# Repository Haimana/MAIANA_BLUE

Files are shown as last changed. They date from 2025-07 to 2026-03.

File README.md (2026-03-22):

# MAIANA BLUE

Firmware and hardware materials for the MAIANA-class AIS transponder ecosystem. The design builds on the open [MAIANA project](https://github.com/peterantypas/maiana) (GPL v3, Peter Antypas).

## In this repository

- **Firmware/** — AIS firmware (STM32CubeIDE tree and a **VS Code / PlatformIO** sibling), plus the N2K variant. Start with [Firmware/README.md](Firmware/README.md) for layout and build pointers.
- **CAD/** — STEP models (enclosures, antennas).
- **Manuals/** — Assembly and related documentation.
- **Schematics/** — Hardware reference drawings.

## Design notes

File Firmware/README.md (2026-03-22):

# Firmware layout

- **`Maiana_Blue_AIS_Firmware`** — Original AIS transponder tree (STM32CubeIDE / Eclipse-style project: `.ioc`, OpenOCD scripts). Kept for reference and existing workflows.

- **`Maiana_Blue_AIS_Firmware_VSCode_PlatformIO`** — Same application line built with **VS Code + PlatformIO** (`platformio.ini`). Use this tree for `pio run` / multi-environment builds. Build artifacts (`.pio/`) are ignored by git.

- **`Maiana_Blue_N2K_Firmware`** — N2K variant (unchanged).

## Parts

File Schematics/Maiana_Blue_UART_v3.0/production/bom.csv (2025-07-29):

Designator | Footprint | Quantity | Value | LCSC Part #
C1, C2 | 0603 | 2 | 1uF
C4, C5 | 0603 | 2 | 0.1uF
D1 | SMB-BIDIR | 1 | SMBJ14CA
D2 | SOD123 | 1 | WSB5508L-2/TR
D3 | SOD-323 | 1 | 3V
F1 | R1206 | 1 | BSMD1206-050-16V
J3 | USB_Micro-B_Amphenol_10118194-0001LF_Horizontal | 1 | 10118194-0001LF
R8 | 0603 | 1 | 75R
U$1 | SOIC-8 | 1 | CH340N
U1 | SOT23 | 1 | SE8533X2-HF

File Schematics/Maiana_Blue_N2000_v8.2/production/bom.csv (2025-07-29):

Designator | Footprint | Quantity | Value | LCSC Part #
C1, C11, C12, C13, C2, C3 | 0603 | 6 | 0.1uF
C10, C6, C7, C8, C9 | 0603 | 5 | 1uF
C4, C5 | 0603 | 2 | 20pF
D5 | SOT323 | 1 | PESD1CAN-U
D6 | DIOM4336X265N | 1 | SMBJ16CA
D8 | D_SOD-123 | 1 | D_Schottky
GPS1, PWR1, RX1, TX1 | 0805 | 4 | KT-0805G
J3 | USB_Micro-B_Amphenol_10118194_Horizontal | 1 | USB_B_Micro
Q1, Q3 | SOT-23 | 2 | BSS138
Q2 | SOT-23 | 1 | AO3401A
R1, R2, R3, R4 | 0603 | 4 | 2k2
R10, R5, R6, R7, R8, R9 | 0603 | 6 | 10k
R11, R12 | 0603 | 2 | 0R
S1, S2 | MS12D17G2 | 2 | MS-12D17-G2
S3 | SKSCLDE010 | 1 | SKSCLDE010
TH1 | 1206 | 1 | BSMD1206-050-16V
U1 | QFN-32-1EP_5x5mm_P0.5mm_EP3.45x3.45mm | 1 | STM32L432KBUx
U2 | TSSOP-20_4.4x6.5mm_P0.65mm | 1 | MCP2515-xST
U3 | SOIC-8_3.9x4.9mm_P1.27mm | 1 | MCP2551-I-SN
U4 | SOT-23-6 | 1 | SRV05-4
U5 | SO-8_3.9x4.9mm_P1.27mm | 1 | CH340N
U6 | SOIC-8_3.9x4.9mm_P1.27mm | 1 | ISO7721FDR
U7 | SOT-23-5 | 1 | TJ5205SF5-5.0
U8 | SOT-23 | 1 | SE8533X2-HF
Y1 | Crystal_SMD_3225-4Pin_3.2x2.5mm | 1 | X322516MOB4SI

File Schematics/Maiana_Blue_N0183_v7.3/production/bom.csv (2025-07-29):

Designator | Footprint | Quantity | Value | LCSC Part #
C1, C10, C11, C2, C3, C9 | 0603 | 6 | 0.1uF
C4, C5, C6, C7, C8 | 0603 | 5 | 1uF
D1 | D_SOD-123 | 1 | WSB5508L-2/TR
D2 | D_SMB | 1 | SMBJ16CA
GPS1, PWR1, RX1, TX1 | 0805 | 4 | KT-0805G
J1 | 1727036 | 1 | 1727036
J3 | USB_Micro-B_Amphenol_10118194_Horizontal | 1 | USB_B_Micro
J5 | RJ45_Amphenol_54602-x08_Horizontal | 1 | 54602-908LF
Q1 | SOT-23 | 1 | BSS138
Q2 | SOT-23 | 1 | AO3401A
R1, R2 | 0603 | 2 | 10k
R10, R11, R12, R9 | 0603 | 4 | 2k2
S3, S4 | MS12D17G2 | 2 | MS-12D17-G2
TH1 | 1206 | 1 | Thermistor_PTC
U1 | SOT-23-6 | 1 | SRV05-4
U2 | SO-8_3.9x4.9mm_P1.27mm | 1 | CH340N
U3 | SOIC-8_3.9x4.9mm_P1.27mm | 1 | ADuM121N
U4 | SOT-23-5 | 1 | TJ5205SF5-5.0
U5 | SOT-23 | 1 | SE8533X2-HF
U6 | SOIC-8_3.9x4.9mm_P1.27mm | 1 | DS8921M

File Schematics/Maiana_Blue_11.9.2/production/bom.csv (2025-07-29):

Designator | Footprint | Quantity | Value | LCSC Part #
AE1 | ANT_1575AT_JOT | 1 | 1575AT43A0040E
C1, C2, C8, C9 | 0603 | 4 | 0.1uf
C12, C16, C17, C21, C29, C5 | 0603 | 6 | 22nF
C13, C14, C15, C4, C7 | 0603 | 5 | 2.2uF
C18, C19, C24 | 0603 | 3 | 91pF
C20, C22, C30, C35 | 0603 | 4 | 2.2nF
C23, C25 | 0603 | 2 | 3.3pF
C26 | 0603 | 1 | 20pF
C27, C32 | 0603 | 2 | 470pF
C28 | 0603 | 1 | 16pF
C3 | 0805 | 1 | 10uF
C31, C33 | 0603 | 2 | 110pF
C34 | 0603 | 1 | 36pF
C6 | 0805 | 1 | 22uF
CR1 | U-DFN3810-9TYPE_B_DIO | 1 | D3V3X8U9LP3810-7
D1, D2, D3 | D_SOD-323 | 3 | BAT54WS
IC1 | SON65P200X200X100-7N-D | 1 | LDFPVR
J1 | RJ45_Amphenol_54602-x08_Horizontal | 1 | RJ45
J3 | RFSOLUTIONS_CON-SMA-EDGE-S | 1 | CON-SMA-EDGE-S
L1, L2 | 0805 | 2 | 4.7uH
L10 | 0603 | 1 | 20nH
L11, L7 | 0603 | 2 | 470nH
L12 | 0805 | 1 | 2.2uH
L13 | 0603 | 1 | 13nH
L14 | 0603 | 1 | 39nH
L3 | 0603 | 1 | 5.6nH
L4, L6 | 0603 | 2 | 270nH
L5 | 0603 | 1 | 10nH
L8 | 0603 | 1 | 47nH
L9 | 0603 | 1 | 68nH
Q1 | SOT-23 | 1 | AO3409
Q2 | SOT-23 | 1 | AO3401A
Q3 | SOT-89-3 | 1 | AFT05MS004NT1
R1, R2, R3 | 0603 | 3 | 100R
R10 | 0603 | 1 | 47k
R11, R12, R13, R18, R4 | 0603 | 5 | 10k
R14 | 0603 | 1 | 0
R15 | 0603 | 1 | 220R
R16 | 0603 | 1 | 22R
R17 | 0603 | 1 | 3k3
R5, R6, R7 | 0603 | 3 | 1k
R8 | 0603 | 1 | 51k
R9 | 0603 | 1 | 16k
TP1, TP10, TP11, TP12, TP14, TP15, TP16, TP17, TP18, TP19, TP2, TP3, TP4, TP5, TP6, TP7, TP8, TP9 | TP_1.2MM | 18 | ~
TP13 | TP_1.0MM | 1 | ~
U1, U2 | SOT-363_SC-70-6 | 2 | SI1926DL-T1-E3
U10 | QFN50P200X200X65-13N | 1 | SKY13330-397LF
U3 | SOT-23-6 | 1 | AP3211K
U4 | SOT-23-5 | 1 | 24LC01BT/OT
U5 | QFN-32-1EP_5x5mm_P0.5mm_EP3.45x3.45mm | 1 | STM32L432KBUx
U6 | XCVR_L76L-M33 | 1 | L76L-M33
U7, U8 | QFN-20-1EP_4x4mm_P0.5mm_EP2.6x2.6mm_ThermalVias | 2 | Si4460
U9 | SOT-363_SC-70-6 | 1 | BGA2800,115
Y1, Y2 | Crystal_SMD_3225-4Pin_3.2x2.5mm | 2 | ECS-300-10-33B-CKM-TR

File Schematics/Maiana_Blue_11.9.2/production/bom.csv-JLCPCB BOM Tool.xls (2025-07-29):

JLCPCB BOM Tool - BOM Matching
BOM name：bom_base_11.9.2-JLCPCB Assembly Order.xlsx |  |  |  | Download Time：2025-05-29 18:24:59 |  |  |  | * Our matching results are updated in real-time, but stock and prices may change. If it's been over 24 hours, please re-match before placing your order.
PCB Assembled Qty：25 |  |  |  | Est. Total Price：731.6358 (Pre-order parts require a quotation for final pricing.)
Your BOM |  |  |  | Matched Parts |  |  |  |  |  |  | Order Information
Designator | Comment | Footprint | JLCPCB Part # | Matches | Part # | Manufacturer | Footprint | Description | Category | Warning | JLCPCB Part # | Product link | Source | Lib Type | MOQ | Availability | My Parts(JLCPCB Parts) | My Parts(Global sourcing & consigned parts) | Rec. Order Qty | Unit Price ($) | Total Price ($)
C26 | 20pF | 0603 |  | Unconfirmed | CL10C200JB8NNNC | Samsung Electro-Mechanics | 0603 | 50V 20pF C0G ±5% 0603 Multilayer Ceramic Capacitors MLCC - SMD/SMT ROHS | Multilayer Ceramic Capacitors MLCC - SMD/SMT | 1.The comment (CL10C200JB8NNNC) of this part does not match the one (20pF) provided in your BOM. Please confirm; | C1648 | https://jlcpcb.com/partdetail/2000-CL10C200JB8NNNC/C1648 | In-stock | Basic | 1 | 781306 | 0 | 0 | 35 | 0.0054 | 0.189
R16 | 22R | 0603 |  | Unconfirmed | 0603WAF220JT5E | UNI-ROYAL(Uniroyal Elec) | 0603 | 100mW Thick Film Resistors 75V ±100ppm/℃ ±1% 22Ω 0603 Chip Resistor - Surface Mount ROHS | Chip Resistor - Surface Mount | 1.The comment (0603WAF220JT5E) of this part does not match the one (22R) provided in your BOM. Please confirm; | C23345 | https://jlcpcb.com/partdetail/24078-0603WAF220JT5E/C23345 | In-stock | Basic | 1 | 2988484 | 0 | 0 | 35 | 0.0009 | 0.0315
C3 | 10uF | 0805 |  | Unconfirmed | CL21A106KAYNNNE | Samsung Electro-Mechanics | 0805 | 25V 10uF X5R ±10% 0805 Multilayer Ceramic Capacitors MLCC - SMD/SMT ROHS | Multilayer Ceramic Capacitors MLCC - SMD/SMT | 1.The comment (CL21A106KAYNNNE) of this part does not match the one (10uF) provided in your BOM. Please confirm; | C15850 | https://jlcpcb.com/partdetail/16532-CL21A106KAYNNNE/C15850 | In-stock | Basic | 1 | 7327774 | 0 | 0 | 35 | 0.0106 | 0.371
U4 | 24LC01BT/OT | SOT-23-5 |  | Unconfirmed | 24LC01BT-I/OT | Microchip Tech | SOT-23-5 | 1Kbit I2C SOT-23-5 EEPROM ROHS | EEPROM | 1.The comment (24LC01BT-I/OT) of this part does not match the one (24LC01BT/OT) provided in your BOM. Please confirm; | C511269 | https://jlcpcb.com/partdetail/MicrochipTech-24LC01BT_IOT/C511269 | In-stock | Extended | 1 | 3500 | 0 | 0 | 25 | 0.3381 | 8.4525
U3 | AP3211K | SOT-23-6 |  | Unconfirmed | AP3211KTR-G1 | Diodes Incorporated | SOT-23-6 | Step-down type Adjustable 810mV~15V 1.5A 4.5V~18V SOT-23-6 DC-DC Converters ROHS | DC-DC Converters | 1.The comment (AP3211KTR-G1) of this part does not match the one (AP3211K) provided in your BOM. Please confirm; | C154863 | https://jlcpcb.com/partdetail/DiodesIncorporated-AP3211KTRG1/C154863 | In-stock | Extended | 1 | 3015 | 0 | 0 | 25 | 0.17 | 4.25
C23,C25 | 3.3pF | 0603 |  | Unconfirmed | 0603CG3R3C500NT | FH (Guangdong Fenghua Advanced Tech) | 0603 | 50V 3.3pF C0G 0603 Multilayer Ceramic Capacitors MLCC - SMD/SMT ROHS | Multilayer Ceramic Capacitors MLCC - SMD/SMT | 1.The comment (0603CG3R3C500NT) of this part does not match the one (3.3pF) provided in your BOM. Please confirm; | C1660 | https://jlcpcb.com/partdetail/2012-0603CG3R3C500NT/C1660 | In-stock | Extended | 1 | 95763 | 0 | 0 | 60 | 0.0028 | 0.168
L4,L6 | 270nH | 0603 |  | Select by Customer | LQW18ANR27G00D | Murata Electronics | 0603 | 110mA 270nH ±2% 0603 Power Inductors ROHS | Power Inductors | 1.The comment (LQW18ANR27G00D) of this part does not match the one (270nH) provided in your BOM. Please confirm; | C98092 | https://jlcpcb.com/partdetail/MurataElectronics-LQW18ANR27G00D/C98092 | In-stock | Extended | 1 | 2820 | 0 | 0 | 54 | 0.0356 | 1.9224
L12 | 2.2uH | 0805 |  | Unconfirmed | LQM21PN2R2NGCD | Murata Electronics | 0805 | 800mA 2.2uH ±30% 288mΩ 0805 Inductors (SMD) ROHS | Inductors (SMD) | 1.The comment (LQM21PN2R2NGCD) of this part does not match the one (2.2uH) provided in your BOM. Please confirm; | C86089 | https://jlcpcb.com/partdetail/MurataElectronics-LQM21PN2R2NGCD/C86089 | In-stock | Extended | 1 | 2622 | 0 | 0 | 29 | 0.0593 | 1.7197
L1,L2 | 4.7uH | 0805 |  | Unconfirmed | LQM21PN4R7MGRD | Murata Electronics | 0805 | 800mA 4.7uH ±20% 288mΩ 0805 Inductors (SMD) ROHS | Inductors (SMD) | 1.The comment (LQM21PN4R7MGRD) of this part does not match the one (4.7uH) provided in your BOM. Please confirm; | C86090 | https://jlcpcb.com/partdetail/MurataElectronics-LQM21PN4R7MGRD/C86090 | In-stock | Extended | 1 | 13173 | 0 | 0 | 54 | 0.0687 | 3.7098
C18,C19,C24 | 91pF | 0603 |  | Unconfirmed | 0603CG910J500NT | FH (Guangdong Fenghua Advanced Tech) | 0603 | 50V 91pF C0G ±5% 0603 Multilayer Ceramic Capacitors MLCC - SMD/SMT ROHS | Multilayer Ceramic Capacitors MLCC - SMD/SMT | 1.The comment (0603CG910J500NT) of this part does not match the one (91pF) provided in your BOM. Please confirm; | C1686 | https://jlcpcb.com/partdetail/2038-0603CG910J500NT/C1686 | In-stock | Extended | 1 | 3912 | 0 | 0 | 85 | 0.0033 | 0.2805
U1,U2 | SI1926DL-T1-E3 | SOT-363_SC-70-6 |  | Select by System | SI1926DL-T1-E3 | Vishay Intertech | SOT-363_SC-70-6 | 60V 370mA 1.4Ω@340mA,10V 510mW 2.5V@250uA 2 N-Channel SOT-363-6 MOSFETs ROHS | MOSFETs |  | C727310 | https://jlcpcb.com/partdetail/VishayIntertech-SI1926DL_T1E3/C727310 | In-stock | Extended | 1 | 198 | 0 | 0 | 50 | 0.2211 | 11.055
R5,R6,R7 | 1k | 0603 |  | Unconfirmed | 0603WAF1001T5E | UNI-ROYAL(Uniroyal Elec) | 0603 | 100mW Thick Film Resistors 75V ±100ppm/℃ ±1% 1kΩ 0603 Chip Resistor - Surface Mount ROHS | Chip Resistor - Surface Mount | 1.The comment (0603WAF1001T5E) of this part does not match the one (1k) provided in your BOM. Please confirm; | C21190 | https://jlcpcb.com/partdetail/21904-0603WAF1001T5E/C21190 | In-stock | Basic | 1 | 20095357 | 0 | 0 | 85 | 0.001 | 0.085
C20,C22,C30,C35 | 2.2nF | 0603 |  | Unconfirmed | 0603B222K500NT | FH (Guangdong Fenghua Advanced Tech) | 0603 | 50V 2.2nF X7R ±10% 0603 Multilayer Ceramic Capacitors MLCC - SMD/SMT ROHS | Multilayer Ceramic Capacitors MLCC - SMD/SMT | 1.The comment (0603B222K500NT) of this part does not match the one (2.2nF) provided in your BOM. Please confirm; | C1604 | https://jlcpcb.com/partdetail/1956-0603B222K500NT/C1604 | In-stock | Basic | 1 | 957178 | 0 | 0 | 110 | 0.0026 | 0.286
C6 | 22uF | 0805 |  | Unconfirmed | CL21A226MAQNNNE | Samsung Electro-Mechanics | 0805 | 25V 22uF X5R ±20% 0805 Multilayer Ceramic Capacitors MLCC - SMD/SMT ROHS | Multilayer Ceramic Capacitors MLCC - SMD/SMT | 1.The comment (CL21A226MAQNNNE) of this part does not match the one (22uF) provided in your BOM. Please confirm; | C45783 | https://jlcpcb.com/partdetail/46786-CL21A226MAQNNNE/C45783 | In-stock | Basic | 1 | 1402442 | 0 | 0 | 33 | 0.027 | 0.891
R8 | 51k | 0603 |  | Unconfirmed | 0603WAF5102T5E | UNI-ROYAL(Uniroyal Elec) | 0603 | 100mW Thick Film Resistors 75V ±100ppm/℃ ±1% 51kΩ 0603 Chip Resistor - Surface Mount ROHS | Chip Resistor - Surface Mount | 1.The comment (0603WAF5102T5E) of this part does not match the one (51k) provided in your BOM. Please confirm; | C23196 | https://jlcpcb.com/partdetail/23923-0603WAF5102T5E/C23196 | In-stock | Basic | 1 | 3648305 | 0 | 0 | 35 | 0.001 | 0.035
L8 | 47nH | 0603 |  | Unconfirmed | LQW18AN47NG00D | Murata Electronics | 0603 | 380mA 47nH ±2% 0603 Power Inductors ROHS | Power Inductors | 1.The comment (LQW18AN47NG00D) of this part does not match the one (47nH) provided in your BOM. Please confirm; | C98076 | https://jlcpcb.com/partdetail/MurataElectronics-LQW18AN47NG00D/C98076 | In-stock | Extended | 1 | 19109 | 0 | 0 | 29 | 0.0399 | 1.1571
R14 | 0 | 0603 |  | Unconfirmed | 0603WAF0000T5E | UNI-ROYAL(Uniroyal Elec) | 0603 | 100mW Thick Film Resistors 75V ±1% 0Ω 0603 Chip Resistor - Surface Mount ROHS | Chip Resistor - Surface Mount | 1.The comment (0603WAF0000T5E) of this part does not match the one (0) provided in your BOM. Please confirm; | C21189 | https://jlcpcb.com/partdetail/21903-0603WAF0000T5E/C21189 | In-stock | Basic | 1 | 15465613 | 0 | 0 | 35 | 0.001 | 0.035
L13 | 13nH | 0603 |  | Unconfirmed | LQW18AN13NG00D | Murata Electronics | 0603 | 600mA 13nH ±2% 0603 Power Inductors ROHS | Power Inductors | 1.The comment (LQW18AN13NG00D) of this part does not match the one (13nH) provided in your BOM. Please confirm; | C701184 | https://jlcpcb.com/partdetail/MurataElectronics-LQW18AN13NG00D/C701184 | In-stock | Extended | 1 | 2781 | 0 | 0 | 29 | 0.036 | 1.044
L5 | 10nH | 0603 |  | Unconfirmed | LQW18AN10NG00D | Murata Electronics | 0603 | 650mA 10nH ±2% 0603 Power Inductors ROHS | Power Inductors | 1.The comment (LQW18AN10NG00D) of this part does not match the one (10nH) provided in your BOM. Please confirm; | C86131 | https://jlcpcb.com/partdetail/MurataElectronics-LQW18AN10NG00D/C86131 | In-stock | Extended | 1 | 95789 | 0 | 0 | 29 | 0.0359 | 1.0411
R15 | 220R | 0603 |  | Unconfirmed | 0603WAF2200T5E | UNI-ROYAL(Uniroyal Elec) | 0603 | 100mW Thick Film Resistors 75V ±100ppm/℃ ±1% 220Ω 0603 Chip Resistor - Surface Mount ROHS | Chip Resistor - Surface Mount | 1.The comment (0603WAF2200T5E) of this part does not match the one (220R) provided in your BOM. Please confirm; | C22962 | https://jlcpcb.com/partdetail/23689-0603WAF2200T5E/C22962 | In-stock | Basic | 1 | 1267513 | 0 | 0 | 35 | 0.0011 | 0.0385
Q1 | AO3409 | SOT-23 |  | Select by System | AO3409 | Alpha & Omega Semicon | SOT-23 | 30V 2.6A 130mΩ@10V,2.6A 1.4W 3V@250uA 1 Piece P-Channel SOT-23 MOSFETs ROHS | MOSFETs |  | C88052 | https://jlcpcb.com/partdetail/Alpha_OmegaSemicon-AO3409/C88052 | In-stock | Extended | 1 | 905 | 0 | 0 | 27 | 0.0761 | 2.0547
C28 | 16pF | 0603 |  | Unconfirmed | CC0603JRNPO9BN160 | YAGEO | 0603 | 50V 16pF NP0 ±5% 0603 Multilayer Ceramic Capacitors MLCC - SMD/SMT ROHS | Multilayer Ceramic Capacitors MLCC - SMD/SMT | 1.The comment (CC0603JRNPO9BN160) of this part does not match the one (16pF) provided in your BOM. Please confirm; | C327125 | https://jlcpcb.com/partdetail/YAGEO-CC0603JRNPO9BN160/C327125 | In-stock | Extended | 1 | 120909 | 0 | 0 | 35 | 0.0029 | 0.1015
C27,C32 | 470pF | 0603 |  | Unconfirmed | 0603B471K500NT | FH (Guangdong Fenghua Advanced Tech) | 0603 | 50V 470pF X7R ±10% 0603 Multilayer Ceramic Capacitors MLCC - SMD/SMT ROHS | Multilayer Ceramic Capacitors MLCC - SMD/SMT | 1.The comment (0603B471K500NT) of this part does not match the one (470pF) provided in your BOM. Please confirm; | C1620 | https://jlcpcb.com/partdetail/1972-0603B471K500NT/C1620 | In-stock | Basic | 1 | 533202 | 0 | 0 | 60 | 0.0027 | 0.162
U5 | STM32L432KBUx | QFN-32-1EP_5x5mm_P0.5mm_EP3.45x3.45mm |  | Select by System | STM32L432KBU6 | STMicroelectronics | QFN-32-1EP_5x5mm_P0.5mm_EP3.45x3.45mm | 128KB 1.71V~3.6V ARM-M4 64KB 80MHz FLASH 26 UFQFPN-32(5x5) Microcontrollers (MCU/MPU/SOC) ROHS | Microcontrollers (MCU/MPU/SOC) |  | C94784 | https://jlcpcb.com/partdetail/STMicroelectronics-STM32L432KBU6/C94784 | In-stock | Extended | 1 | 5178 | 0 | 0 | 25 | 2.4135 | 60.3375
L11,L7 | 470nH | 0603 |  | Unconfirmed | LQW18ANR47G00D | Murata Electronics | 0603 | 75mA 470nH ±2% 0603 Power Inductors ROHS | Power Inductors | 1.The comment (LQW18ANR47G00D) of this part does not match the one (470nH) provided in your BOM. Please confirm; | C113132 | https://jlcpcb.com/partdetail/MurataElectronics-LQW18ANR47G00D/C113132 | In-stock | Extended | 1 | 1604 | 0 | 0 | 54 | 0.0413 | 2.2302
C31,C33 | 110pF | 0603 |  | Unconfirmed | CC0603GRNPO9BN111 | YAGEO | 0603 | 50V 110pF NP0 ±2% 0603 Multilayer Ceramic Capacitors MLCC - SMD/SMT ROHS | Multilayer Ceramic Capacitors MLCC - SMD/SMT | 1.The comment (CC0603GRNPO9BN111) of this part does not match the one (110pF) provided in your BOM. Please confirm; | C519475 | https://jlcpcb.com/partdetail/YAGEO-CC0603GRNPO9BN111/C519475 | In-stock | Extended | 1 | 3700 | 0 | 0 | 60 | 0.0084 | 0.504
R10 | 47k | 0603 |  | Unconfirmed | 0603WAF4702T5E | UNI-ROYAL(Uniroyal Elec) | 0603 | 100mW Thick Film Resistors 75V ±100ppm/℃ ±1% 47kΩ 0603 Chip Resistor - Surface Mount ROHS | Chip Resistor - Surface Mount | 1.The comment (0603WAF4702T5E) of this part does not match the one (47k) provided in your BOM. Please confirm; | C25819 | https://jlcpcb.com/partdetail/26562-0603WAF4702T5E/C25819 | In-stock | Basic | 1 | 2708507 | 0 | 0 | 35 | 0.001 | 0.035
C1,C2,C8,C9 | 0.1uf | 0603 |  | Unconfirmed | CC0603KRX7R9BB104 | YAGEO | 0603 | 50V 100nF X7R ±10% 0603 Multilayer Ceramic Capacitors MLCC - SMD/SMT ROHS | Multilayer Ceramic Capacitors MLCC - SMD/SMT | 1.The comment (CC0603KRX7R9BB104) of this part does not match the one (0.1uf) provided in your BOM. Please confirm; | C14663 | https://jlcpcb.com/partdetail/YAGEO-CC0603KRX7R9BB104/C14663 | In-stock | Basic | 1 | 60066178 | 0 | 0 | 110 | 0.0024 | 0.264
CR1 | D3V3X8U9LP3810-7 | U-DFN3810-9TYPE_B_DIO |  | Select by System | D3V3X8U9LP3810-7 | Diodes Incorporated | U-DFN3810-9TYPE_B_DIO | 3A@(8/20us) 20W 7V 5.5V 3.3V UDFN3810-9 ESD and Surge Protection (TVS/ESD) ROHS | ESD and Surge Protection (TVS/ESD) |  | C1973794 | https://jlcpcb.com/partdetail/DiodesIncorporated-D3V3X8U9LP38107/C1973794 | In-stock | Extended | 1 | 1709 | 0 | 0 | 25 | 0.1646 | 4.115
Q3 | AFT05MS004NT1 | SOT-89-3 |  | Select by System | AFT05MS004NT1 | NXP Semicon | SOT-89-3 | 4.9W SOT-89-3 MOSFETs ROHS | MOSFETs |  | C713822 | https://jlcpcb.com/partdetail/NXPSemicon-AFT05MS004NT1/C713822 | In-stock | Extended | 1 | 993 | 0 | 0 | 37 | 1.941 | 71.817
C12,C16,C17,C21,C29,C5 | 22nF | 0603 |  | Unconfirmed | CL10B223KB8NNNC | Samsung Electro-Mechanics | 0603 | 50V 22nF X7R ±10% 0603 Multilayer Ceramic Capacitors MLCC - SMD/SMT ROHS | Multilayer Ceramic Capacitors MLCC - SMD/SMT | 1.The comment (CL10B223KB8NNNC) of this part does not match the one (22nF) provided in your BOM. Please confirm; | C21122 | https://jlcpcb.com/partdetail/21834-CL10B223KB8NNNC/C21122 | In-stock | Basic | 1 | 1155481 | 0 | 0 | 160 | 0.0038 | 0.608
C13,C14,C15,C4,C7 | 2.2uF | 0603 |  | Unconfirmed | CL10A225KO8NNNC | Samsung Electro-Mechanics | 0603 | 16V 2.2uF X5R ±10% 0603 Multilayer Ceramic Capacitors MLCC - SMD/SMT ROHS | Multilayer Ceramic Capacitors MLCC - SMD/SMT | 1.The comment (CL10A225KO8NNNC) of this part does not match the one (2.2uF) provided in your BOM. Please confirm; | C23630 | https://jlcpcb.com/partdetail/24366-CL10A225KO8NNNC/C23630 | In-stock | Basic | 1 | 1418192 | 0 | 0 | 135 | 0.0062 | 0.837
Q2 | AO3401A | SOT-23 |  | Select by System | AO3401A | Alpha & Omega Semicon | SOT-23 | 30V 4A 44mΩ@10V,4.3A 1.4W 1.3V@250uA 1 Piece P-Channel SOT-23 MOSFETs ROHS | MOSFETs |  | C15127 | https://jlcpcb.com/partdetail/Alpha_OmegaSemicon-AO3401A/C15127 | In-stock | Basic | 1 | 1366207 | 0 | 0 | 29 | 0.0531 | 1.5399
L9 | 68nH | 0603 |  | Unconfirmed | LQW18AN68NG00D | Murata Electronics | 0603 | 340mA 68nH ±2% 0603 Power Inductors ROHS | Power Inductors | 1.The comment (LQW18AN68NG00D) of this part does not match the one (68nH) provided in your BOM. Please confirm; | C86135 | https://jlcpcb.com/partdetail/MurataElectronics-LQW18AN68NG00D/C86135 | In-stock | Extended | 1 | 22434 | 0 | 0 | 29 | 0.0371 | 1.0759
R17 | 3k3 | 0603 |  | Unconfirmed | 0603WAF3301T5E | UNI-ROYAL(Uniroyal Elec) | 0603 | 100mW Thick Film Resistors 75V ±100ppm/℃ ±1% 3.3kΩ 0603 Chip Resistor - Surface Mount ROHS | Chip Resistor - Surface Mount | 1.The comment (0603WAF3301T5E) of this part does not match the one (3k3) provided in your BOM. Please confirm; | C22978 | https://jlcpcb.com/partdetail/23705-0603WAF3301T5E/C22978 | In-stock | Basic | 1 | 4564908 | 0 | 0 | 35 | 0.0009 | 0.0315
R9 | 16k | 0603 |  | Unconfirmed | 0603WAF1602T5E | UNI-ROYAL(Uniroyal Elec) | 0603 | 100mW Thick Film Resistors 75V ±100ppm/℃ ±1% 16kΩ 0603 Chip Resistor - Surface Mount ROHS | Chip Resistor - Surface Mount | 1.The comment (0603WAF1602T5E) of this part does not match the one (16k) provided in your BOM. Please confirm; | C4210 | https://jlcpcb.com/partdetail/4617-0603WAF1602T5E/C4210 | In-stock | Extended | 1 | 320545 | 0 | 0 | 35 | 0.001 | 0.035
R11,R12,R13,R18,R4 | 10k | 0603 |  | Unconfirmed | 0603WAF1002T5E | UNI-ROYAL(Uniroyal Elec) | 0603 | 100mW Thick Film Resistors 75V ±100ppm/℃ ±1% 10kΩ 0603 Chip Resistor - Surface Mount ROHS | Chip Resistor - Surface Mount | 1.The comment (0603WAF1002T5E) of this part does not match the one (10k) provided in your BOM. Please confirm; | C25804 | https://jlcpcb.com/partdetail/26547-0603WAF1002T5E/C25804 | In-stock | Basic | 1 | 23031840 | 0 | 0 | 135 | 0.0009 | 0.1215
Y1,Y2 | ECS-300-10-33B-CKM-TR | Crystal_SMD_3225-4Pin_3.2x2.5mm |  | Unconfirmed | TXM30M0004322DBCDO00T | Yajingxin | Crystal_SMD_3225-4Pin_3.2x2.5mm | 30MHz SMD crystal oscillator 10pF ±10ppm ±20ppm SMD3225-4P Crystals ROHS | Crystals | 1.The comment (TXM30M0004322DBCDO00T) of this part does not match the one (ECS-300-10-33B-CKM-TR) provided in your BOM. Please confirm; | C362347 | https://jlcpcb.com/partdetail/Yajingxin-TXM30M0004322DBCDO00T/C362347 | In-stock | Extended | 1 | 1238 | 0 | 0 | 54 | 0.0614 | 3.3156
L3 | 5.6nH | 0603 |  | Unconfirmed | LQW18AN5N6C00D | Murata Electronics | 0603 | 750mA 5.6nH 0603 Power Inductors ROHS | Power Inductors | 1.The comment (LQW18AN5N6C00D) of this part does not match the one (5.6nH) provided in your BOM. Please confirm; | C98081 | https://jlcpcb.com/partdetail/MurataElectronics-LQW18AN5N6C00D/C98081 | In-stock | Extended | 1 | 3707 | 0 | 0 | 29 | 0.0356 | 1.0324
D1,D2,D3 | BAT54WS | D_SOD-323 |  | Select by System | BAT54WS | hongjiacheng | D_SOD-323 | 30V Independent Type 200mA 1V@100mA SOD-323 Schottky Diodes ROHS | Schottky Diodes |  | C7502694 | https://jlcpcb.com/partdetail/hongjiacheng-BAT54WS/C7502694 | In-stock | Extended | 1 | 93618 | 0 | 0 | 81 | 0.0109 | 0.8829
R1,R2,R3 | 100R | 0603 |  | Unconfirmed | 0603WAF1000T5E | UNI-ROYAL(Uniroyal Elec) | 0603 | 100mW Thick Film Resistors 75V ±1% ±200ppm/℃ 100Ω 0603 Chip Resistor - Surface Mount ROHS | Chip Resistor - Surface Mount | 1.The comment (0603WAF1000T5E) of this part does not match the one (100R) provided in your BOM. Please confirm; | C22775 | https://jlcpcb.com/partdetail/23502-0603WAF1000T5E/C22775 | In-stock | Basic | 1 | 8579877 | 0 | 0 | 85 | 0.001 | 0.085
L14 | 39nH | 0603 |  | Unconfirmed | LQW18AN39NJ00D | Murata Electronics | 0603 | 400mA 39nH ±5% 0603 Power Inductors ROHS | Power Inductors | 1.The comment (LQW18AN39NJ00D) of this part does not match the one (39nH) provided in your BOM. Please confirm; | C98075 | https://jlcpcb.com/partdetail/MurataElectronics-LQW18AN39NJ00D/C98075 | In-stock | Extended | 1 | 3661 | 0 | 0 | 29 | 0.0383 | 1.1107
U7,U8 | Si4460 | QFN-20-1EP_4x4mm_P0.5mm_EP2.6x2.6mm_ThermalVias |  | Unconfirmed | SI4460-C2A-GMR | SKYWORKS/SILICON LABS | QFN-20-1EP_4x4mm_P0.5mm_EP2.6x2.6mm_ThermalVias | 1Mbps General-purposeISM<1GHz SPI QFN-20-EP(4x4) RF Transceiver ICs ROHS | RF Transceiver ICs | 1.The comment (SI4460-C2A-GMR) of this part does not match the one (Si4460) provided in your BOM. Please confirm; | C2151590 | https://jlcpcb.com/partdetail/SKYWORKS_SILICONLABS-SI4460_C2AGMR/C2151590 | In-stock | Extended | 1 | 1676 | 0 | 0 | 50 | 1.7625 | 88.125
L10 | 20nH | 0603 |  | Unconfirmed | LQW18AN20NG00D | Murata Electronics | 0603 | 550mA 20nH ±2% 0603 Power Inductors ROHS | Power Inductors | 1.The comment (LQW18AN20NG00D) of this part does not match the one (20nH) provided in your BOM. Please confirm; | C77124 | https://jlcpcb.com/partdetail/MurataElectronics-LQW18AN20NG00D/C77124 | In-stock | Extended | 1 | 4057 | 0 | 0 | 29 | 0.0401 | 1.1629
U6 | L76L-M33 | XCVR_L76L-M33 |  | Select by System | L76L-M33 | Quectel | XCVR_L76L-M33 | Navigation BeiDou, Galileo, GLONASS, GPS, GNSS Transceiver Module 1.561GHz, 1.575GHz, 1.602GHz Antenna Not Included Surface Mount | GNSS Modules |  | C2916232 | https://jlcpcb.com/partdetail/Quectel-L76LM33/C2916232 | In-stock | Extended | 1 | 418 | 0 | 0 | 25 | 5.5905 | 139.7625
U10 | SKY13330-397LF | QFN50P200X200X65-13N |  | Select by System | SKY13330-397LF | Skyworks Solutions | QFN50P200X200X65-13N | QFN-12-EP(2x2) RF Switches ROHS | RF Switches |  | C2654715 | https://jlcpcb.com/partdetail/SkyworksSolutions-SKY13330397LF/C2654715 | In-stock | Extended | 1 | 2875 | 0 | 0 | 25 | 0.741 | 18.525
C34 | 36pF | 0603 |  | Unconfirmed | CC0603JRNPO9BN360 | YAGEO | 0603 | 50V 36pF NP0 ±5% 0603 Multilayer Ceramic Capacitors MLCC - SMD/SMT ROHS | Multilayer Ceramic Capacitors MLCC - SMD/SMT | 1.The comment (CC0603JRNPO9BN360) of this part does not match the one (36pF) provided in your BOM. Please confirm; | C134070 | https://jlcpcb.com/partdetail/YAGEO-CC0603JRNPO9BN360/C134070 | In-stock | Extended | 1 | 20283 | 0 | 0 | 35 | 0.003 | 0.105
IC1 | LDFPVR | SON65P200X200X100-7N-D |  | Select by System | LDFPVR | STMicroelectronics | SON65P200X200X100-7N-D | 1A Adjustable 800mV~12V Positive electrode 16V DFN-6(2x2) Voltage Regulators - Linear, Low Drop Out (LDO) Regulators ROHS | Voltage Regulators - Linear, Low Drop Out (LDO) Regulators |  | C2969978 | https://jlcpcb.com/partdetail/STMicroelectronics-LDFPVR/C2969978 | Pre-order | Extended | 87 | 0 | 0 | 0 | 87 | 0.864 | 75.168
U9 | BGA2800,115 | SOT-363_SC-70-6 |  | Select by System | BGA2800,115 | NXP Semicon | SOT-363_SC-70-6 | RF Amplifier IC General Purpose 0Hz ~ 2.2GHz 6-TSSOP | RF Amplifiers |  | C2654213 | https://jlcpcb.com/partdetail/NXPSemicon-BGA2800115/C2654213 | Pre-order | Extended | 142 | 0 | 0 | 0 | 142 | 0.462 | 65.604
AE1 | 1575AT43A0040E | ANT_1575AT_JOT |  | Select by System | 1575AT43A0040E | Johanson Dielectrics | ANT_1575AT_JOT | - Antennas | Antennas |  | C5872825 | https://jlcpcb.com/partdetail/JohansonDielectrics-1575AT43A0040E/C5872825 |  | Extended | 0 | 0 | 0 | 0 | 25 | 1.476 | 36.9
J1 | RJ45 | RJ45_Amphenol_54602-x08_Horizontal |  | Select by System | 54602-908LF | Amphenol ICC | RJ45_Amphenol_54602-x08_Horizontal | Unshielded 1 cat3 Gold Copper Alloy Without LED -40℃~+70℃ Plugin Ethernet Connectors / Modular Connectors (RJ45 RJ11) ROHS | Ethernet Connectors / Modular Connectors (RJ45 RJ11) |  | C2847314 | https://jlcpcb.com/partdetail/AmphenolICC-54602908LF/C2847314 |  | Extended | 0 | 2995 | 0 | 0 | 25 | 0.507 | 12.675
J3 | CON-SMA-EDGE-S | RFSOLUTIONS_CON-SMA-EDGE-S |  | Select by System | CON-SMA-EDGE-S | RF Solutions | RFSOLUTIONS_CON-SMA-EDGE-S | SMA FEMALE CONNECTOR, PCB EDGE MOUNT | Coaxial Connectors (RF) |  | C5356059 | https://jlcpcb.com/partdetail/RFSolutions-CON_SMA_EDGES/C5356059 |  | Extended | 0 | 0 | 0 | 0 | 25 | 4.182 | 104.55
TP13 | ~ | TP_1.0MM |  | No matches |  | No Part Selected
TP1,TP10,TP11,TP12,TP14,TP15,TP16,TP17,TP18,TP19,TP2,TP3,TP4,TP5,TP6,TP7,TP8,TP9 | ~ | TP_1.2MM |  | No matches |  | No Part Selected

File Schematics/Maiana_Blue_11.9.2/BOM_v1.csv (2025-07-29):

Id | Designator | Footprint | Quantity | Designation | Supplier and ref
1 | C35,C25,C34,C26 | C_0603_1608Metric | 4 | 0.1uf
2 | C6,C8,C12 | C_0603_1608Metric | 3 | 91pF
3 | TP18,TP6,TP15,TP5,TP2,TP7,TP12,TP9,TP11,TP19,TP8,TP10,TP16,TP17,TP4,TP13,TP14,TP3 | TP_1.2MM | 18 | ~
4 | U3 | SOT-363_SC-70-6 | 1 | BGA2800,115
5 | C15 | C_0603_1608Metric | 1 | 36pF
6 | IC1 | SON65P200X200X100-7N-D | 1 | LDFPVR
7 | C19,C27,C9,C3,C31,C11 | C_0603_1608Metric | 6 | 22nF
8 | C21 | C_0603_1608Metric | 1 | 20pF
9 | L13,L12 | R_0805_2012Metric | 2 | 4.7uH
10 | C16,C1,C18,C2 | C_0603_1608Metric | 4 | 2.2nF
11 | U8 | QFN50P200X200X65-13N | 1 | SKY13330-397LF
12 | C20,C13 | C_0603_1608Metric | 2 | 470pF
13 | L4 | L_0805_2012Metric | 1 | 2.2uH
14 | R5 | R_0603_1608Metric | 1 | 47k
15 | C23,C7,C30,C10,C24 | C_0603_1608Metric | 5 | 2.2uF
16 | TP1 | TP_1.0MM | 1 | ~
17 | C14,C17 | C_0603_1608Metric | 2 | 110pF
18 | R17,R12,R13 | R_0603_1608Metric | 3 | 1k1
19 | R7 | R_0603_1608Metric | 1 | 51k
20 | Y2,Y1 | Crystal_SMD_3225-4Pin_3.2x2.5mm | 2 | ECS-300-10-33B-CKM-TR
21 | U9,U10 | SOT-363_SC-70-6 | 2 | SI1926DL-T1-E3
22 | L9,L8 | L_0603_1608Metric | 2 | 470nH
23 | L11 | L_0603_1608Metric | 1 | 68nH
24 | Q7,Q2 | SOT-23 | 2 | AO3401A
25 | L7 | L_0603_1608Metric | 1 | 20nH
26 | D1,D4,D3 | D_SOD-323 | 3 | BAT54WS
27 | R2,R11,R6,R9,R10 | R_0603_1608Metric | 5 | 10k
28 | L1,L2 | L_0603_1608Metric | 2 | 270nH
29 | J2 | PinHeader_1x05_P2.54mm_Vertical | 1 | Conn_01x05
30 | R8 | R_0603_1608Metric | 1 | 16k
31 | U4 | XCVR_L76L-M33 | 1 | L76L-M33
32 | CR1 | U-DFN3810-9TYPE_B_DIO | 1 | D3V3X8U9LP3810-7
33 | J1 | RJ45_Amphenol_54602-x08_Horizontal | 1 | RJ45
34 | C5,C4 | C_0603_1608Metric | 2 | 3.3pF
35 | R1 | R_0603_1608Metric | 1 | 220R
36 | L3 | L_0603_1608Metric | 1 | 10nH
37 | U5 | QFN-32-1EP_5x5mm_P0.5mm_EP3.45x3.45mm | 1 | STM32L432KBUx
38 | C22 | C_0603_1608Metric | 1 | 16pF
39 | R14,R15,R16 | R_0603_1608Metric | 3 | 100R
40 | C32 | C_0603_1608Metric | 1 | 4pF
41 | C29 | C_0805_2012Metric | 1 | 10uF
42 | C28 | C_0805_2012Metric | 1 | 22uF
43 | L5 | L_0603_1608Metric | 1 | 13nH
44 | U1,U2 | QFN-20-1EP_4x4mm_P0.5mm_EP2.6x2.6mm_ThermalVias | 2 | Si4460
45 | L6 | L_0603_1608Metric | 1 | 39nH
46 | U6 | SOT-23-6 | 1 | AP3211K
47 | R3 | R_0603_1608Metric | 1 | 3k3
48 | AE1 | ANT_1575AT_JOT | 1 | 1575AT43A0040E
49 | J3 | RFSOLUTIONS_CON-SMA-EDGE-S | 1 | CON-SMA-EDGE-S
50 | U7 | SOT-23-5 | 1 | 24LC01BT/OT
51 | C33 | C_0603_1608Metric | 1 | 2.2pF
52 | L10 | L_0603_1608Metric | 1 | 47nH
53 | Q1 | SOT-89-3 | 1 | AFT05MS004NT1
54 | R4 | R_0603_1608Metric | 1 | 22R
55 | L14 | L_0603_1608Metric | 1 | 5.6nH

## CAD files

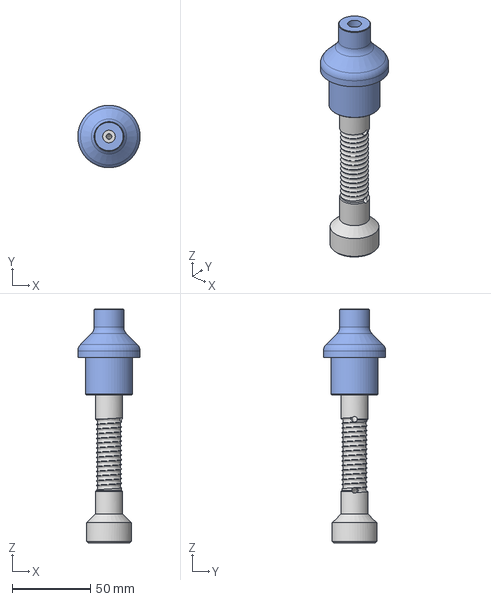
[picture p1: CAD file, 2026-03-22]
CAD/Antenna Parts v4.2.step
40.0 x 40.0 x 149.9 mm

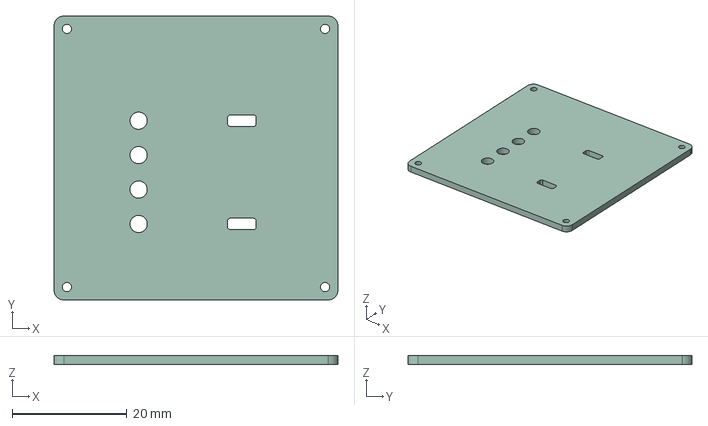
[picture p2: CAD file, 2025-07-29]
Schematics/Maiana_Blue_Frontpanel_v1.0/Maiana_Blue_Frontpanel_v1.0.step
49.5 x 49.5 x 1.60 mm

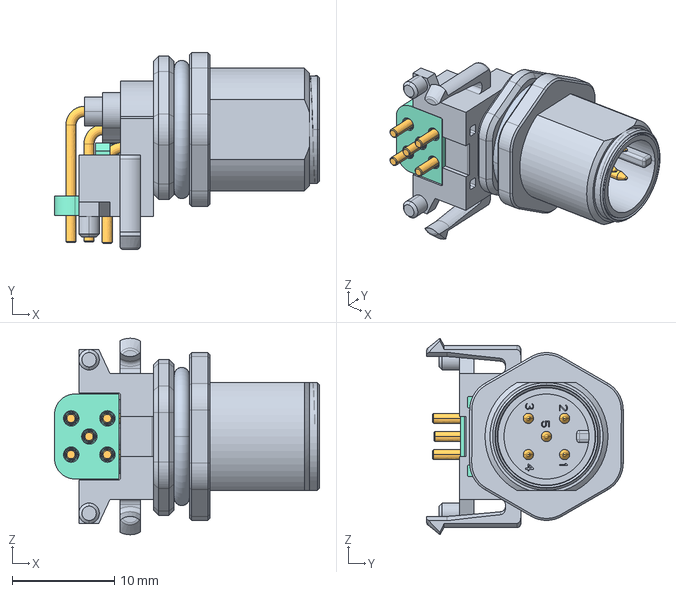
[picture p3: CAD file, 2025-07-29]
Schematics/Maiana_Blue_N2000_v8.2/M12A-05PMMR-SF7003-STP.stp
25.9 x 19.2 x 19.2 mm

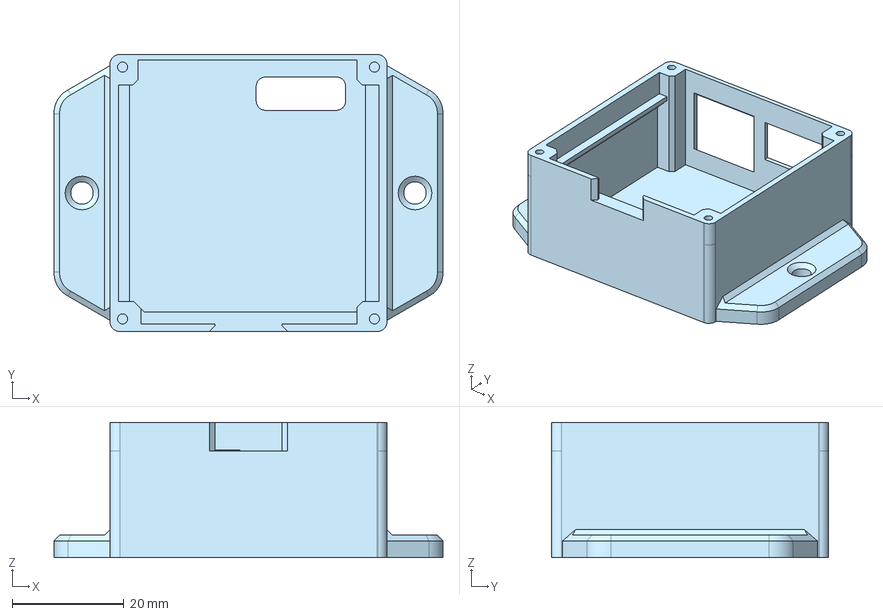
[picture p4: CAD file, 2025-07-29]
CAD/N0183_Case.step
69.5 x 49.5 x 24.1 mm

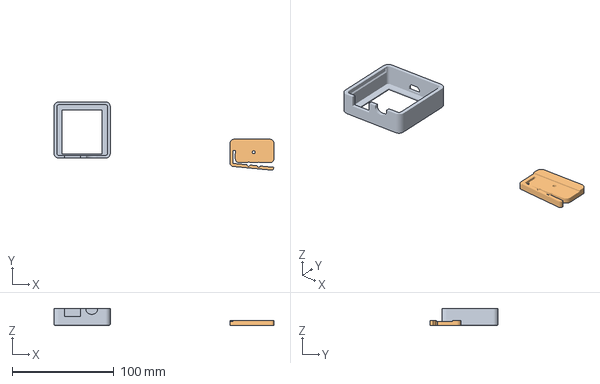
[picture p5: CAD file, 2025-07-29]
Schematics/Maiana_Blue_N2000_v8.2/case_front_v1.3mf
216.8 x 67.3 x 17.0 mm
case_front_v1.stl
wire_stripper.stl

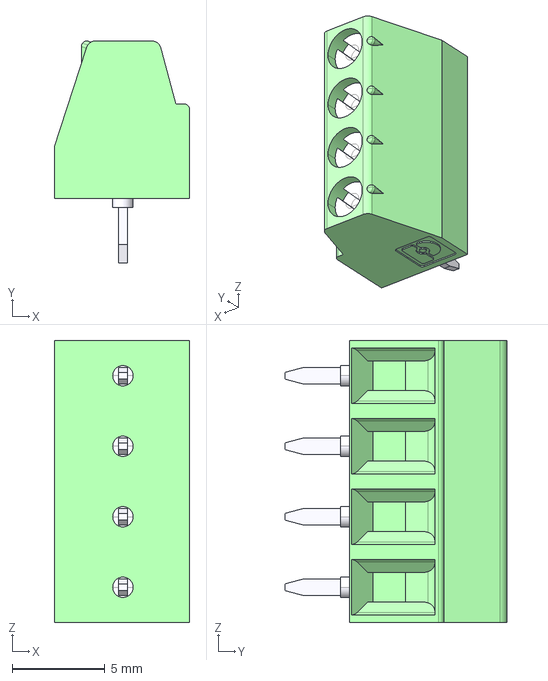
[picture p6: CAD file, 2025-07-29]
Schematics/Maiana_Blue_N0183_v7.3/LIB_1727036/1727036/3D/1727036.stp
7.30 x 12.0 x 15.2 mm

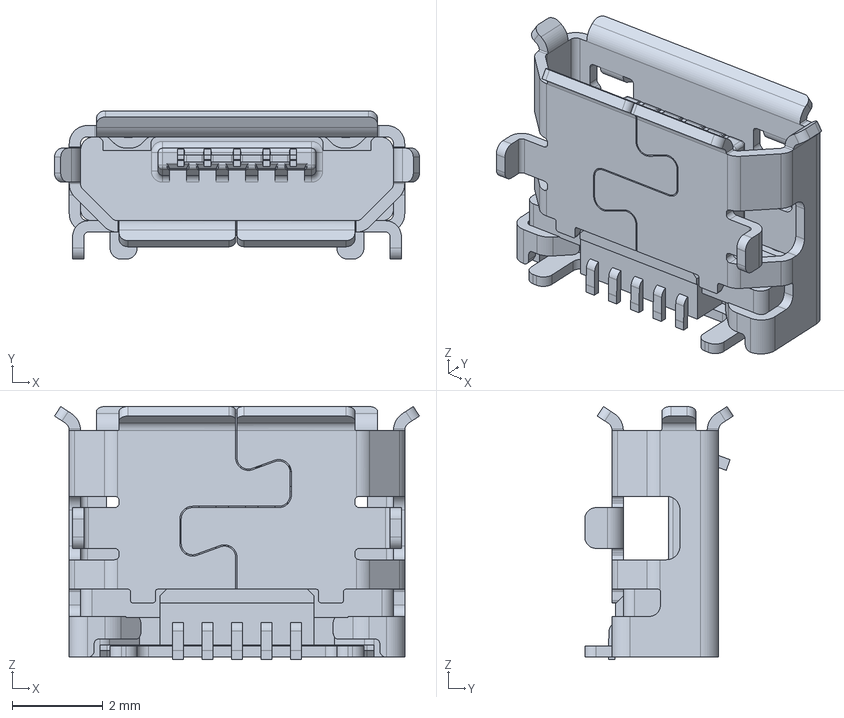
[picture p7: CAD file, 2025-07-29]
Schematics/Maiana_Blue_UART_v3.0/LIB_10118194-0001LF/10118194-0001LF/3D/10118194-0001LF.stp
8.05 x 3.27 x 5.58 mm

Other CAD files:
CAD/N2K_Case.step
Schematics/Maiana_Blue_N0183_v7.3/LIB_1727036/1727036/Allegro/1727036.psm
Schematics/Maiana_Blue_N0183_v7.3/LIB_1727036/1727036/DEHDL/1727036/chips/chips.prt
Schematics/Maiana_Blue_N2000_v8.2/case_front_v1.stl
Schematics/Maiana_Blue_UART_v3.0/LIB_10118194-0001LF/10118194-0001LF/Allegro/101181940001lf.psm
Schematics/Maiana_Blue_UART_v3.0/LIB_10118194-0001LF/10118194-0001LF/DEHDL/10118194_0001lf/chips/chips.prt

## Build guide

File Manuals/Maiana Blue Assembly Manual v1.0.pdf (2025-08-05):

# MAIANA BLUE Assembly Manual

Revision 1.0
July 2025

Based on original Peter’s MAIANA project and original assembly manual. (https://github.com/peterantypas/maiana/blob/master/latest/Manuals/MAIANA%E2%84%A2%20Assembly%20Manual%20(Rev%204).pdf)

# Kit Contents

The kit will arrive with all of these parts in a small box. These are:

1. The main PCB and basic UART/USB breakout in an ESD envelope
2. The antenna tube (two telescopic sections)
3. The 3D printed end cap for the antenna tube
4. The antenna core (coiled and stripped coax with SMA male on one end)
5. The main case (40mm outside diameter tube)
6. 40mm diameter heat shrink tubing, black

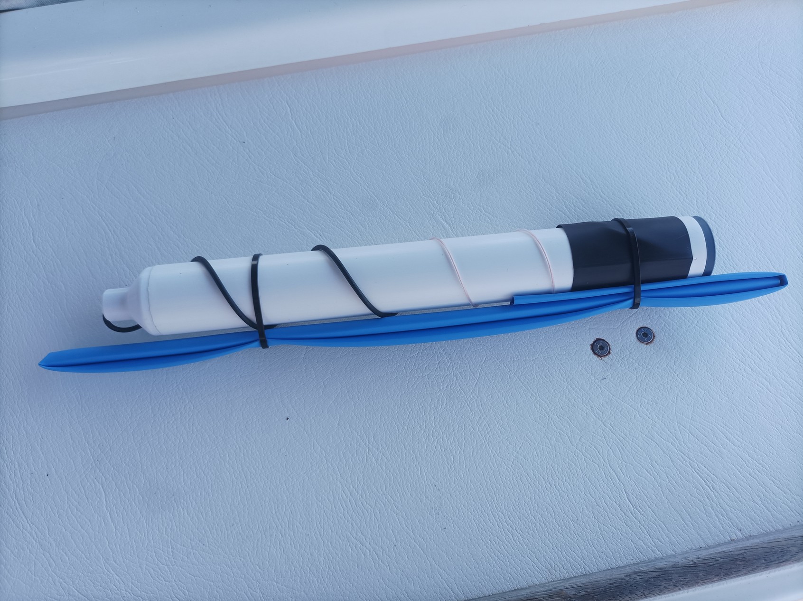
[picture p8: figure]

7. 25mm diameter heat shrink tube, black (enough for 2 builds)
8. 1m of 10mm diameter heat shrink tube, blue, folded
9. Threaded adapter for mounting on usual rail or deck GPS antenna mounts.

The main PCB, the UART/USB adapter, the antenna and the end cap are packed inside the main tube, for better protection during shipping.

# What you will need

To complete the installation you will need:

- A soldering iron for the RJ45 connector and “breakaway” pin headers of the UART adapter
- Some kind of instant glue to secure the end cap of the antenna tube
- A pair of strong scissors for cutting (thick) heat shrink tubing
- A heat gun for the heat shrink tubing. You will need this both on your workbench for the initial assembly, as well as on your boat for the final installation. If you don’t have a proper heat gun, see this article here for some alternate options. That said, beware of anything that projects a flame, as it can easily melt the PVC enclosure!
- A Cat5 cable for connecting the main unit to the breakout board in the cabin. This should be a regular “patch” cable and not a “crossover” cable. Pick one with appropriate length and flexibility to suit your installation. The exact configuration of the cable (568A or 568B) is not important.
Cat8 cable can be used also, for the more exposed sections outside the boat and Cat6 for the rest of sections inside the boat, all in the same line. Sections can be connected by this RJ45 Connector Outdoor Waterproof Female To Female: https://aliexpress.com/item/1005006199584847.html

ESD CAUTION: Many electronic components on the MAIANA BLUE boards are sensitive to electrostatic discharge. Although both the adapter and the main board feature strategically placed TVS diodes, these will not necessarily protect the circuit from a discharge at some random location due to touch. So make sure you follow these really basic rules:

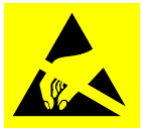
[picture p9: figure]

- Work on an ESD-safe surface, ideally an ESD mat. Metal and wooden surfaces are usually safe. Avoid plastic ones.
- When you arrive at your workstation, stop walking and ground your hands immediately before touching any electronics. Ideally, you should start by putting on a grounding strap.

This is by no means a comprehensive guide, but it covers the most common mistakes. For more information, read this. (https://www.minicircuits.com/app/AN40-005.pdf)

# Assemble the antenna

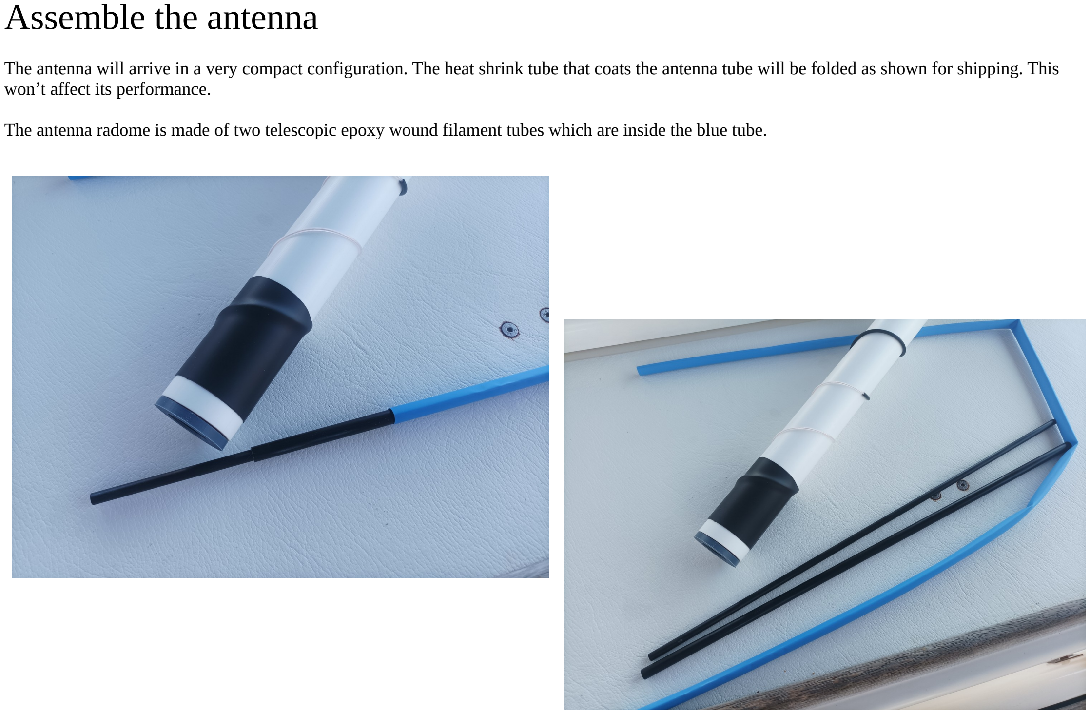
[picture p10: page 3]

The antenna will arrive in a very compact configuration. The heat shrink tube that coats the antenna tube will be folded as shown for shipping. This won’t affect its performance.

The antenna radome is made of two telescopic epoxy wound filament tubes which are inside the blue tube.

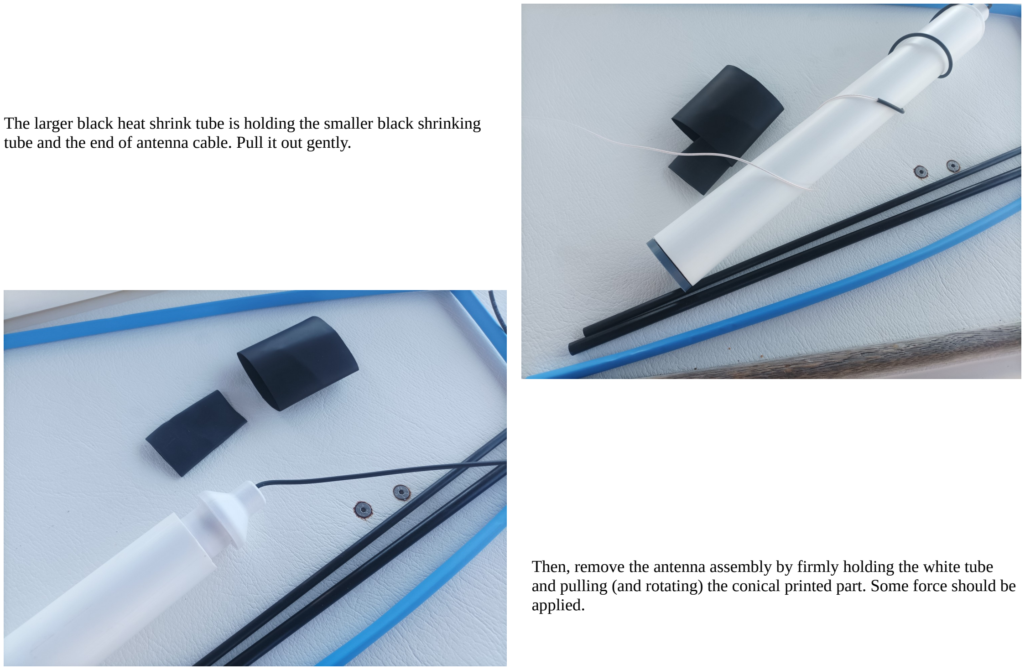
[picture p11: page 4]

The larger black heat shrink tube is holding the smaller black shrinking tube and the end of antenna cable. Pull it out gently.

Then, remove the antenna assembly by firmly holding the white tube and pulling (and rotating) the conical printed part. Some force should be applied.

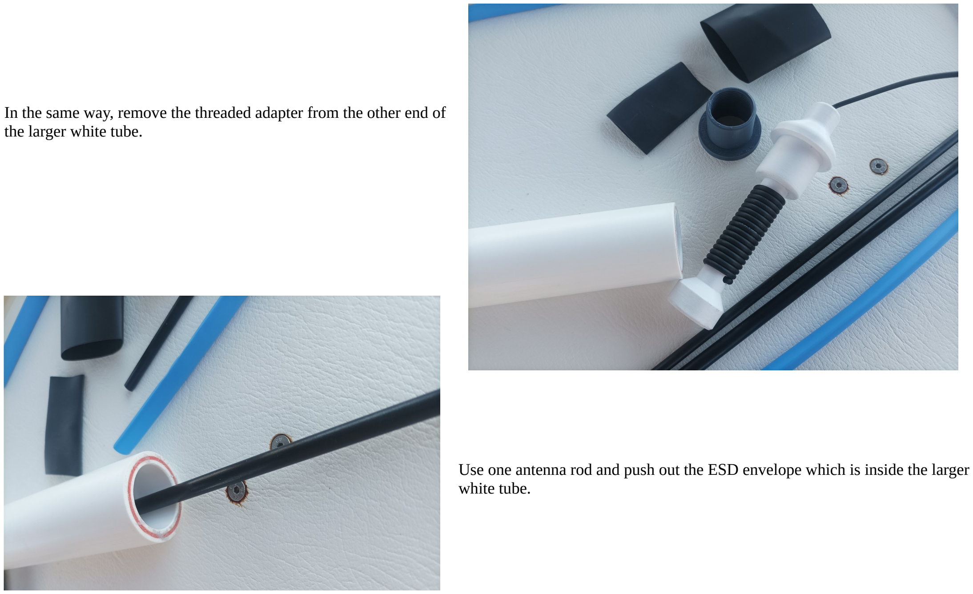
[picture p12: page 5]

In the same way, remove the threaded adapter from the other end of the larger white tube.

Use one antenna rod and push out the ESD envelope which is inside the larger white tube.

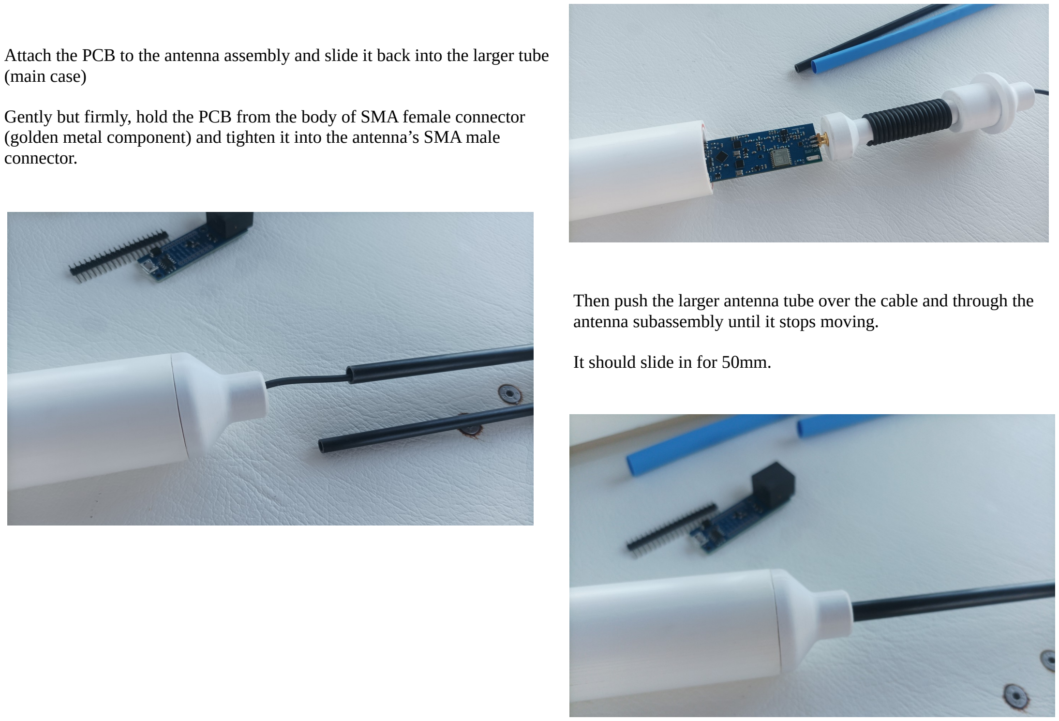
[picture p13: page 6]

Attach the PCB to the antenna assembly and slide it back into the larger tube (main case)

Gently but firmly, hold the PCB from the body of SMA female connector (golden metal component) and tighten it into the antenna’s SMA male connector.

Then push the larger antenna tube over the cable and through the antenna subassembly until it stops moving.

It should slide in for 50mm.

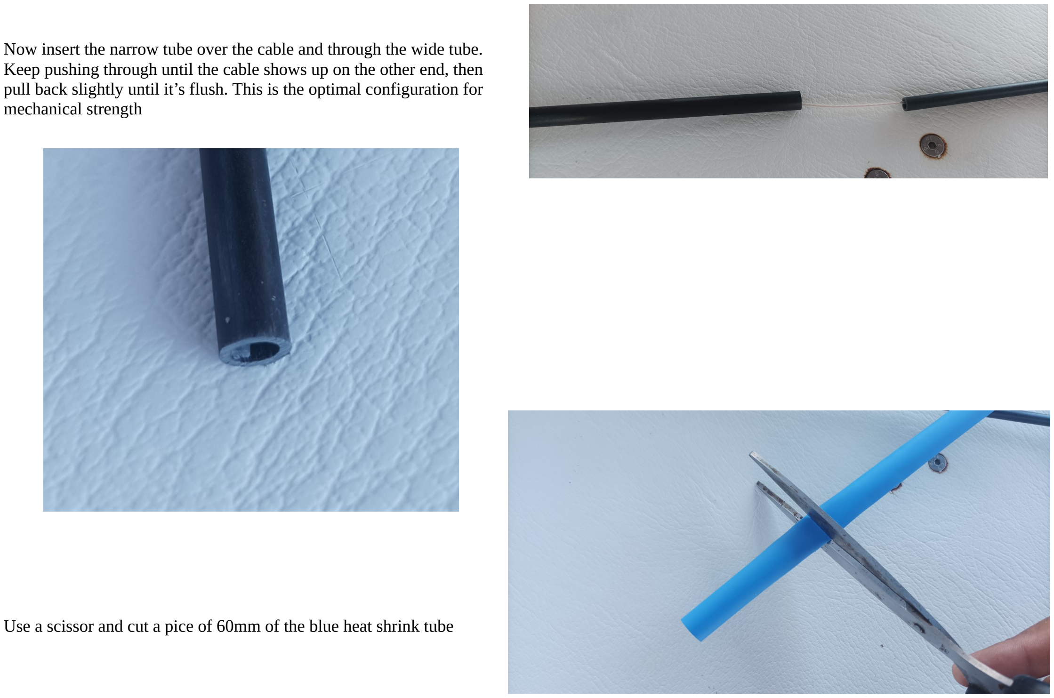
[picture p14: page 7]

Now insert the narrow tube over the cable and through the wide tube. Keep pushing through until the cable shows up on the other end, then pull back slightly until it’s flush. This is the optimal configuration for mechanical strength

Use a scissor and cut a pice of 60mm of the blue heat shrink tube

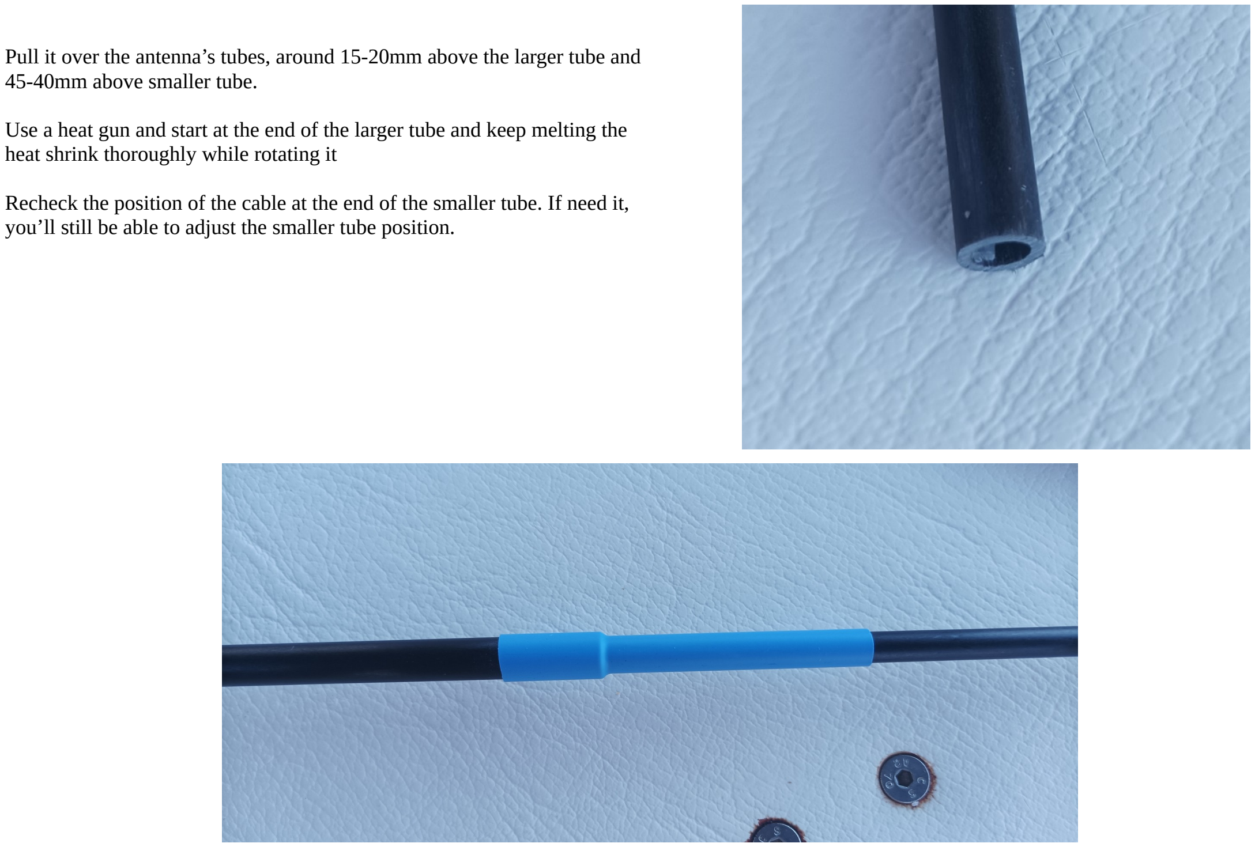
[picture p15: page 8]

Pull it over the antenna’s tubes, around 15-20mm above the larger tube and 45-40mm above smaller tube.

Use a heat gun and start at the end of the larger tube and keep melting the heat shrink thoroughly while rotating it

Recheck the position of the cable at the end of the smaller tube. If need it, you’ll still be able to adjust the smaller tube position.

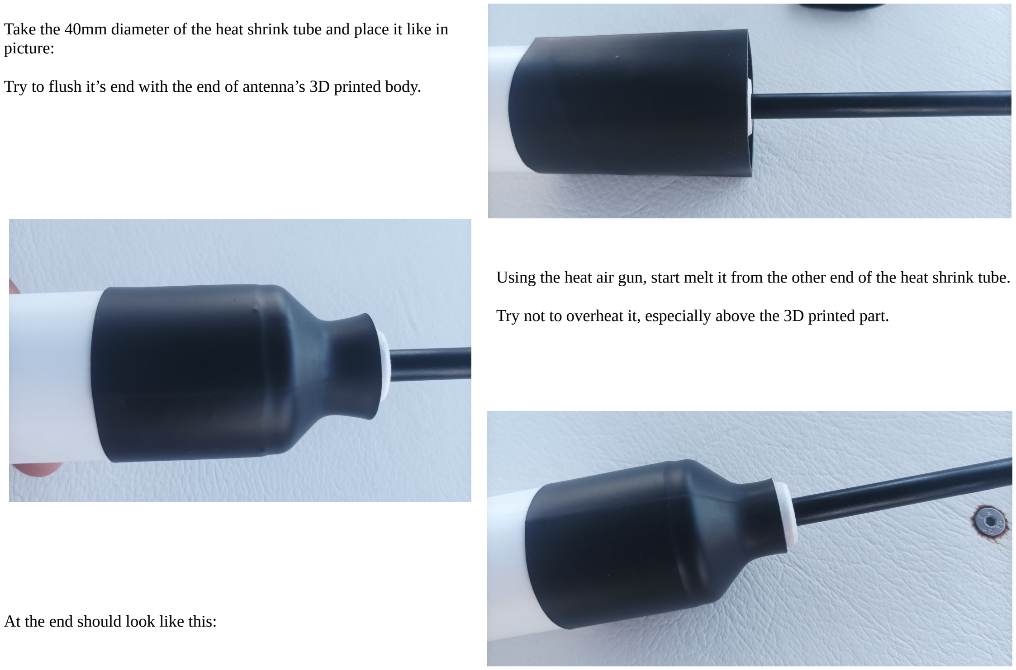
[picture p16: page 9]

Take the 40mm diameter of the heat shrink tube and place it like in picture:

Try to flush it’s end with the end of antenna’s 3D printed body.

Using the heat air gun, start melt it from the other end of the heat shrink tube.

Try not to overheat it, especially above the 3D printed part.

At the end should look like this:

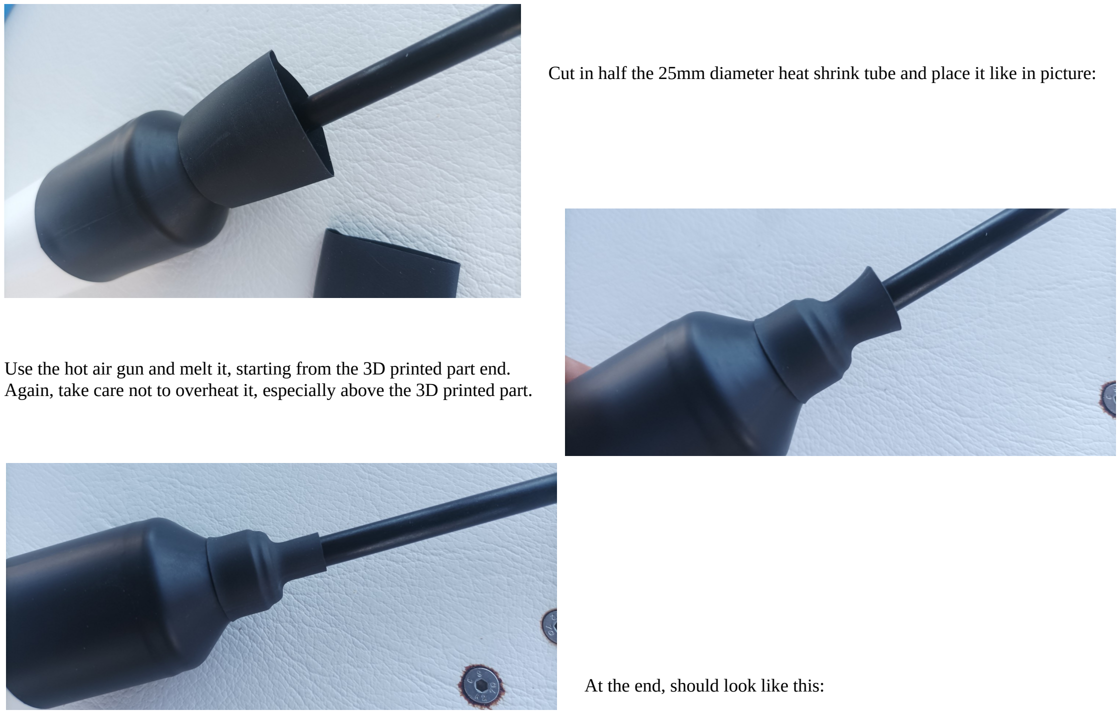
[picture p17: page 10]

Cut in half the 25mm diameter heat shrink tube and place it like in picture:

Use the hot air gun and melt it, starting from the 3D printed part end. Again, take care not to overheat it, especially above the 3D printed part.

At the end, should look like this:

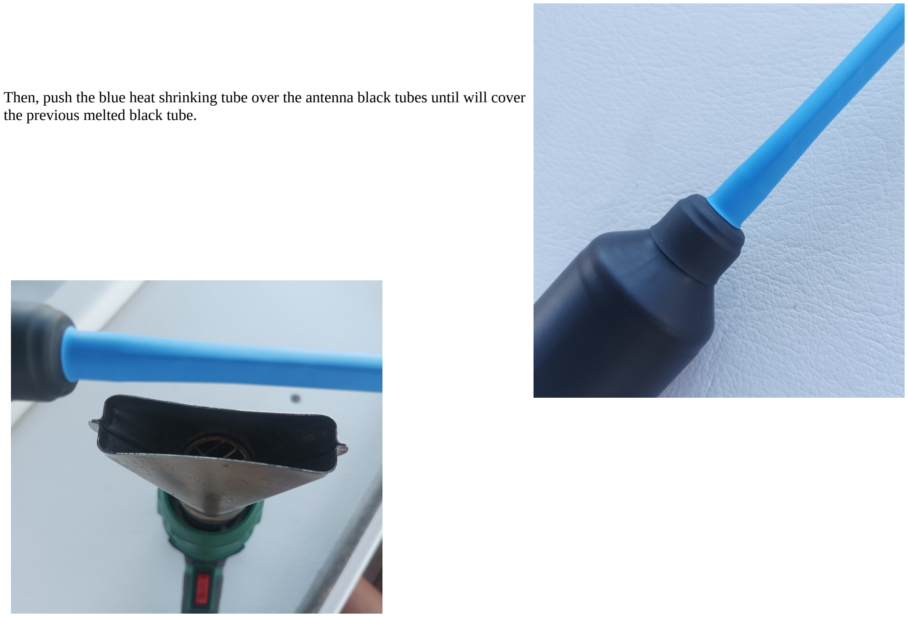
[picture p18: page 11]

Then, push the blue heat shrinking tube over the antenna black tubes until will cover the previous melted black tube.

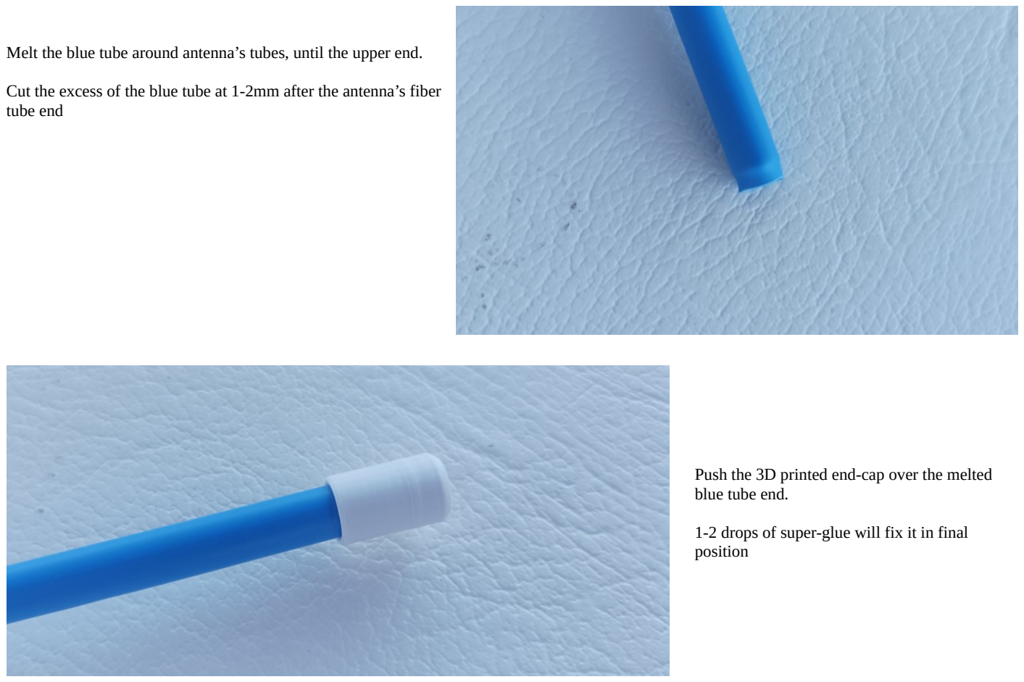
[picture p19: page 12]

Melt the blue tube around antenna’s tubes, until the upper end.

Cut the excess of the blue tube at 1-2mm after the antenna’s fiber tube end

Push the 3D printed end-cap over the melted blue tube end.

1-2 drops of super-glue will fix it in final position

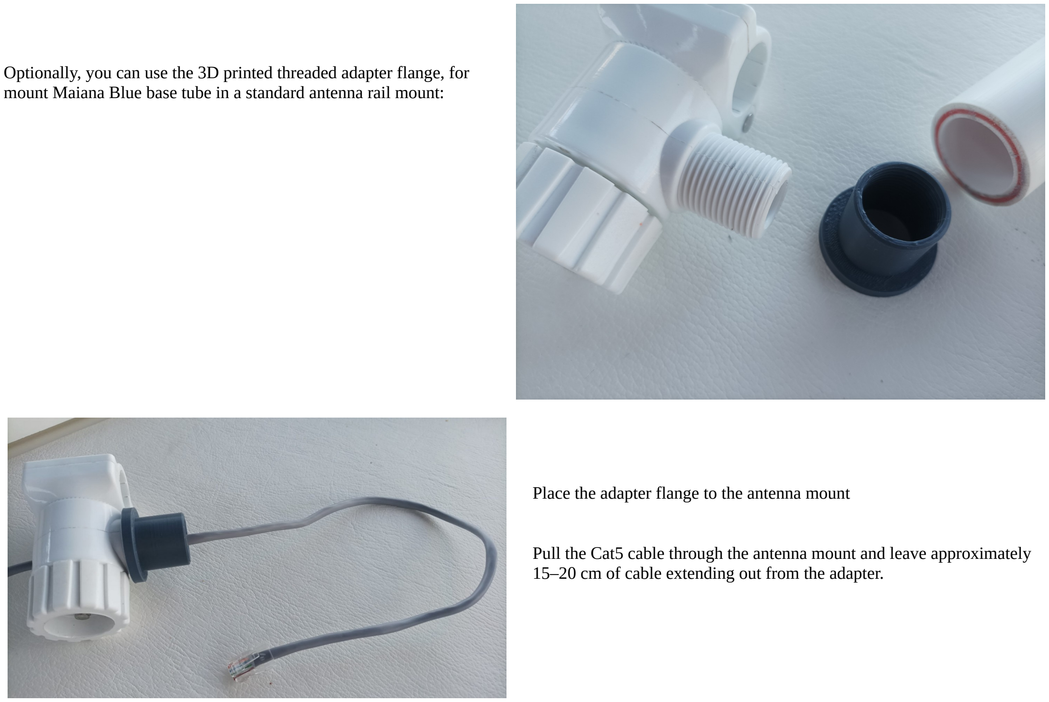
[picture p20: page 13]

Optionally, you can use the 3D printed threaded adapter flange, for mount Maiana Blue base tube in a standard antenna rail mount:

Place the adapter flange to the antenna mount

Pull the Cat5 cable through the antenna mount and leave approximately 15–20 cm of cable extending out from the adapter.

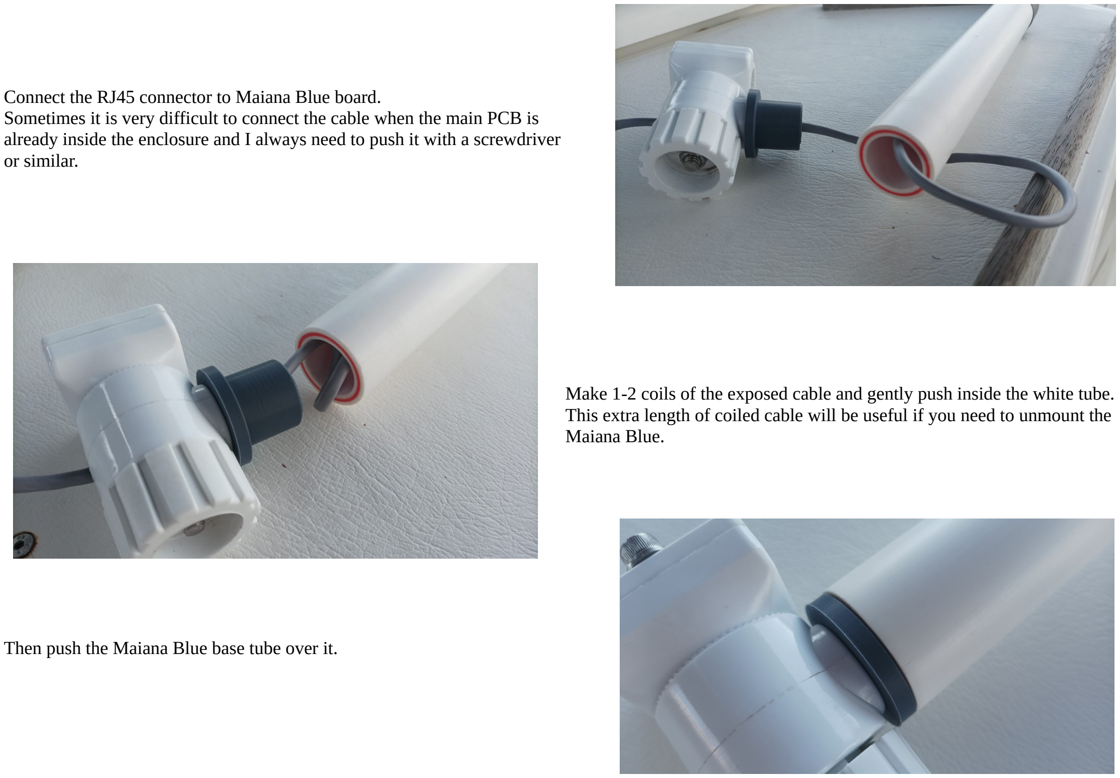
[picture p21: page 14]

Connect the RJ45 connector to Maiana Blue board.
Sometimes it is very difficult to connect the cable when the main PCB is already inside the enclosure and I always need to push it with a screwdriver or similar.

Make 1-2 coils of the exposed cable and gently push inside the white tube. This extra length of coiled cable will be useful if you need to unmount the Maiana Blue.

Then push the Maiana Blue base tube over it.

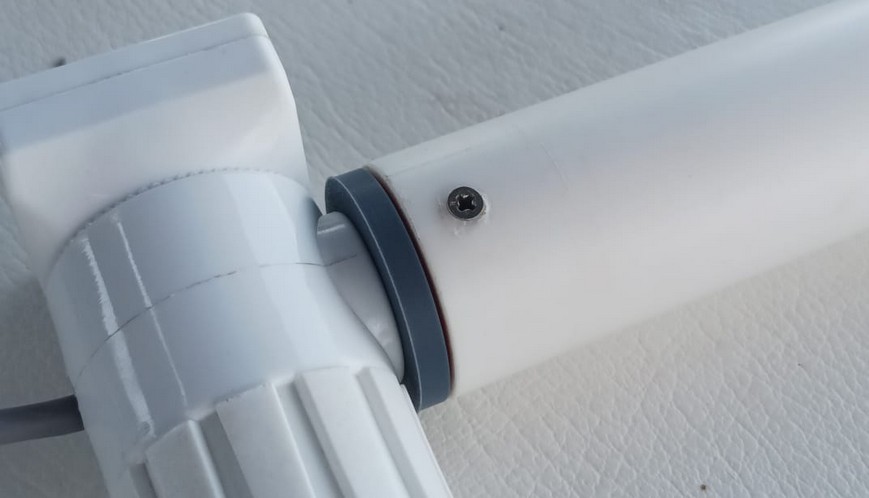
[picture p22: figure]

Optionally, you can secure the large tube to the 3D printed adapter by drilling a hole and using a small screw, or more.

You can do this operation before passing the cable through antenna mount, to avoid damaging the cable.

Pay attention not to use a longer screw, not to damage the cable.

# UART Adapter

This adapter is included in every kit. You will need to supply 12V from a battery or a power

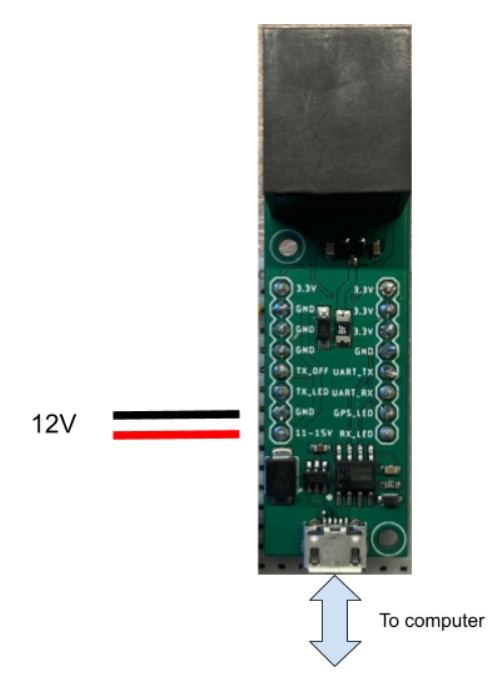
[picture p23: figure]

supply and connect the USB cable to the computer. Alternatively, you may choose to wire the UART RX and TX lines directly to an adapter or the Raspberry Pi pin headers.

The breakout board should be mounted below deck, somewhere where it’s going to be protected from the elements. How and where it is fitted is entirely your choice.

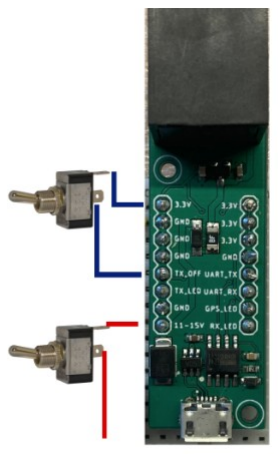
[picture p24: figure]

If you want a power and/or TX switch, you can use simple rocker switches as shown here.
A 1A-rated SPST can simply interrupt the main 12V supply.
If you want a hardware switch for “silent mode”, you need to remember that transmission is disabled if the TX_OFF signal is driven to a logic “high” (above 2V), so wire it as shown here.

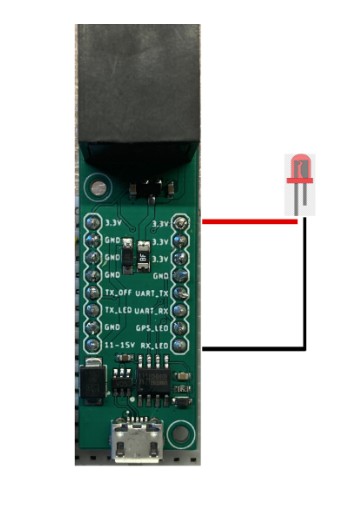
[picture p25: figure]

If you intend to wire LEDs, this is the correct way. The LED signals are open drain outputs. Rather than supplying a voltage, they pull the cathode of the LED to GND via a built-in 100 Ohm resistor.

The voltage you apply to the anode is flexible (up to 30V tolerated), but the breakout supplies 3.3V so take advantage!
That said, some LEDs may still draw too much current and will need an extra resistor added in series.

You can wire that on either the anode or the cathode side

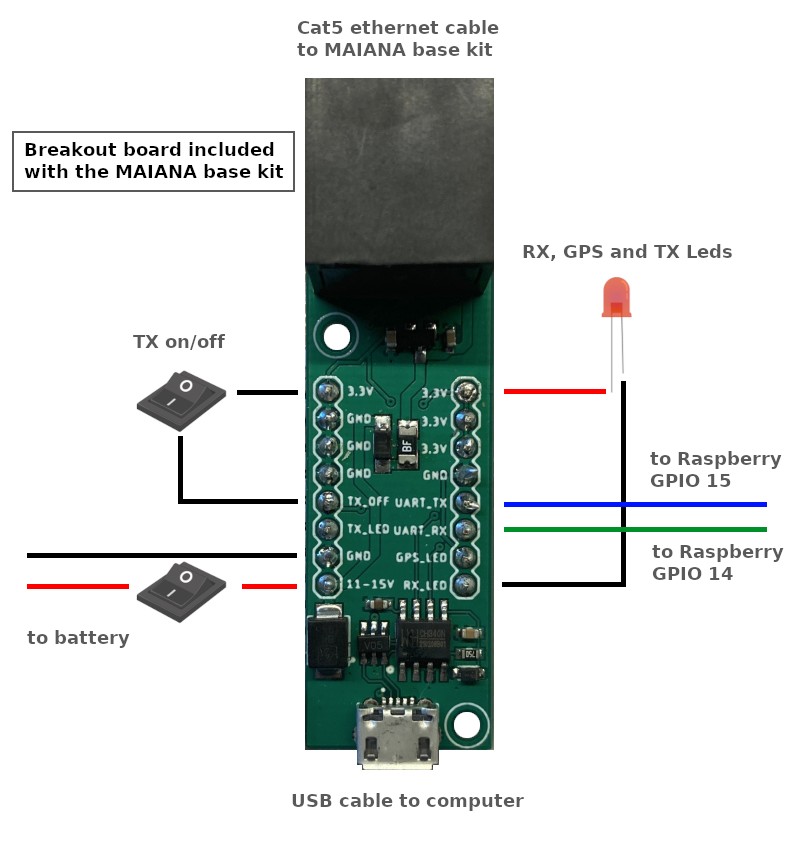
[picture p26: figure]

A compact wiring diagram can be seen here.
It include also the connection pins for Raspberry Pi.

# Provisioning

Configure the COM port for 38400 bps, 8 bit data, no parity, one stop bit. Attach the serial terminal to this port and power up the system. You should see a continuous feed of NMEA0183 sentences.

To interact with the unit using commands, configure your serial terminal application (like Termite for Windows or CuteCom for Linux) for line input with CRLF (‘\r\n’) termination. Then send the cli command (you may need to send it more than once). The unit should reboot and respond with this output:

CLI mode. Send the 'reboot' command or cycle power to exit.

With the terminal really quiet now, it’s a lot easier to send the station command for provisioning.
This command has eight comma-separated arguments with no quotes or spaces in between. It must be sent in one line like this:

station mmsi,name,callsign,type,len,beam,portoffset,bowoffset

The arguments are:
- MMSI (you should have one for your boat already)
- Boat name (up to 20 alphanumeric characters, no punctuation. Use all caps)
- Call sign (may be empty if you don’t have one)
- Type (this is the numeric type of the vessel, see below)
- Length in meters (integer only)
- Beam (width) in meters (integer only)
- Port offset (meters from the port side where the unit is located).
- Bow offset (meters from the bow where the unit is located).

For vessel type, here are some numeric values that apply to class B transponders:
- 30 - Fishing
- 34 - Diving
- 36 - Sailing
- 37 - Pleasure craft

Choose whichever you think is appropriate.

When you send the command, the unit will program the data into its EEPROM and respond with the $PAISTN proprietary sentence. Here is an (invalid vessel) command example:

station 987654321,NAUT,,37,0,0,0,0

response:$PAISTN,987654321,NAUT,,37,0,0,0,0*2A

If you made a mistake, you can always send the station command again. If this looks like it worked, issue the reboot command to restart the unit.

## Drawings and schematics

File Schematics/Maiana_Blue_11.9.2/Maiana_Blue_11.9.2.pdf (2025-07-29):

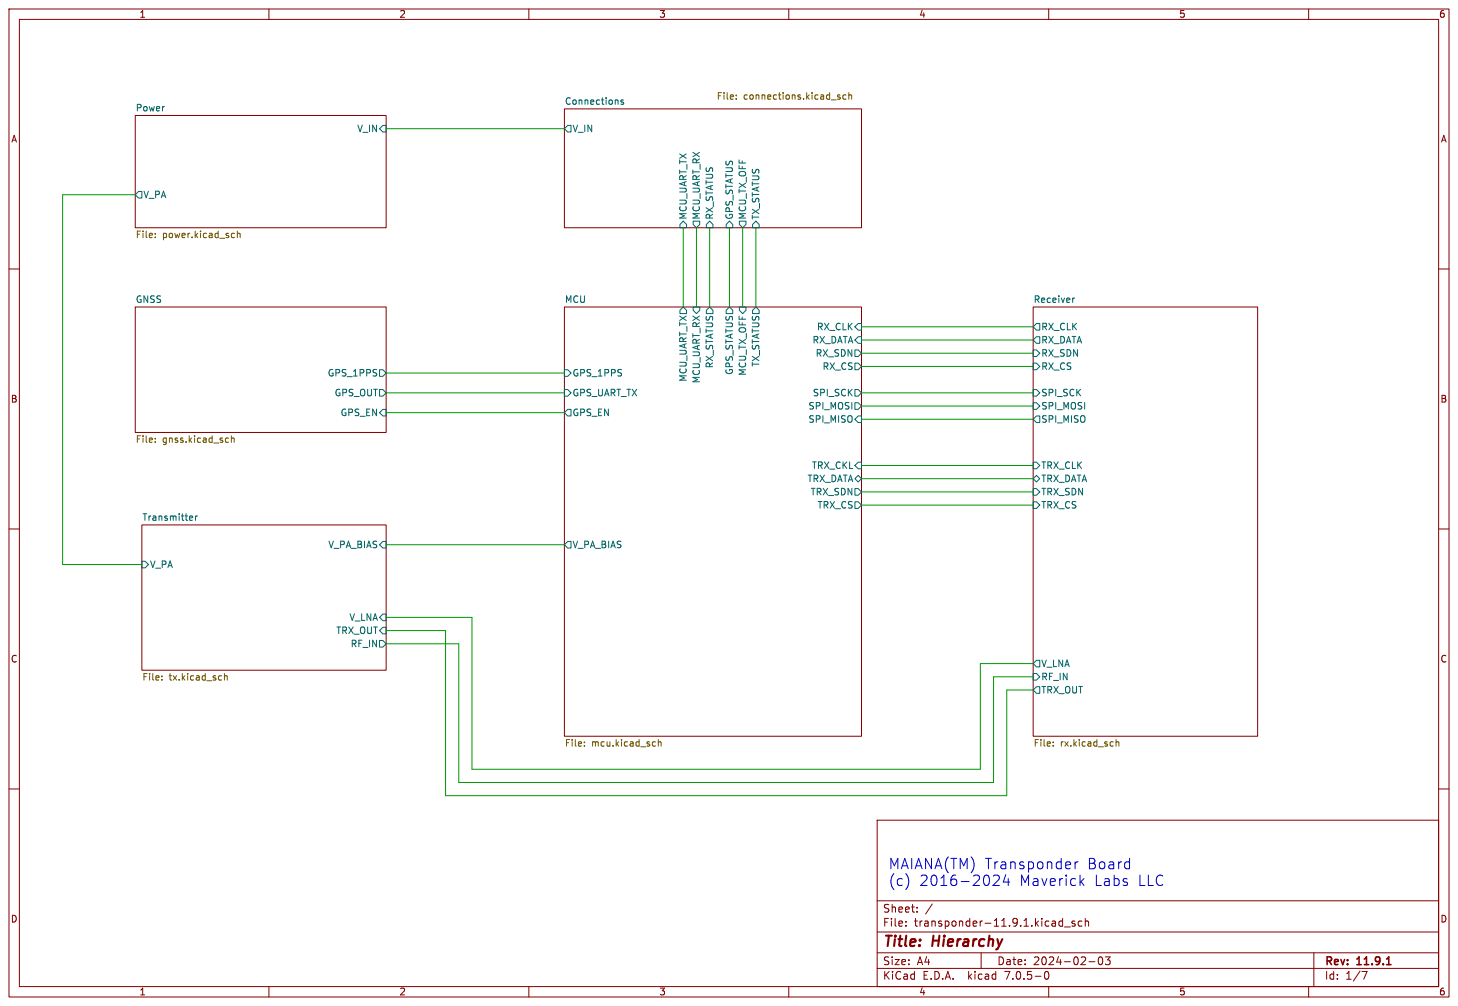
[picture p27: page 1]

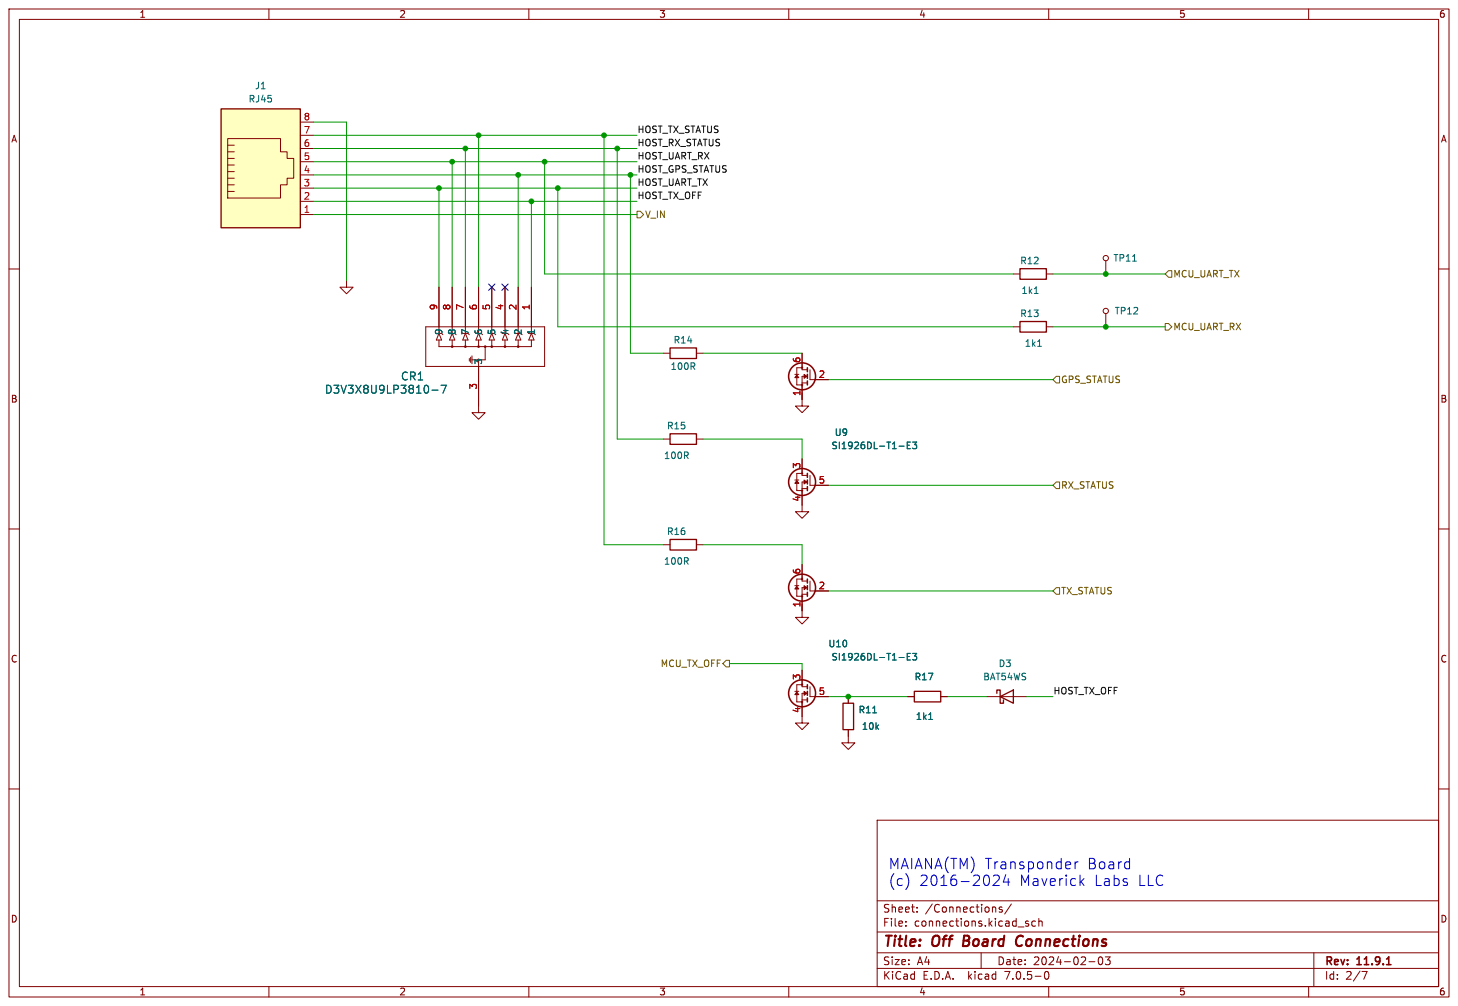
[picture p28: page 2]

File: connections.kicad_sch Sheet: /Connections/
Id: 2/7 Title: Off Board Connections

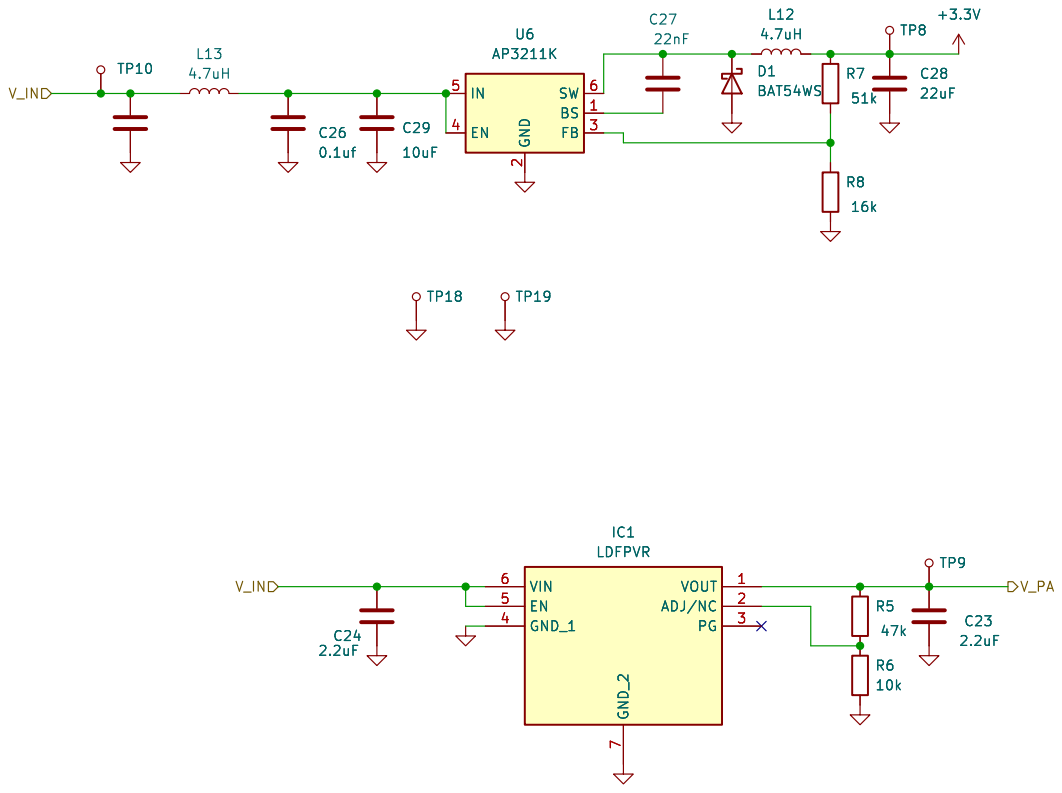
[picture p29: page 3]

File: power.kicad_sch Sheet: /Power/
Id: 3/7 Title: Power Supply

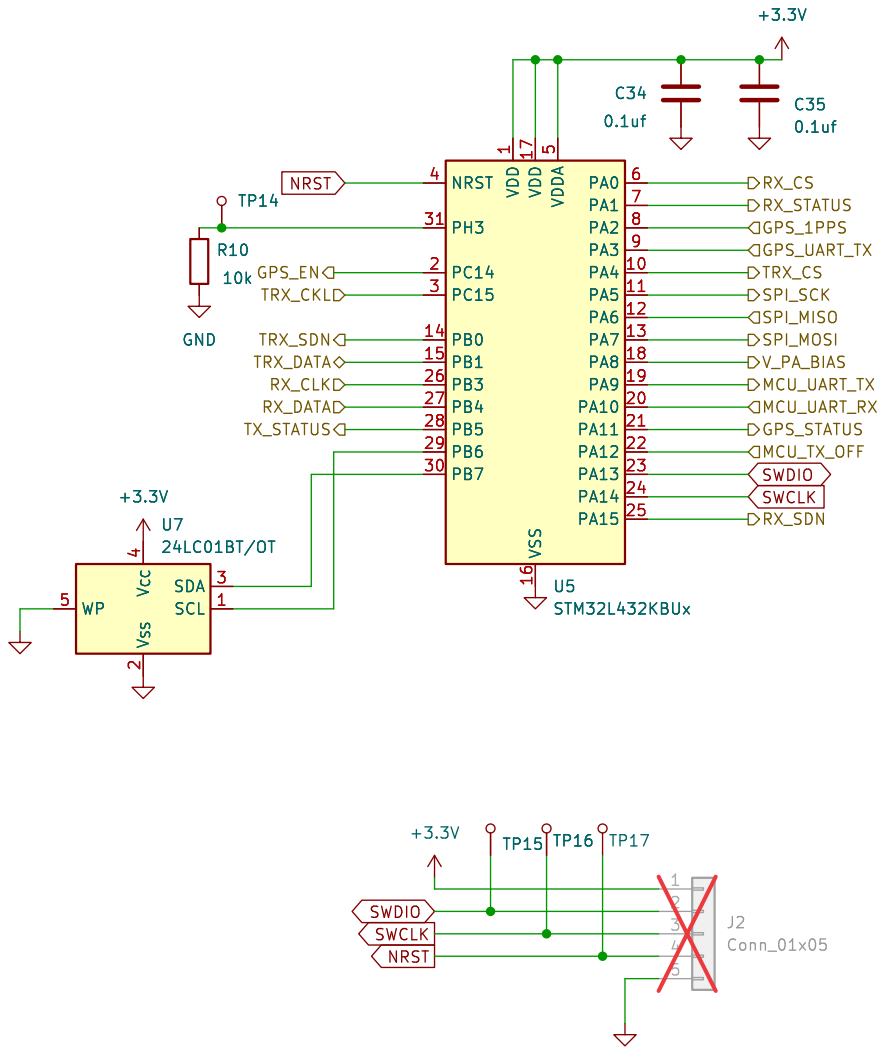
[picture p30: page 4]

1 PA4 10 PA5 11 PA6 12 PA7 13 PB0 14 PB1 15 VSS 16 VDD 17 PA8 18 PA9 19 PC14 2 PA10 20 PA11 21 PA12 22 PA13 23 PA14 24 PA15 25 PB3 26 PB4 27 PB5 28 PB6 29 PC15 3 PB7 30 PH3 31 NRST 4 VDDA

File: mcu.kicad_sch Sheet: /MCU/ TP16 +3.3V

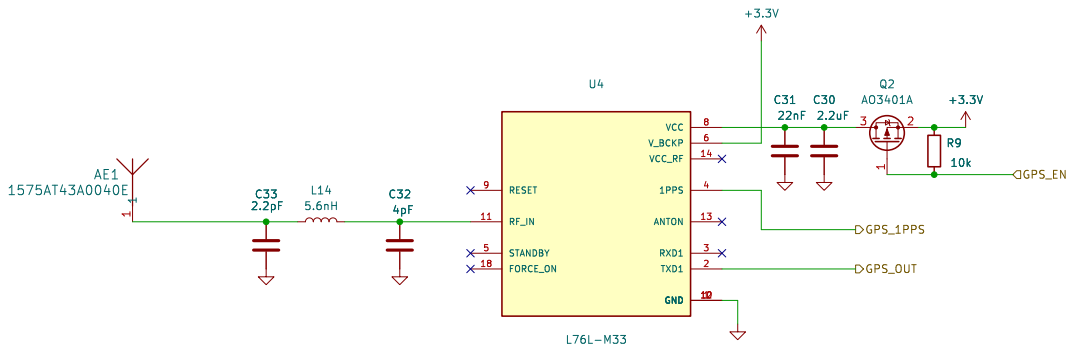
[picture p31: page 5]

File: gnss.kicad_sch Sheet: /GNSS/
Id: 5/7 Title: GNSS

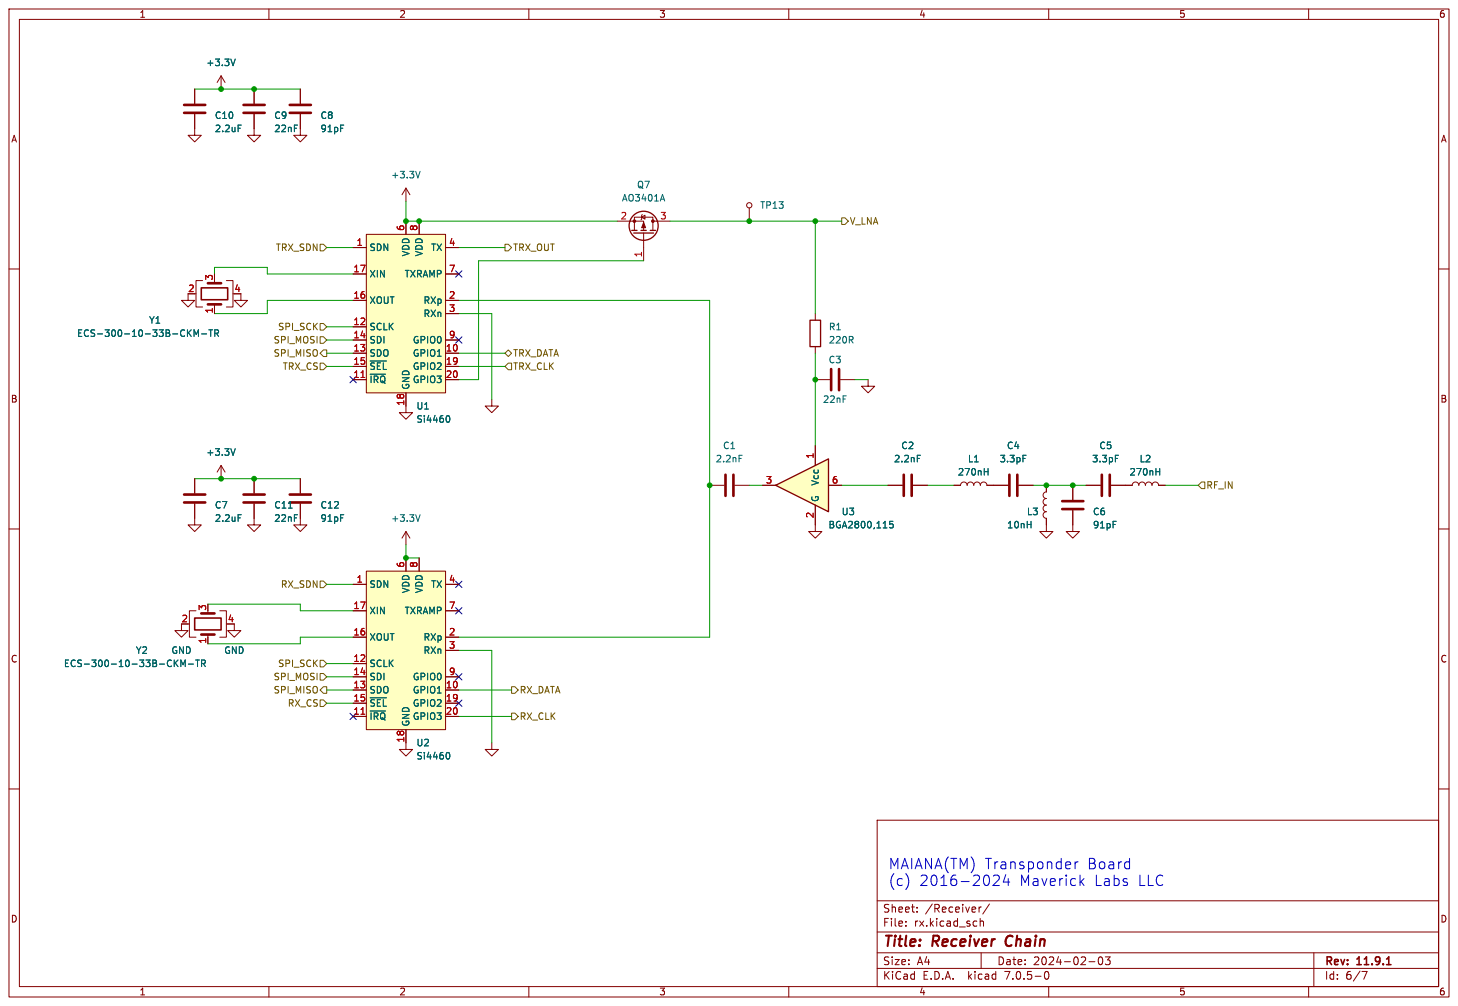
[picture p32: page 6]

8 GPIO0 9 U2Si4460 SDN 1 GPIO1 10 ~{IRQ} 11 SCLK 12 SDO 13 SDI 14 ~{SEL} 15 XOUT 16 XIN 17 GND 18 GPIO2 19 RXp 2 GPIO3 20 RXn 3 TX 4 VDD

File: rx.kicad_sch Sheet: /Receiver/
Id: 6/7 Title: Receiver Chain

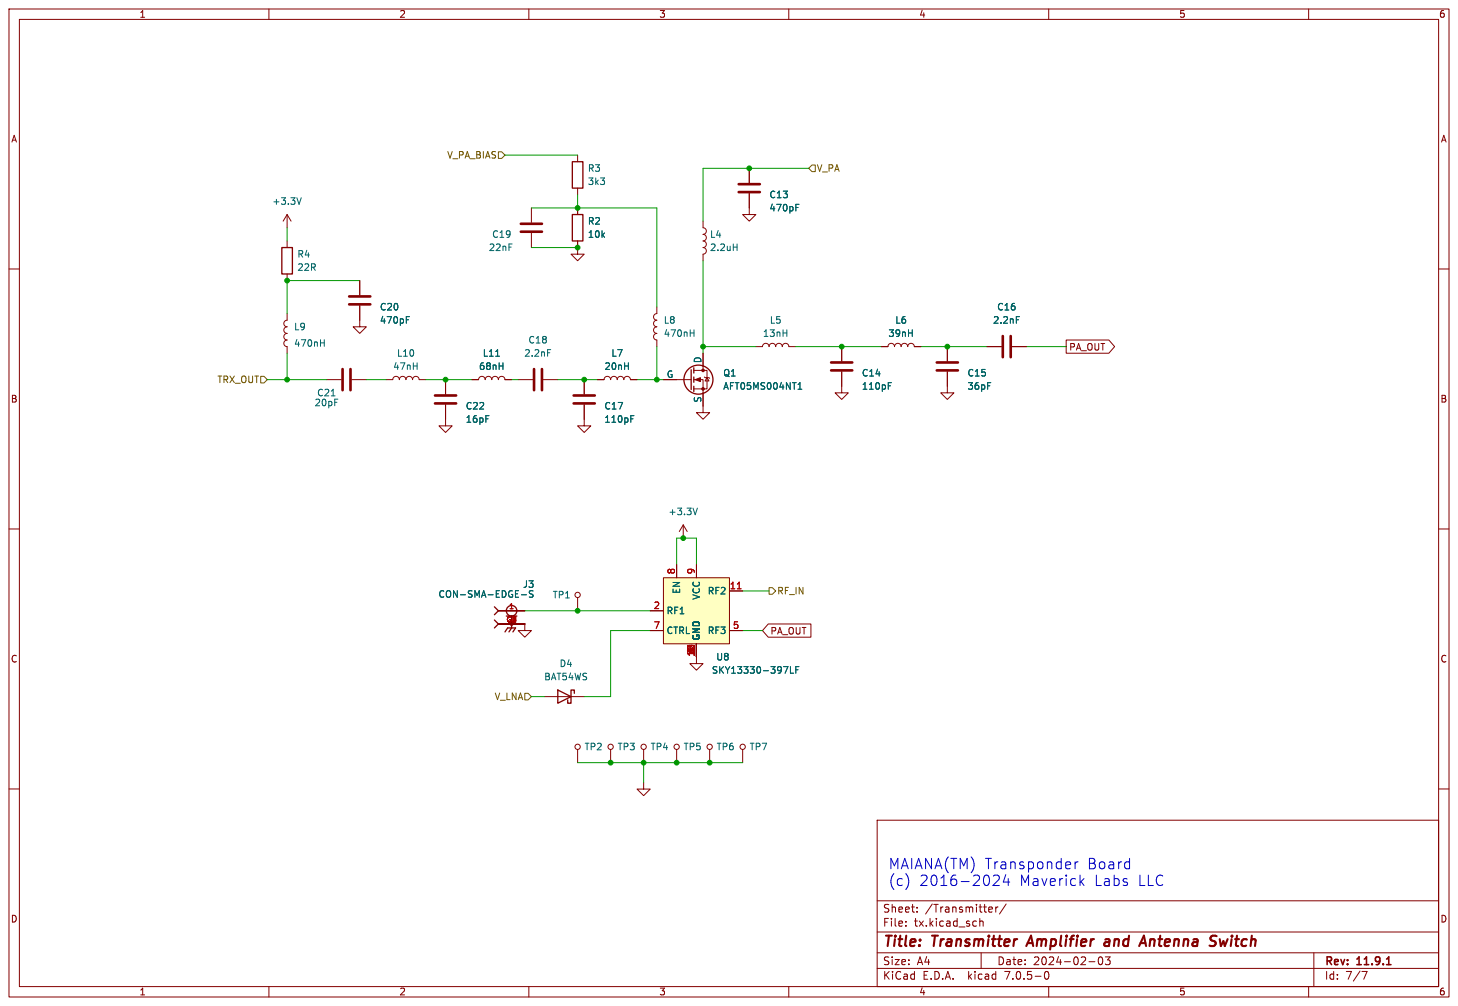
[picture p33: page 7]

File: tx.kicad_sch Sheet: /Transmitter/
Id: 7/7 Title: Transmitter Amplifier and Antenna Switch

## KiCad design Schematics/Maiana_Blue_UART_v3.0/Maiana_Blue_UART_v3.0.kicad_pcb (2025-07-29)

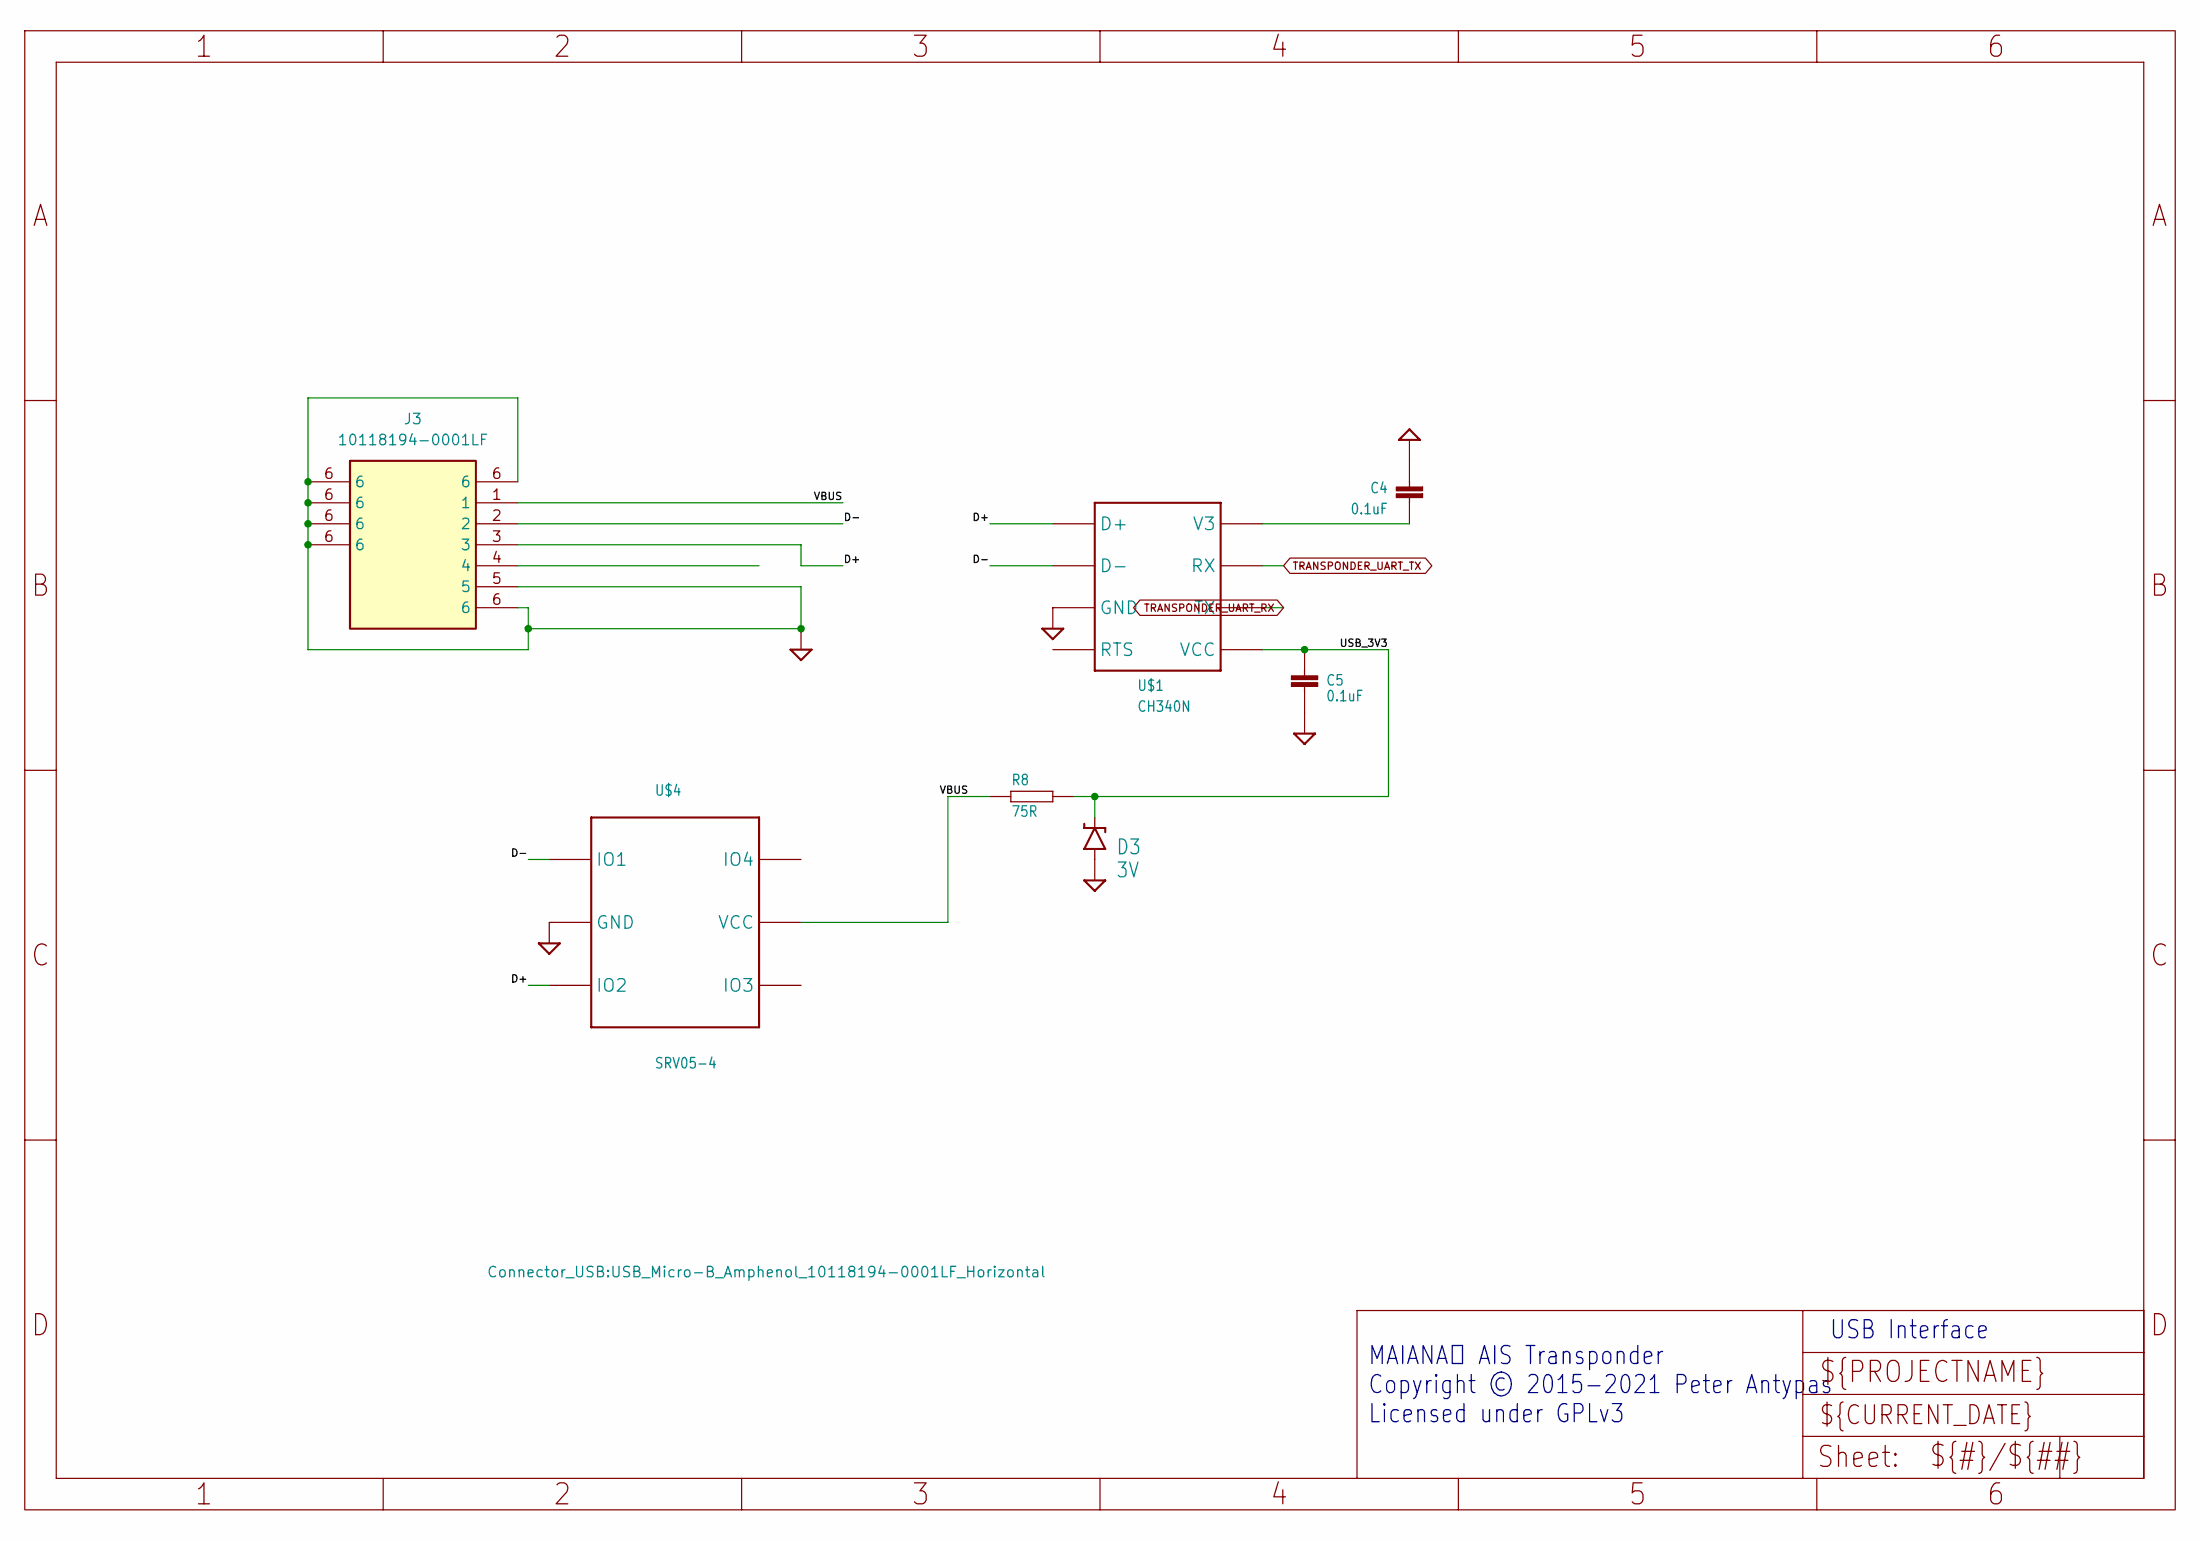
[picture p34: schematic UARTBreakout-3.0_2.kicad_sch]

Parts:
C4, C5: 0.1uF; 0603
D3: 3V; SOD-323
J3: 10118194-0001LF; USB_Micro-B_Amphenol_10118194-0001LF_Horizontal; Manufacturer_Part_Number 10118194-0001LF
R8: 75R; 0603
U$1: CH340N; SOIC-8; PARTNO CH340N
U$4: SRV05-4; SOT23-6

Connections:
/UARTBreakout-3.0_2/D+: J3.3, U$1.1 (D+), U$4.3 (IO2)
/UARTBreakout-3.0_2/D-: J3.2, U$1.2 (D-), U$4.1 (IO1)
/UARTBreakout-3.0_2/USB_3V3: C5.P$1 (1), D3.C, R8.P$2, U$1.5 (VCC)
/UARTBreakout-3.0_2/VBUS: J3.1, R8.P$1, U$4.5 (VCC)
GND: C4.P$2 (2), C5.P$2 (2), D3.A, J3.5, J3.6, U$1.3 (GND), U$4.2 (GND); also elsewhere on the board
unnamed: C4.P$1 (1), U$1.8 (V3)
TRANSPONDER_UART_RX: U$1.6 (TX); also elsewhere on the board
TRANSPONDER_UART_TX: U$1.7 (RX); also elsewhere on the board

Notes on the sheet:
USB Interface
MAIANA™ AIS Transponder Copyright © 2015-2021 Peter Antypas Licensed under GPLv3

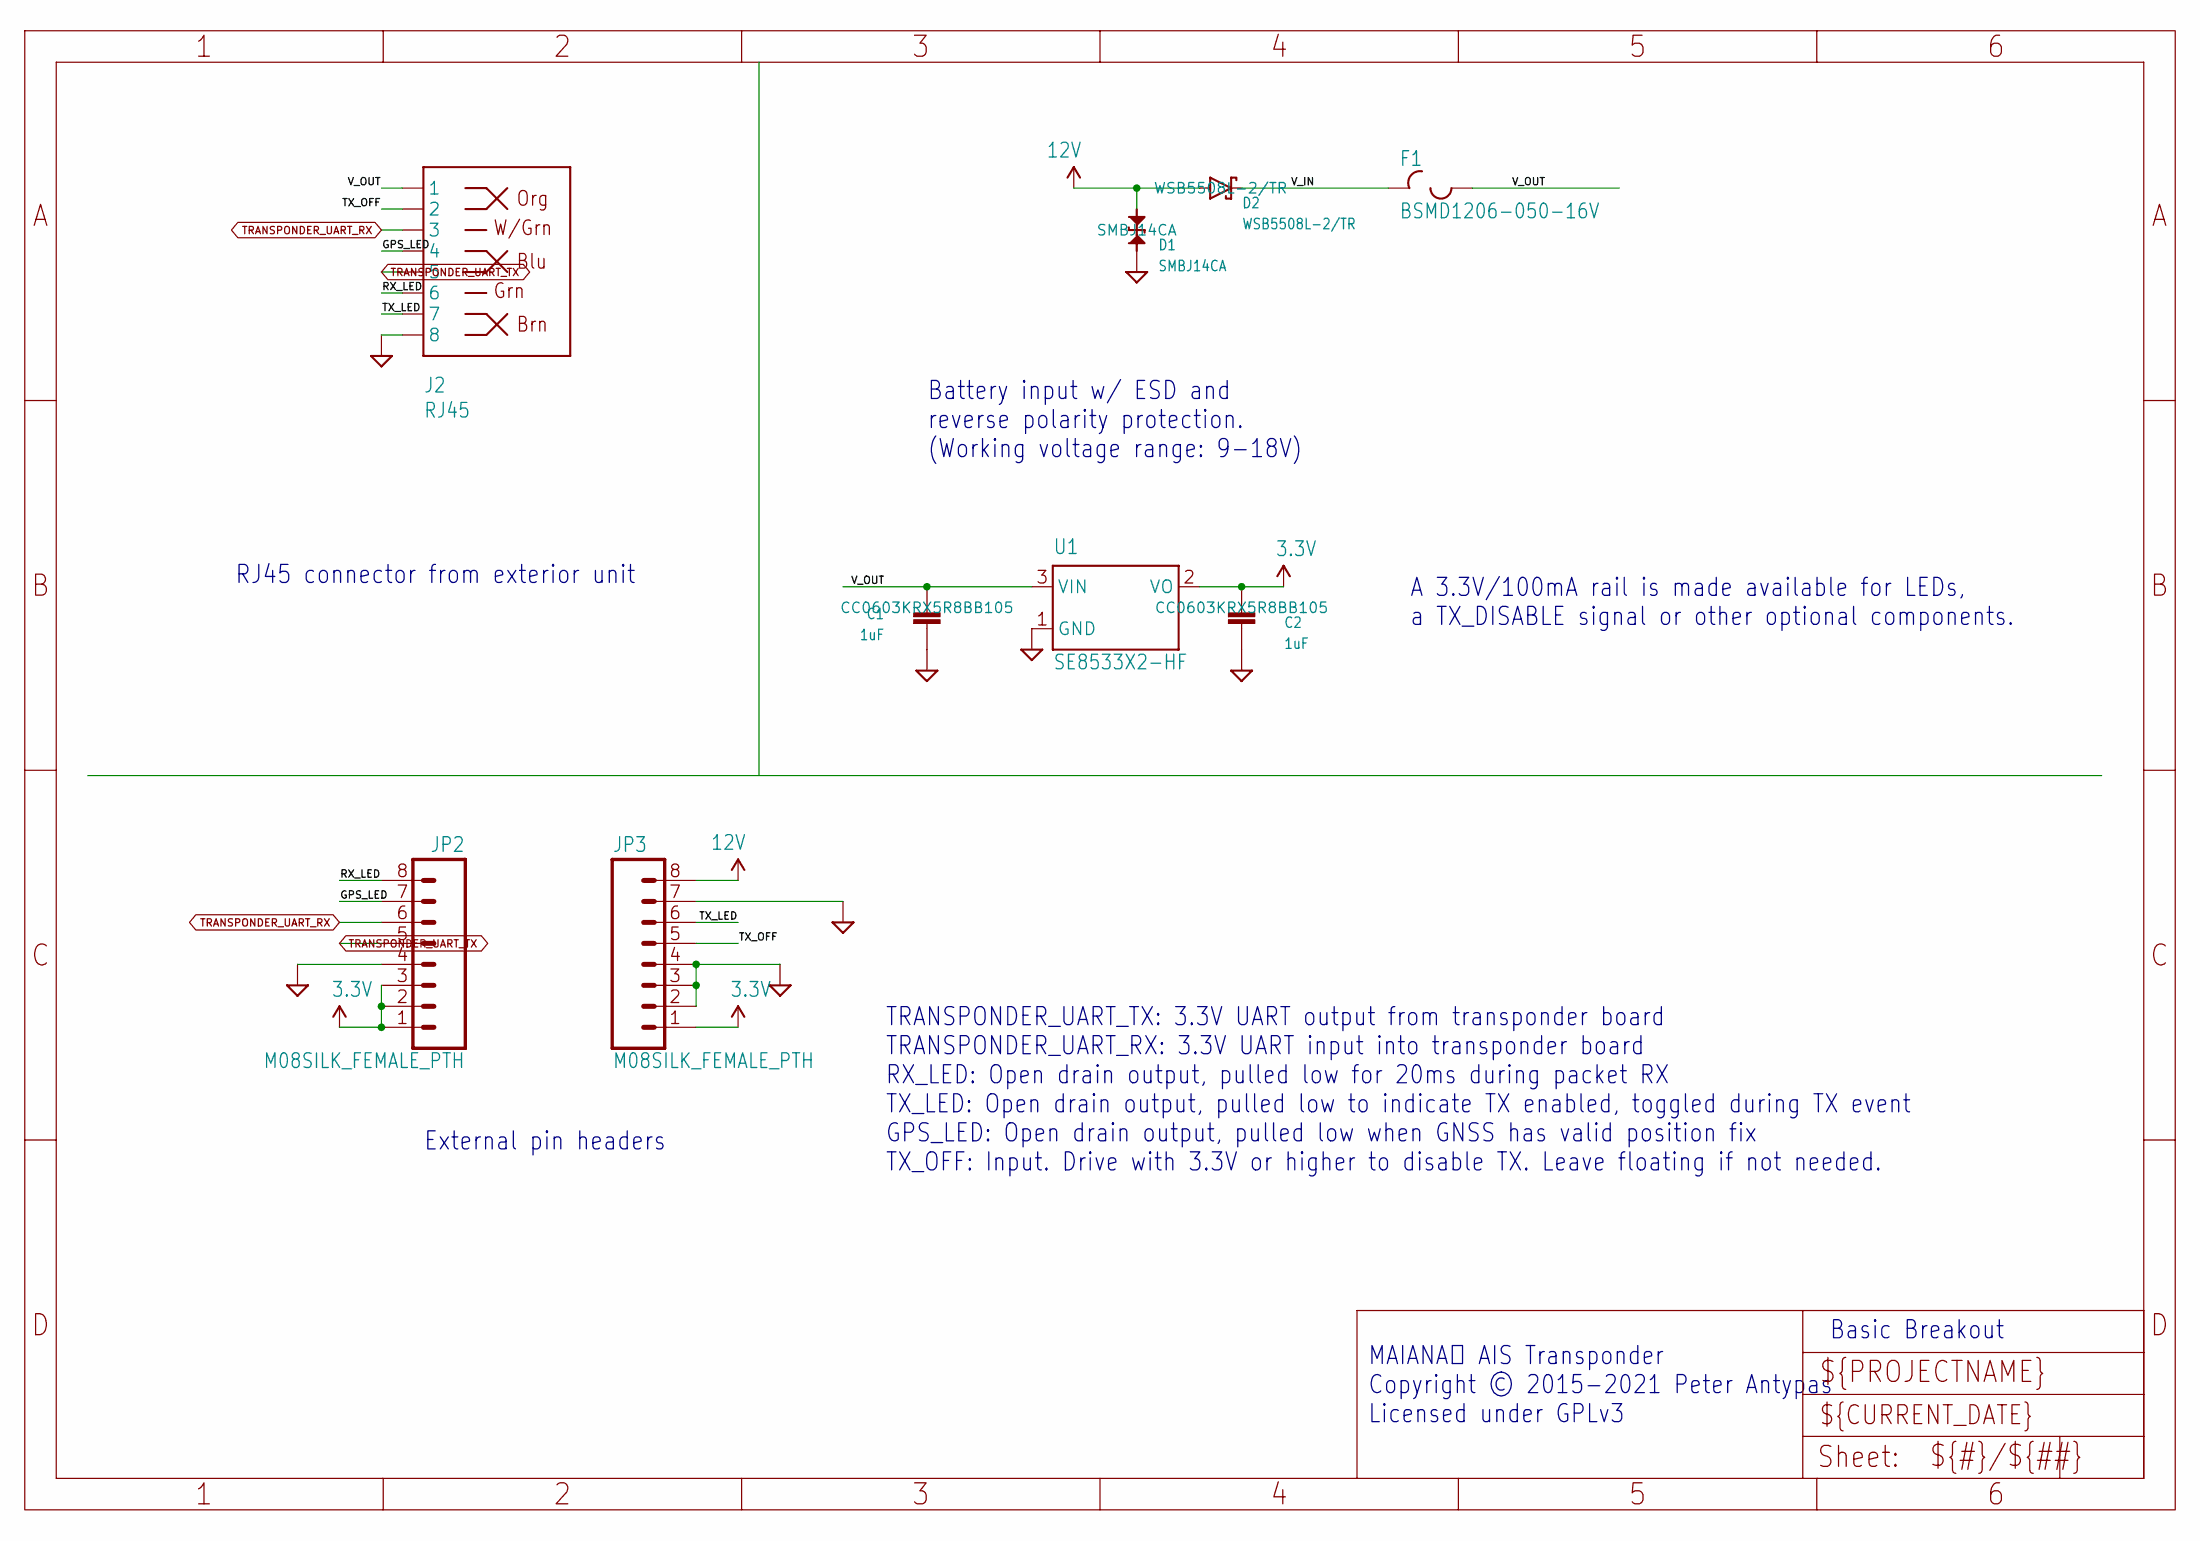
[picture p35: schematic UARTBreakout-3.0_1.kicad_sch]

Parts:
C1, C2: 1uF; 0603; PARTNO CC0603KRX5R8BB105
D1: SMBJ14CA; SMB-BIDIR; PARTNO SMBJ14CA
D2: WSB5508L-2/TR; SOD123; PARTNO WSB5508L-2/TR
F1: BSMD1206-050-16V; R1206; PARTNO BSMD1206-050-16V
J2: RJ45; RJ45-8; PARTNO 95501-2821
JP2, JP3: M08SILK_FEMALE_PTH; 1X08
U1: SE8533X2-HF; SOT23; PARTNO SE8533X2-HF

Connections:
3.3V: C2.P$1 (1), JP2.1, JP2.2, JP2.3, JP3.1, U1.2 (VO)
12V: D1.A, D2.A, JP3.8
/UARTBreakout-3.0_1/GPS_LED: J2.4, JP2.7
/UARTBreakout-3.0_1/RX_LED: J2.6, JP2.8
/UARTBreakout-3.0_1/TX_LED: J2.7, JP3.6
/UARTBreakout-3.0_1/TX_OFF: J2.2, JP3.5
/UARTBreakout-3.0_1/V_IN: D2.C, F1.1
/UARTBreakout-3.0_1/V_OUT: C1.P$1 (1), F1.2, J2.1, U1.3 (VIN)
GND: C1.P$2 (2), C2.P$2 (2), D1.C, J2.8, JP2.4, JP3.2, JP3.3, JP3.4, JP3.7, U1.1 (GND); also elsewhere on the board
TRANSPONDER_UART_RX: J2.3, JP2.6; also elsewhere on the board
TRANSPONDER_UART_TX: J2.5, JP2.5; also elsewhere on the board

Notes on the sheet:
TRANSPONDER_UART_TX: 3.3V UART output from transponder board TRANSPONDER_UART_RX: 3.3V UART input into transponder board RX_LED: Open drain output, pulled low for 20ms during packet RX TX_LED: Open drain output, pulled low to indicate TX enabled, toggled during TX event GPS_LED: Open drain output, 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
RJ45 connector from exterior unit
Basic Breakout
Battery input w/ ESD and reverse polarity protection. (Working voltage range: 9-18V)
A 3.3V/100mA rail is made available for LEDs, a TX_DISABLE signal or other optional components.
External pin headers
MAIANA™ AIS Transponder Copyright © 2015-2021 Peter Antypas Licensed under GPLv3

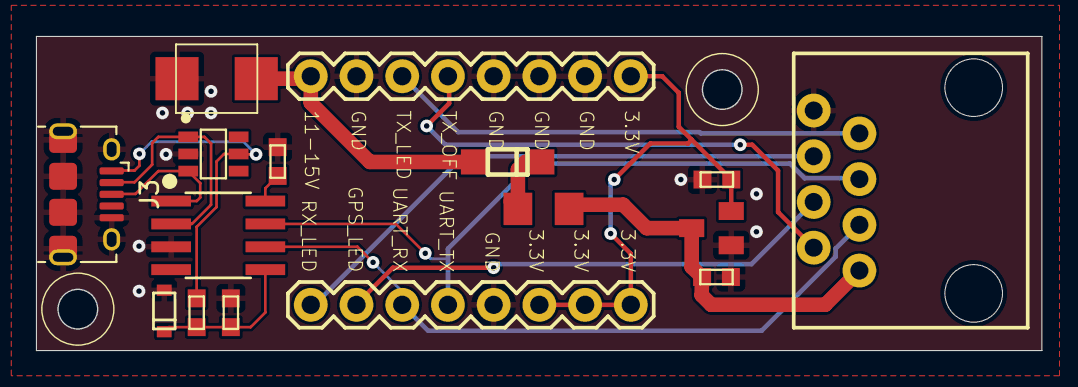
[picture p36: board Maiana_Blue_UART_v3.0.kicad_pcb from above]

Board: 2 copper layers, 55.9 x 17.5 mm, 16 parts (0 on the bottom side), 16 nets.

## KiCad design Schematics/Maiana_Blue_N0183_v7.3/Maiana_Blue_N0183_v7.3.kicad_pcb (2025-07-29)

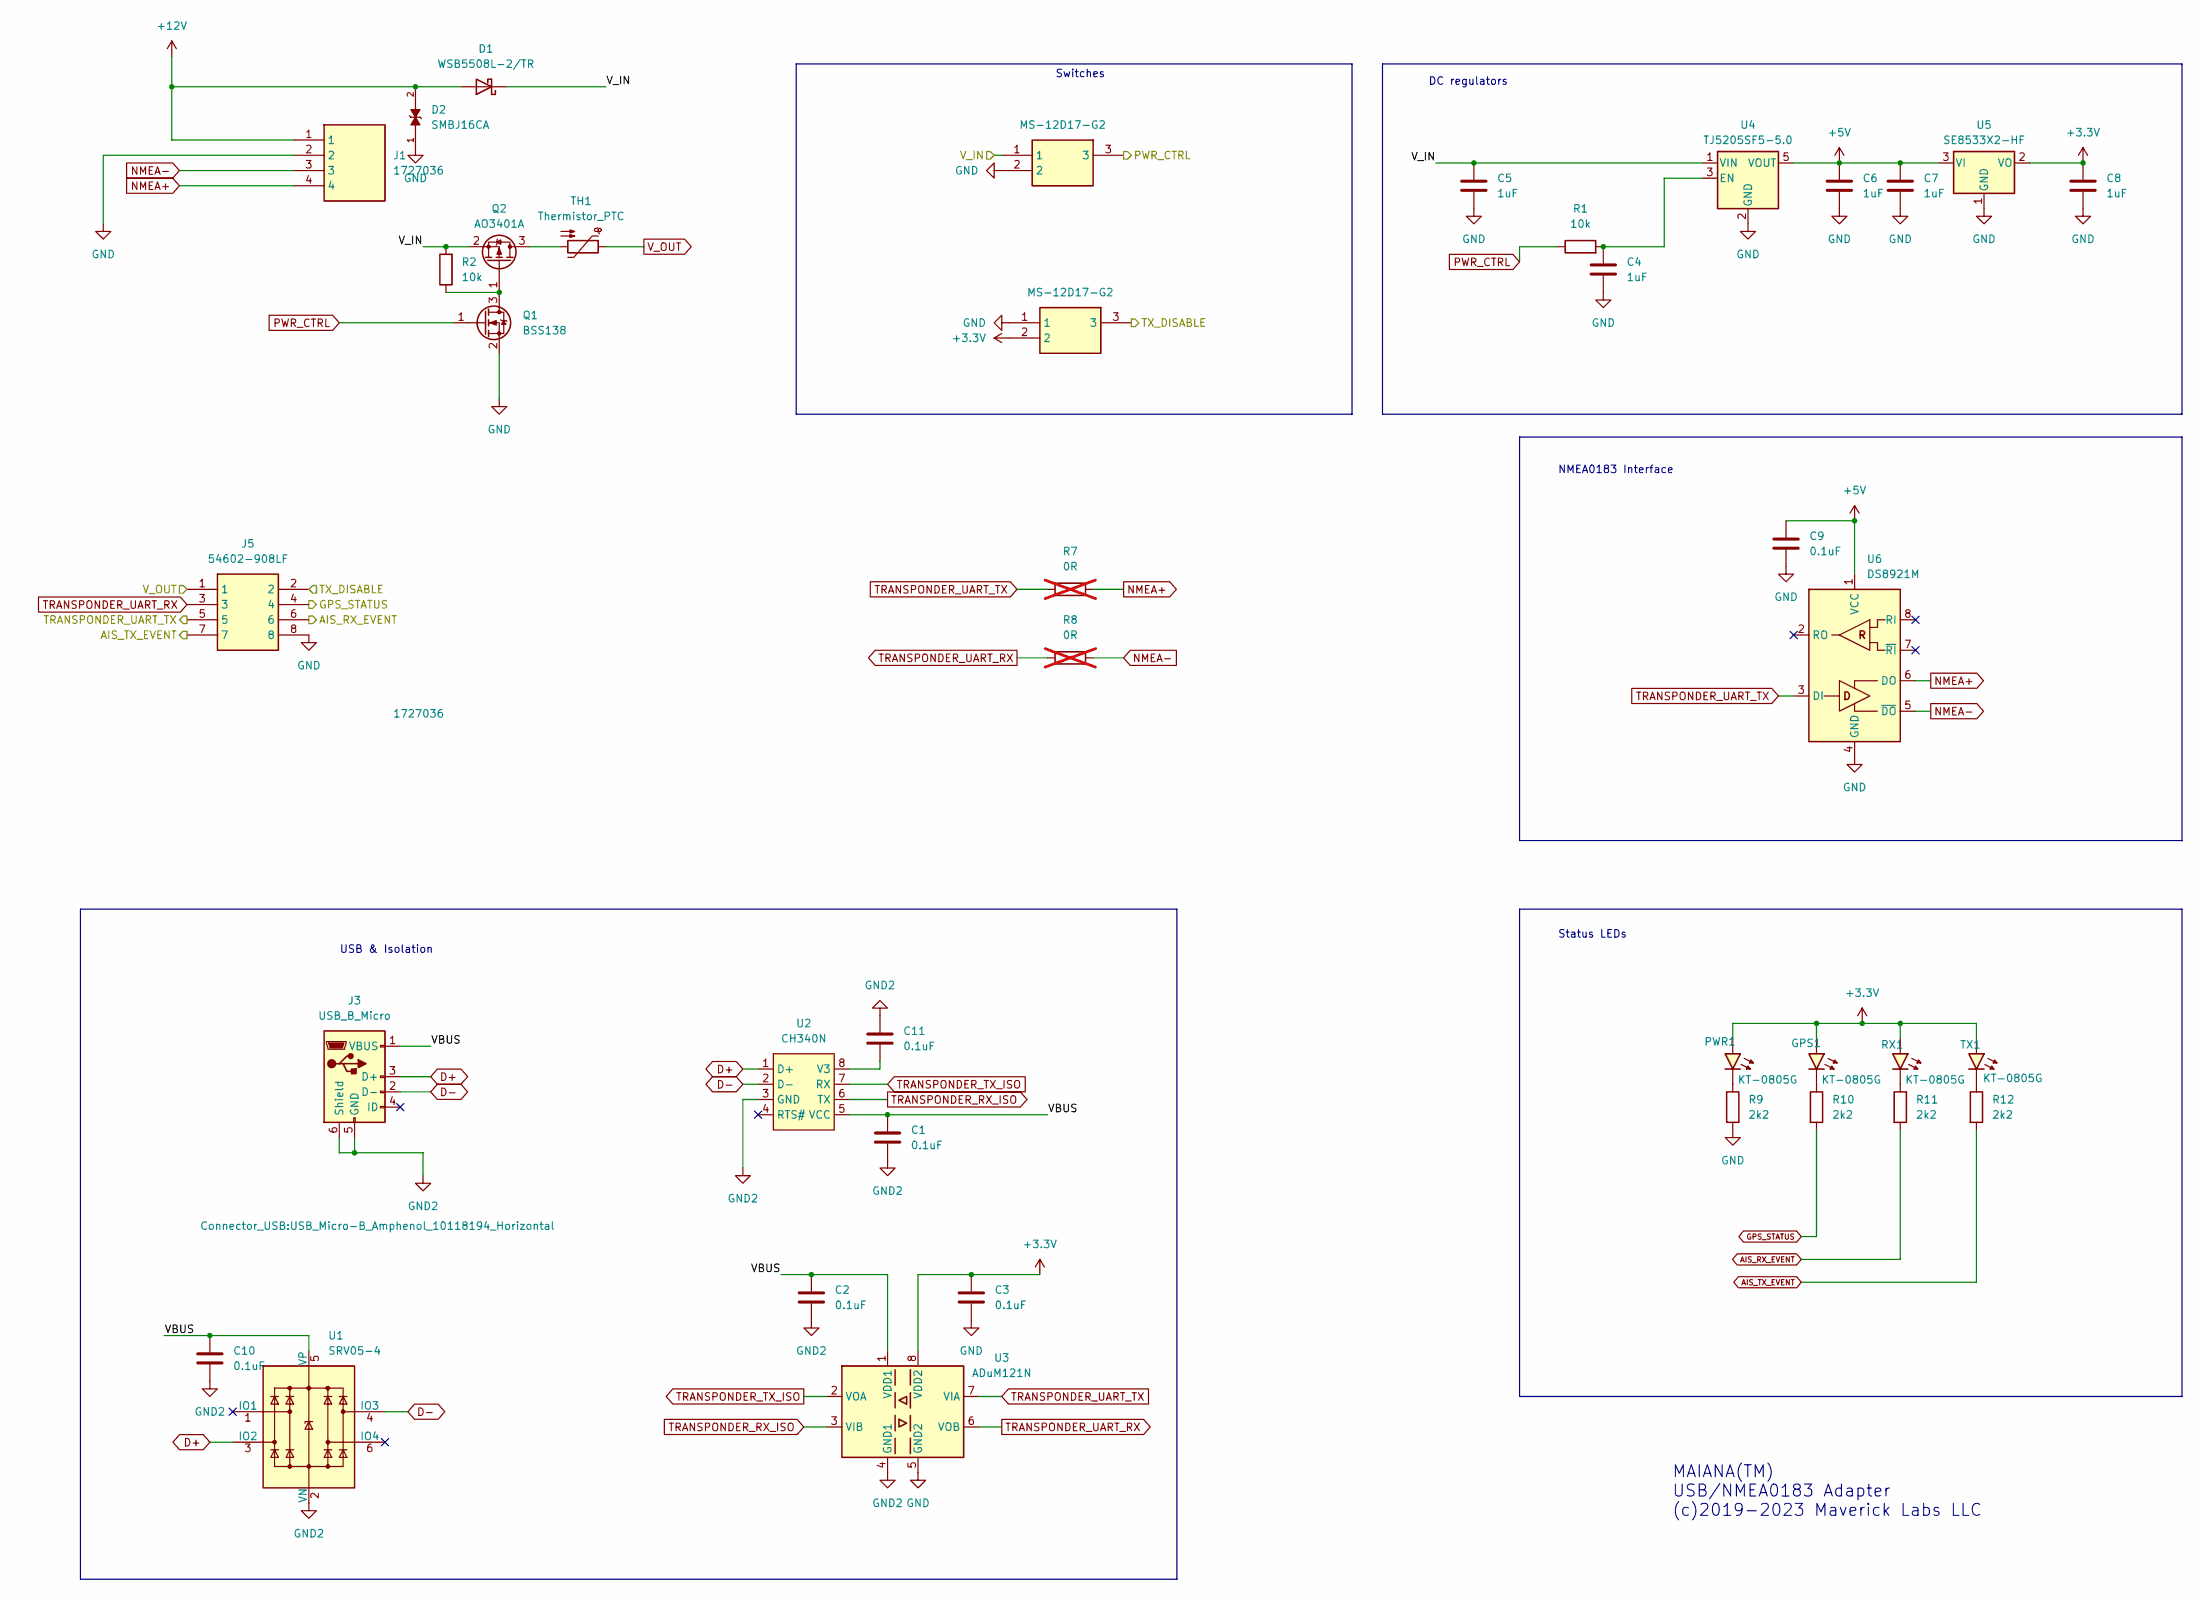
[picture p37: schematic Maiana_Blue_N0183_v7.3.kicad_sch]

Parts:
C1, C2, C3, C9, C10, C11: 0.1uF; C_0603_1608Metric
C4, C5, C6, C7, C8: 1uF; C_0603_1608Metric
D1: WSB5508L-2/TR; D_SOD-123
D2: SMBJ16CA; D_SMB; PARTREV I2102
GPS1: KT-0805G; LED_0805_2012Metric
J1: 1727036; Manufacturer_Part_Number 1727036; Mouser Part Number 651-1727036
J3: USB_B_Micro; USB_Micro-B_Amphenol_10118194_Horizontal
J5: 54602-908LF; RJ45_Amphenol_54602-x08_Horizontal; Manufacturer_Part_Number 54602-908LF
PWR1: KT-0805G; LED_0805_2012Metric
Q1: BSS138; SOT-23
Q2: AO3401A; SOT-23
R1, R2: 10k; R_0603_1608Metric
R7, R8: 0R; R_0603_1608Metric; not fitted
R9, R10, R11, R12: 2k2; R_0603_1608Metric
RX1: KT-0805G; LED_0805_2012Metric
S3, S4: MS-12D17-G2; MS12D17G2; Manufacturer_Part_Number MS-12D17-G2
TH1: Thermistor_PTC; R_1206_3216Metric
TX1: KT-0805G; LED_0805_2012Metric
U1: SRV05-4; SOT-23-6
U2: CH340N; SO-8_3.9x4.9mm_P1.27mm
U3: ADuM121N; SOIC-8_3.9x4.9mm_P1.27mm
U4: TJ5205SF5-5.0; SOT-23-5
U5: SE8533X2-HF; SOT-23
U6: DS8921M; SOIC-8_3.9x4.9mm_P1.27mm

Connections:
+3.3V: C3.1, C8.1, GPS1.2 (A), PWR1.2 (A), RX1.2 (A), S4.2, TX1.2 (A), U3.8 (VDD2), U5.2 (VO)
+5V: C6.1, C7.1, C9.1, U4.5 (VOUT), U5.3 (VI), U6.1 (VCC)
+12V: D1.2 (A), D2.2, J1.1
/TX_DISABLE: J5.2, S4.3
/VBUS: C1.1, C2.1, C10.1, J3.1 (VBUS), U1.5 (VP), U2.5 (VCC), U3.1 (VDD1)
/V_IN: C5.1, D1.1 (K), Q2.2 (S), R2.2, S3.1, U4.1 (VIN)
AIS_RX_EVENT: J5.6, R11.2
AIS_TX_EVENT: J5.7, R12.2
D+: J3.3 (D+), U1.3 (IO2), U2.1 (D+)
D-: J3.2 (D-), U1.4 (IO3), U2.2 (D-)
GND: C3.2, C4.2, C5.2, C6.2, C7.2, C8.2, C9.2, D2.1, J1.2, J5.8, Q1.2 (S), R9.2, S3.2, S4.1, U3.5 (GND2), U4.2 (GND), U5.1 (GND), U6.4 (GND)
GND2: C1.2, C2.2, C10.2, C11.1, J3.5 (GND), J3.6 (Shield), U1.2 (VN), U2.3 (GND), U3.4 (GND1)
GPS_STATUS: J5.4, R10.2
NMEA+: J1.4, R7.1, U6.6 (DO)
NMEA-: J1.3, R8.1, U6.5 (~DO)
unnamed: GPS1.1 (K), R10.1
unnamed: PWR1.1 (K), R9.1
unnamed: Q1.3 (D), Q2.1 (G), R2.1
unnamed: Q2.3 (D), TH1.2
unnamed: R11.1, RX1.1 (K)
unnamed: R12.1, TX1.1 (K)
unnamed: C11.2, U2.8 (V3)
unnamed: C4.1, R1.2, U4.3 (EN)
PWR_CTRL: Q1.1 (G), R1.1, S3.3
TRANSPONDER_RX_ISO: U2.6 (TX), U3.3 (VIB)
TRANSPONDER_TX_ISO: U2.7 (RX), U3.2 (VOA)
TRANSPONDER_UART_RX: J5.3, R8.2, U3.6 (VOB)
TRANSPONDER_UART_TX: J5.5, R7.2, U3.7 (VIA), U6.3 (DI)
V_OUT: J5.1, TH1.1

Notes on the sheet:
USB & Isolation
Status LEDs
MAIANA(TM) USB/NMEA0183 Adapter (c)2019-2023 Maverick Labs LLC
NMEA0183 Interface
DC regulators
Switches

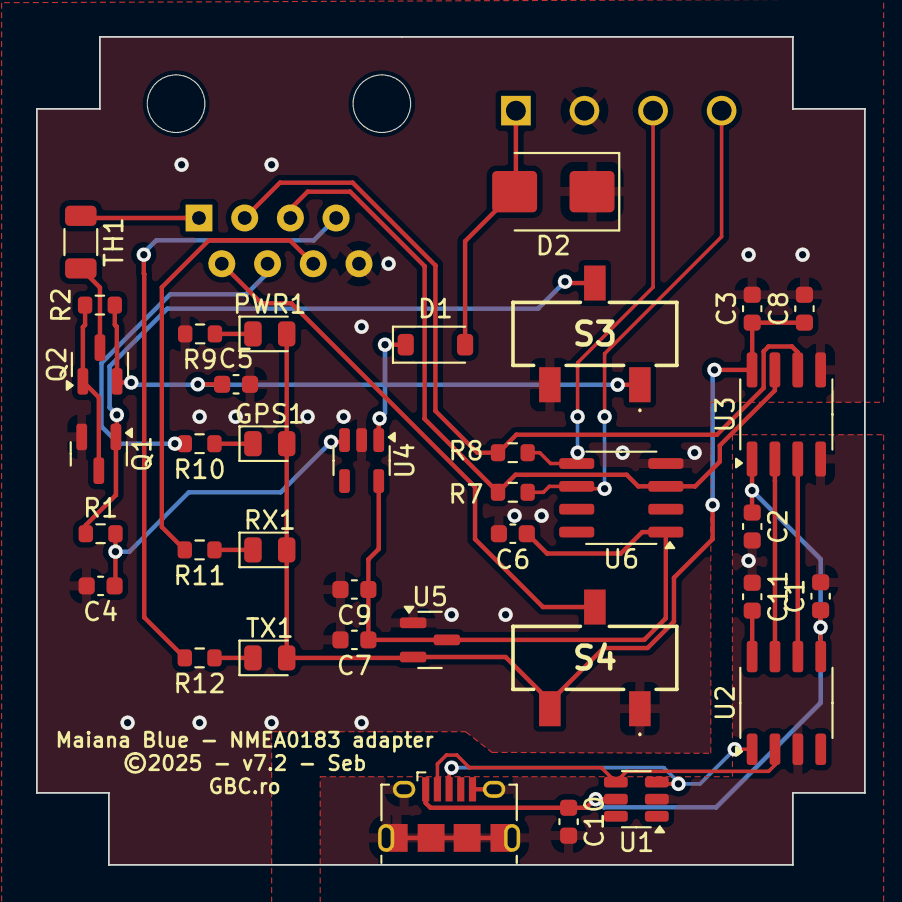
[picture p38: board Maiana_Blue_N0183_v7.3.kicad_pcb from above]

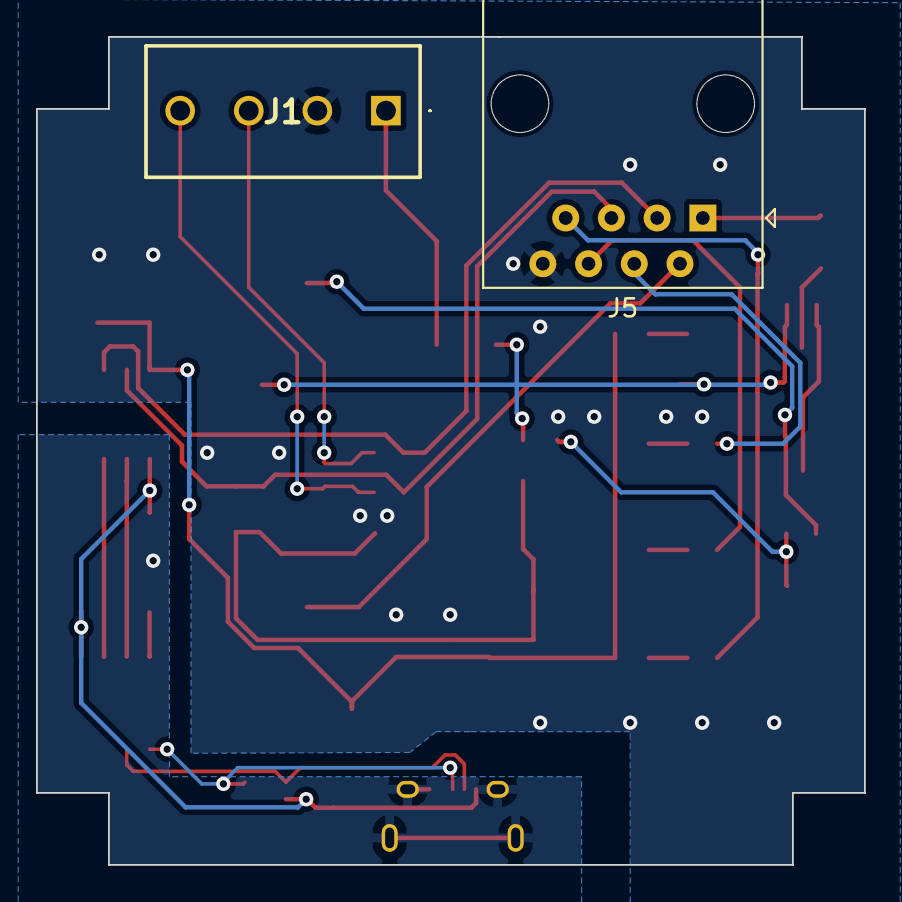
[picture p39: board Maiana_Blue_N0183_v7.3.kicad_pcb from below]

Board: 2 copper layers, 46.0 x 46.0 mm, 39 parts (2 on the bottom side), 29 nets.

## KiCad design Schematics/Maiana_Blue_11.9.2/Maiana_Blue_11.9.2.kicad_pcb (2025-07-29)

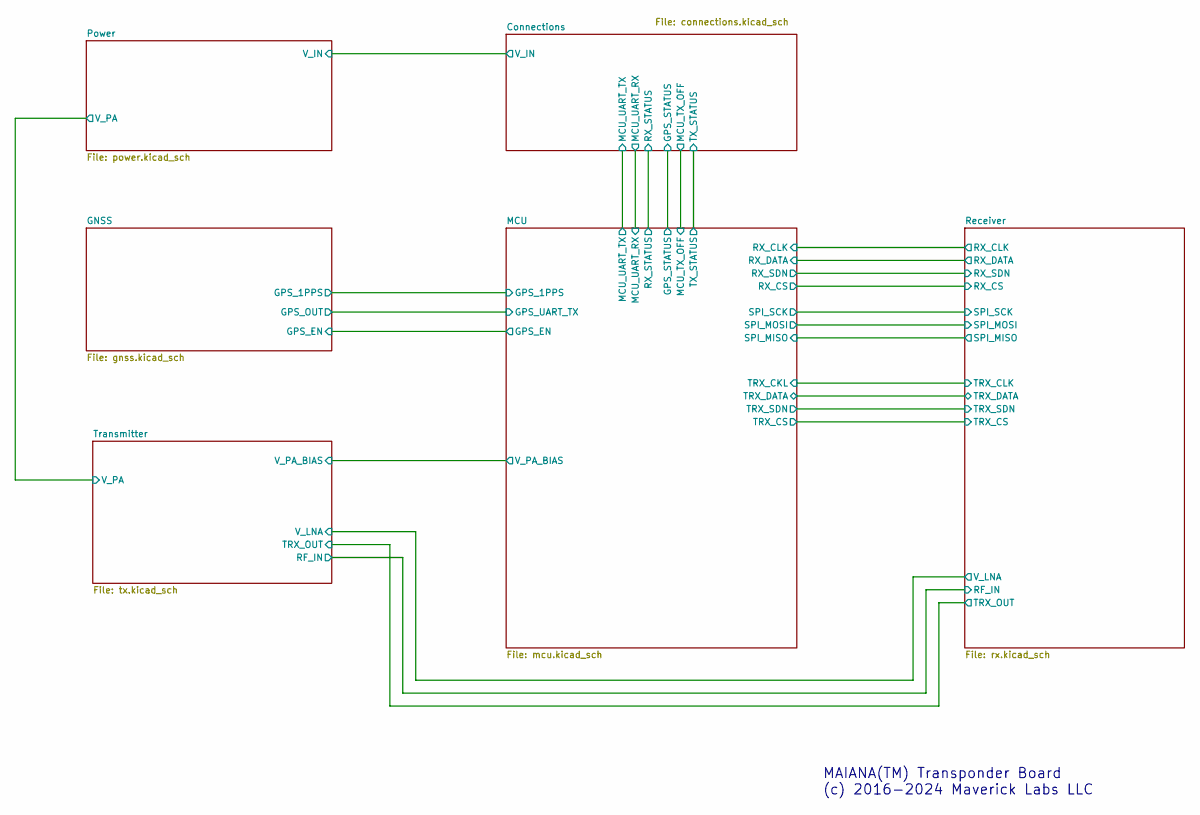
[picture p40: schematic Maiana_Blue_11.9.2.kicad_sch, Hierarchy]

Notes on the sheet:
MAIANA(TM) Transponder Board (c) 2016-2024 Maverick Labs LLC

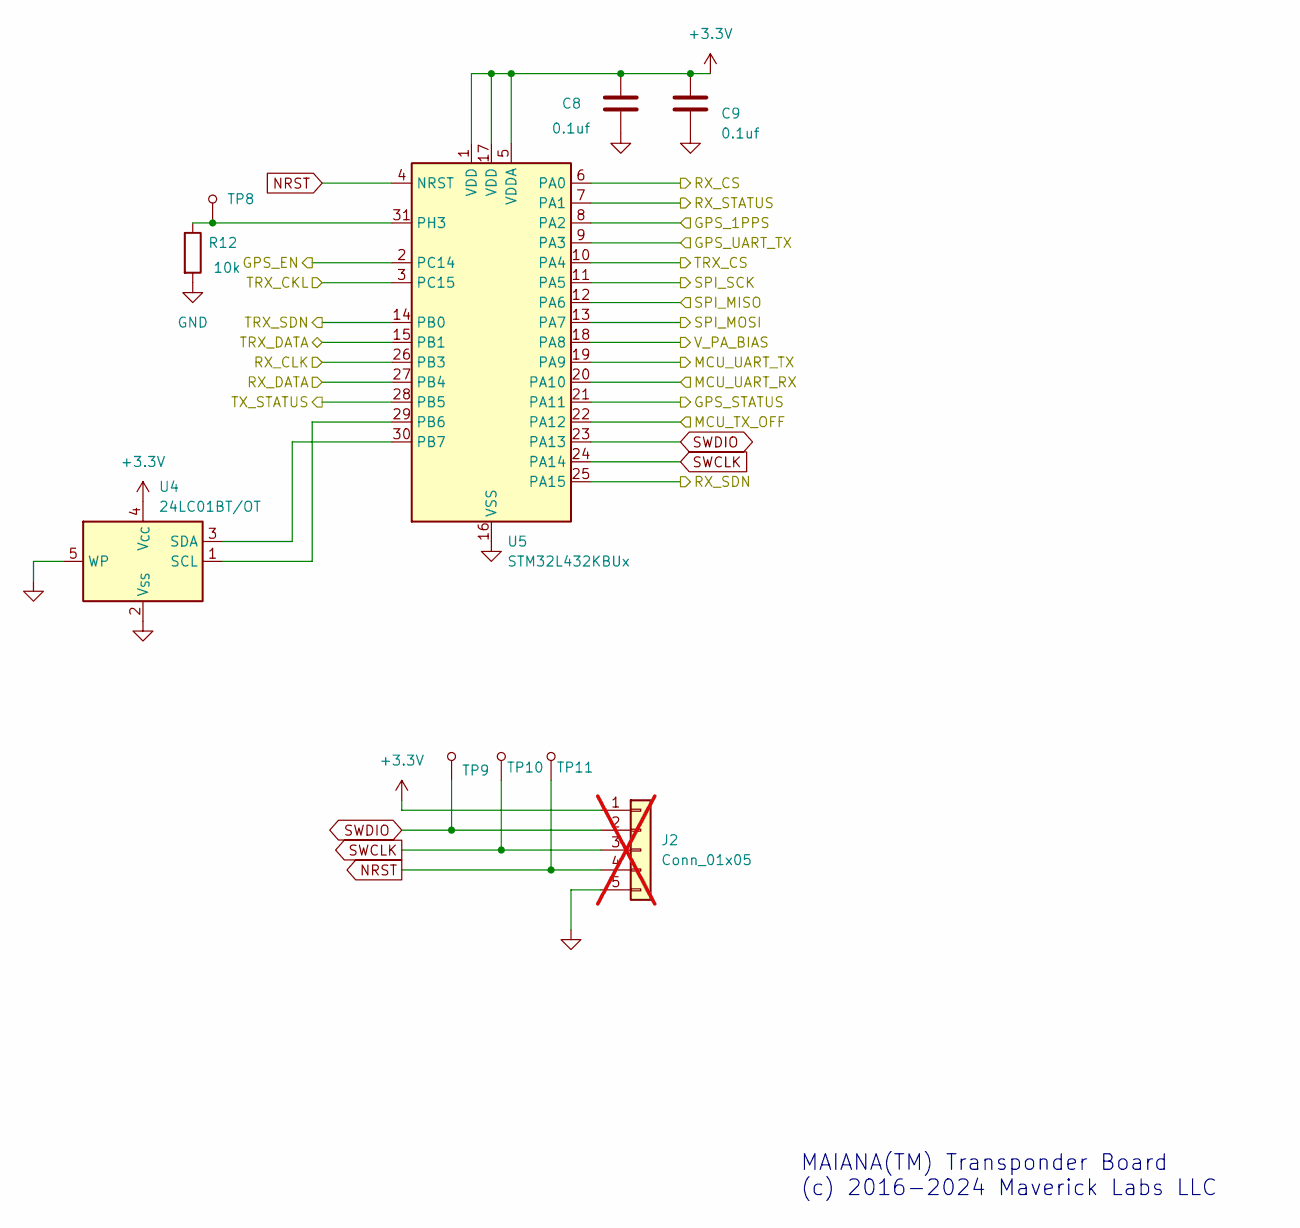
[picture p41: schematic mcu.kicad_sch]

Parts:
C8, C9: 0.1uf; C_0603_1608Metric
J2: Conn_01x05; PinHeader_1x05_P2.54mm_Vertical; not fitted
R12: 10k; R_0603_1608Metric
TP8, TP9, TP10, TP11: TP_1.2MM
U4: 24LC01BT/OT; SOT-23-5
U5: STM32L432KBUx; QFN-32-1EP_5x5mm_P0.5mm_EP3.45x3.45mm

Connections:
+3.3V: C8.2, C9.2, J2.1, U4.4 (V_{CC}), U5.1 (VDD), U5.5 (VDDA), U5.17 (VDD); also elsewhere on the board
/Connections/GPS_STATUS: U5.21 (PA11); also elsewhere on the board
/Connections/MCU_TX_OFF: U5.22 (PA12); also elsewhere on the board
/Connections/MCU_UART_RX: U5.20 (PA10); also elsewhere on the board
/Connections/MCU_UART_TX: U5.19 (PA9); also elsewhere on the board
/Connections/RX_STATUS: U5.7 (PA1); also elsewhere on the board
/Connections/TX_STATUS: U5.28 (PB5); also elsewhere on the board
/GNSS/GPS_1PPS: U5.8 (PA2); also elsewhere on the board
/GNSS/GPS_EN: U5.2 (PC14); also elsewhere on the board
/GNSS/GPS_OUT: U5.9 (PA3); also elsewhere on the board
/MCU/RX_CLK: U5.26 (PB3); also elsewhere on the board
/MCU/RX_CS: U5.6 (PA0); also elsewhere on the board
/MCU/RX_DATA: U5.27 (PB4); also elsewhere on the board
/MCU/RX_SDN: U5.25 (PA15); also elsewhere on the board
/MCU/SPI_MISO: U5.12 (PA6); also elsewhere on the board
/MCU/SPI_MOSI: U5.13 (PA7); also elsewhere on the board
/MCU/SPI_SCK: U5.11 (PA5); also elsewhere on the board
/MCU/TRX_CKL: U5.3 (PC15); also elsewhere on the board
/MCU/TRX_CS: U5.10 (PA4); also elsewhere on the board
/MCU/TRX_DATA: U5.15 (PB1); also elsewhere on the board
/MCU/TRX_SDN: U5.14 (PB0); also elsewhere on the board
/MCU/V_PA_BIAS: U5.18 (PA8); also elsewhere on the board
GND: C8.1, C9.1, J2.5, R12.2, U4.2 (V_{SS}), U4.5 (WP), U5.16 (VSS), U5.32 (VSS), U5.33 (VSS); also elsewhere on the board
NRST: J2.4, TP11.1, U5.4 (NRST)
unnamed: R12.1, TP8.1, U5.31 (PH3)
unnamed: U4.1 (SCL), U5.29 (PB6)
unnamed: U4.3 (SDA), U5.30 (PB7)
SWCLK: J2.3, TP10.1, U5.24 (PA14)
SWDIO: J2.2, TP9.1, U5.23 (PA13)

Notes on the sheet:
MAIANA(TM) Transponder Board (c) 2016-2024 Maverick Labs LLC

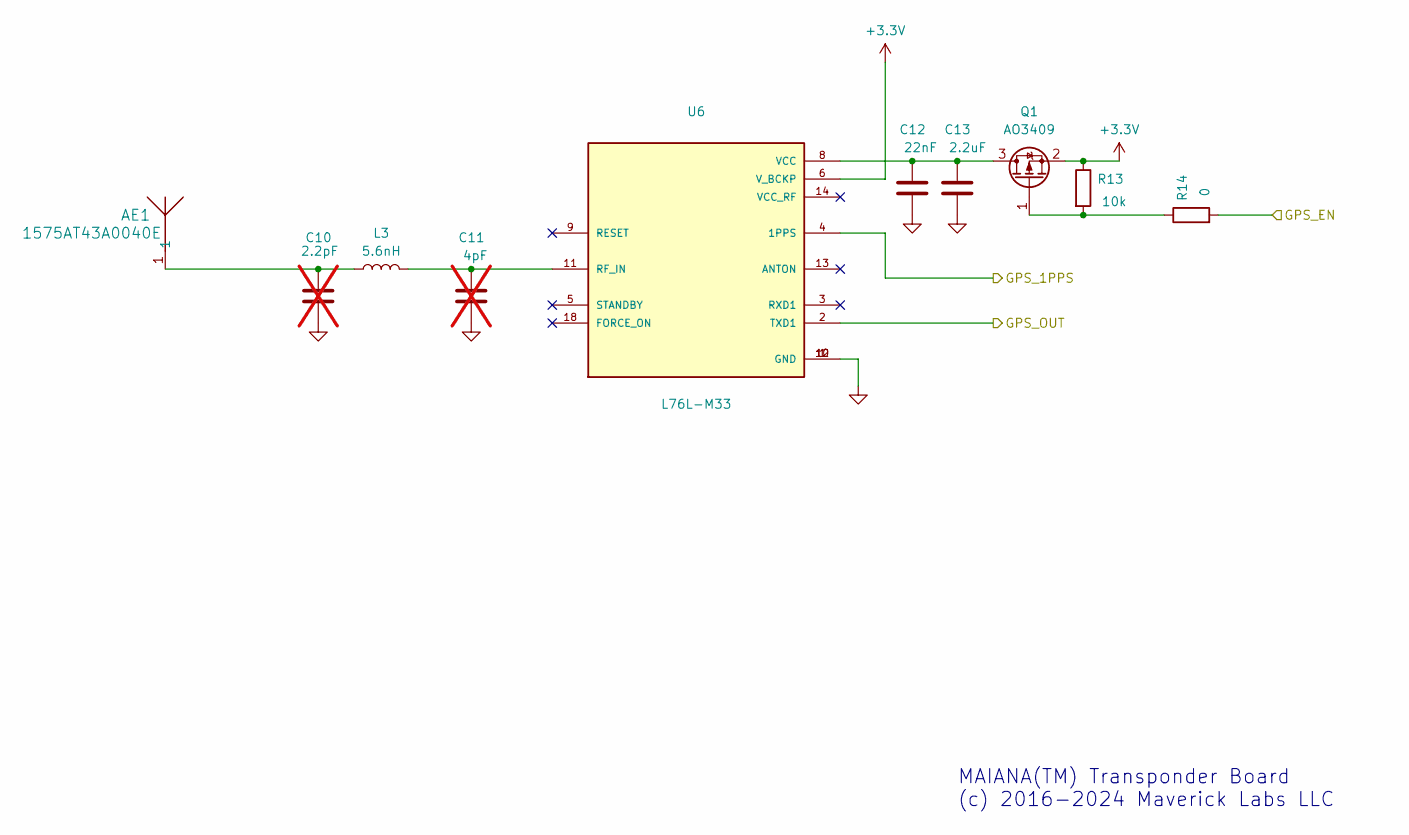
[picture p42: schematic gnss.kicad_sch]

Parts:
AE1: 1575AT43A0040E; ANT_1575AT_JOT
C10: 2.2pF; C_0603_1608Metric; not fitted
C11: 4pF; C_0603_1608Metric; not fitted
C12: 22nF; C_0603_1608Metric
C13: 2.2uF; C_0603_1608Metric
L3: 5.6nH; L_0603_1608Metric
Q1: AO3409; SOT-23
R13: 10k; R_0603_1608Metric
R14: 0; R_0603_1608Metric
U6: L76L-M33; XCVR_L76L-M33

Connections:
+3.3V: Q1.2 (S), R13.1, U6.6 (V_BCKP); also elsewhere on the board
/GNSS/GPS_1PPS: U6.4 (1PPS); also elsewhere on the board
/GNSS/GPS_EN: R14.2; also elsewhere on the board
/GNSS/GPS_OUT: U6.2 (TXD1); also elsewhere on the board
GND: C10.1, C11.1, C12.1, C13.1, U6.1 (GND), U6.10 (GND), U6.12 (GND); also elsewhere on the board
unnamed: AE1.1, C10.2, L3.1
unnamed: C12.2, C13.2, Q1.3 (D), U6.8 (VCC)
unnamed: Q1.1 (G), R13.2, R14.1
unnamed: C11.2, L3.2, U6.11 (RF_IN)

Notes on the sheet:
MAIANA(TM) Transponder Board (c) 2016-2024 Maverick Labs LLC

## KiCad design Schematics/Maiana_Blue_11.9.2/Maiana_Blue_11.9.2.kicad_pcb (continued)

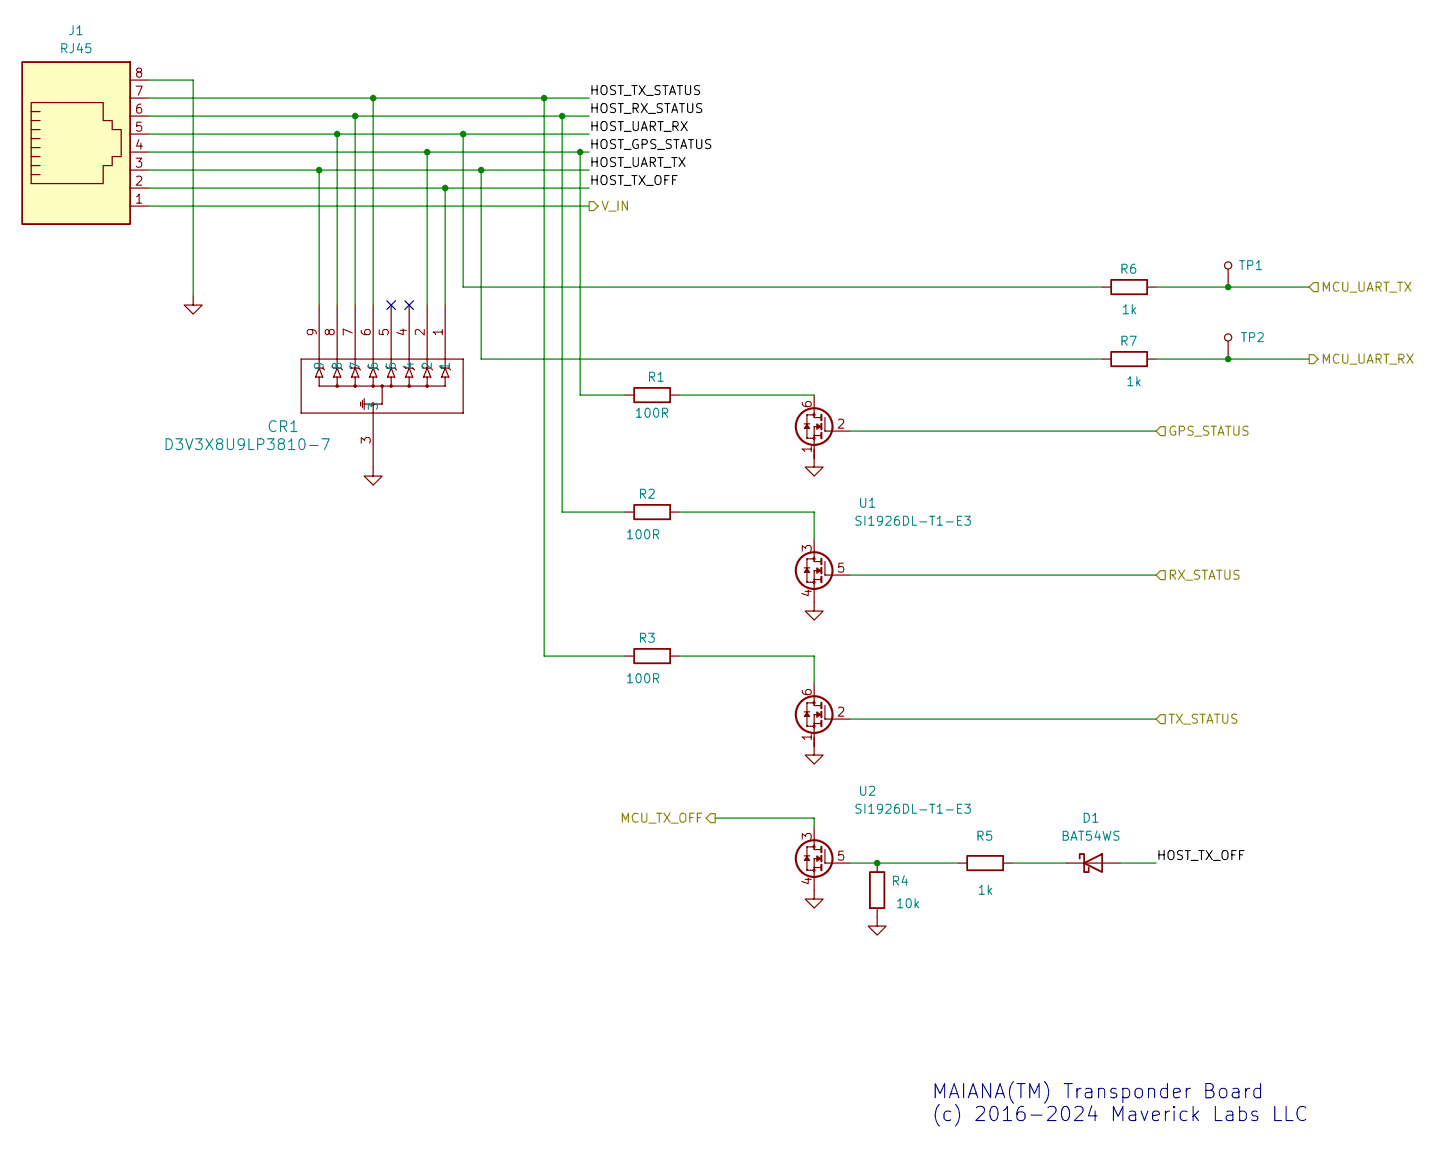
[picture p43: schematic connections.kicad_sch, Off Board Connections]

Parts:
CR1: D3V3X8U9LP3810-7; U-DFN3810-9TYPE_B_DIO
D1: BAT54WS; D_SOD-323
J1: RJ45; RJ45_Amphenol_54602-x08_Horizontal
R1, R2, R3: 100R; R_0603_1608Metric
R4: 10k; R_0603_1608Metric
R5, R6, R7: 1k; R_0603_1608Metric
TP1, TP2: TP_1.2MM
U1, U2: SI1926DL-T1-E3; SOT-363_SC-70-6

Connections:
/Connections/GPS_STATUS: U1.2 (G1); also elsewhere on the board
/Connections/HOST_GPS_STATUS: CR1.2, J1.4, R1.1
/Connections/HOST_RX_STATUS: CR1.7, J1.6, R2.1
/Connections/HOST_TX_OFF: CR1.1, D1.2 (A), J1.2
/Connections/HOST_TX_STATUS: CR1.6, J1.7, R3.1
/Connections/HOST_UART_RX: CR1.8, J1.5, R6.1
/Connections/HOST_UART_TX: CR1.9, J1.3, R7.1
/Connections/MCU_TX_OFF: U2.3 (D2); also elsewhere on the board
/Connections/MCU_UART_RX: R7.2, TP2.1; also elsewhere on the board
/Connections/MCU_UART_TX: R6.2, TP1.1; also elsewhere on the board
/Connections/RX_STATUS: U1.5 (G2); also elsewhere on the board
/Connections/TX_STATUS: U2.2 (G1); also elsewhere on the board
/Connections/V_IN: J1.1; also elsewhere on the board
GND: CR1.3, J1.8, R4.2, U1.1 (S1), U1.4 (S2), U2.1 (S1), U2.4 (S2); also elsewhere on the board
unnamed: D1.1 (K), R5.2
unnamed: R1.2, U1.6 (D1)
unnamed: R2.2, U1.3 (D2)
unnamed: R3.2, U2.6 (D1)
unnamed: R4.1, R5.1, U2.5 (G2)

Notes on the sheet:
MAIANA(TM) Transponder Board (c) 2016-2024 Maverick Labs LLC

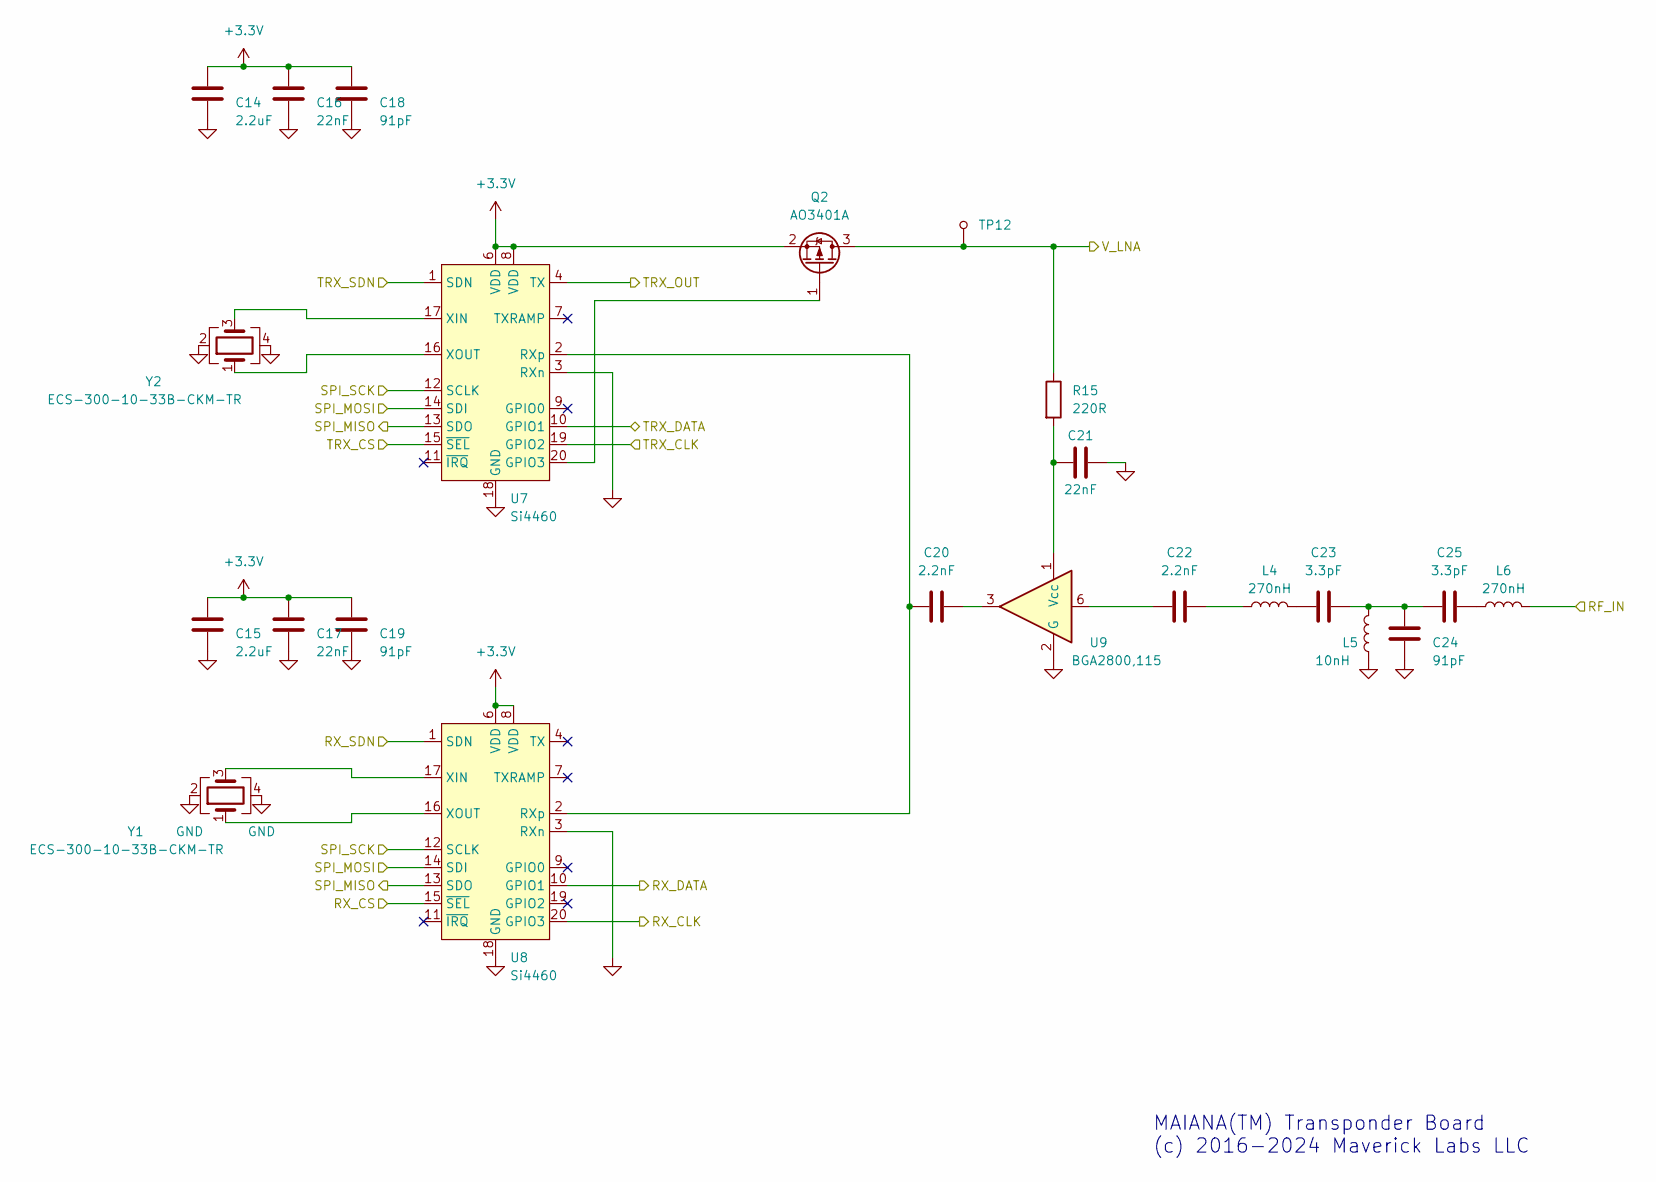
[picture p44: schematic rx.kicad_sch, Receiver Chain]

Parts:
C14, C15: 2.2uF; C_0603_1608Metric
C16, C17, C21: 22nF; C_0603_1608Metric
C18, C19, C24: 91pF; C_0603_1608Metric
C20, C22: 2.2nF; C_0603_1608Metric
C23, C25: 3.3pF; C_0603_1608Metric
L4, L6: 270nH; L_0603_1608Metric
L5: 10nH; L_0603_1608Metric
Q2: AO3401A; SOT-23
R15: 220R; R_0603_1608Metric
TP12: TP_1.2MM
U7, U8: Si4460; QFN-20-1EP_4x4mm_P0.5mm_EP2.6x2.6mm_ThermalVias
U9: BGA2800,115; SOT-363_SC-70-6
Y1, Y2: ECS-300-10-33B-CKM-TR; Crystal_SMD_3225-4Pin_3.2x2.5mm

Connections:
+3.3V: C14.2, C15.2, C16.2, C17.2, C18.2, C19.2, Q2.2 (S), U7.6 (VDD), U7.8 (VDD), U8.6 (VDD), U8.8 (VDD); also elsewhere on the board
/MCU/RX_CLK: U8.20 (GPIO3); also elsewhere on the board
/MCU/RX_CS: U8.15 (~SEL); also elsewhere on the board
/MCU/RX_DATA: U8.10 (GPIO1); also elsewhere on the board
/MCU/RX_SDN: U8.1 (SDN); also elsewhere on the board
/MCU/SPI_MISO: U7.13 (SDO), U8.13 (SDO); also elsewhere on the board
/MCU/SPI_MOSI: U7.14 (SDI), U8.14 (SDI); also elsewhere on the board
/MCU/SPI_SCK: U7.12 (SCLK), U8.12 (SCLK); also elsewhere on the board
/MCU/TRX_CKL: U7.19 (GPIO2); also elsewhere on the board
/MCU/TRX_CS: U7.15 (~SEL); also elsewhere on the board
/MCU/TRX_DATA: U7.10 (GPIO1); also elsewhere on the board
/MCU/TRX_SDN: U7.1 (SDN); also elsewhere on the board
/Receiver/RF_IN: L6.2; also elsewhere on the board
/Receiver/TRX_OUT: U7.4 (TX); also elsewhere on the board
/Receiver/V_LNA: Q2.3 (D), R15.1, TP12.1; also elsewhere on the board
GND: C14.1, C15.1, C16.1, C17.1, C18.1, C19.1, C21.2, C24.1, L5.1, U7.3 (RXn), U7.18 (GND), U7.21 (GND), U8.3 (RXn), U8.18 (GND), U8.21 (GND), U9.2 (G), U9.4 (G), U9.5 (G), Y1.2, Y1.4, Y2.2, Y2.4; also elsewhere on the board
unnamed: C20.2, U9.3
unnamed: C22.1, U9.6
unnamed: C22.2, L4.1
unnamed: C23.1, C24.2, C25.1, L5.2
unnamed: C23.2, L4.2
unnamed: C25.2, L6.1
unnamed: Q2.1 (G), U7.20 (GPIO3)
unnamed: C20.1, U7.2 (RXp), U8.2 (RXp)
unnamed: U7.17 (XIN), Y2.3
unnamed: U7.16 (XOUT), Y2.1
unnamed: U8.17 (XIN), Y1.3
unnamed: U8.16 (XOUT), Y1.1
unnamed: C21.1, R15.2, U9.1 (Vcc)

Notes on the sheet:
MAIANA(TM) Transponder Board (c) 2016-2024 Maverick Labs LLC

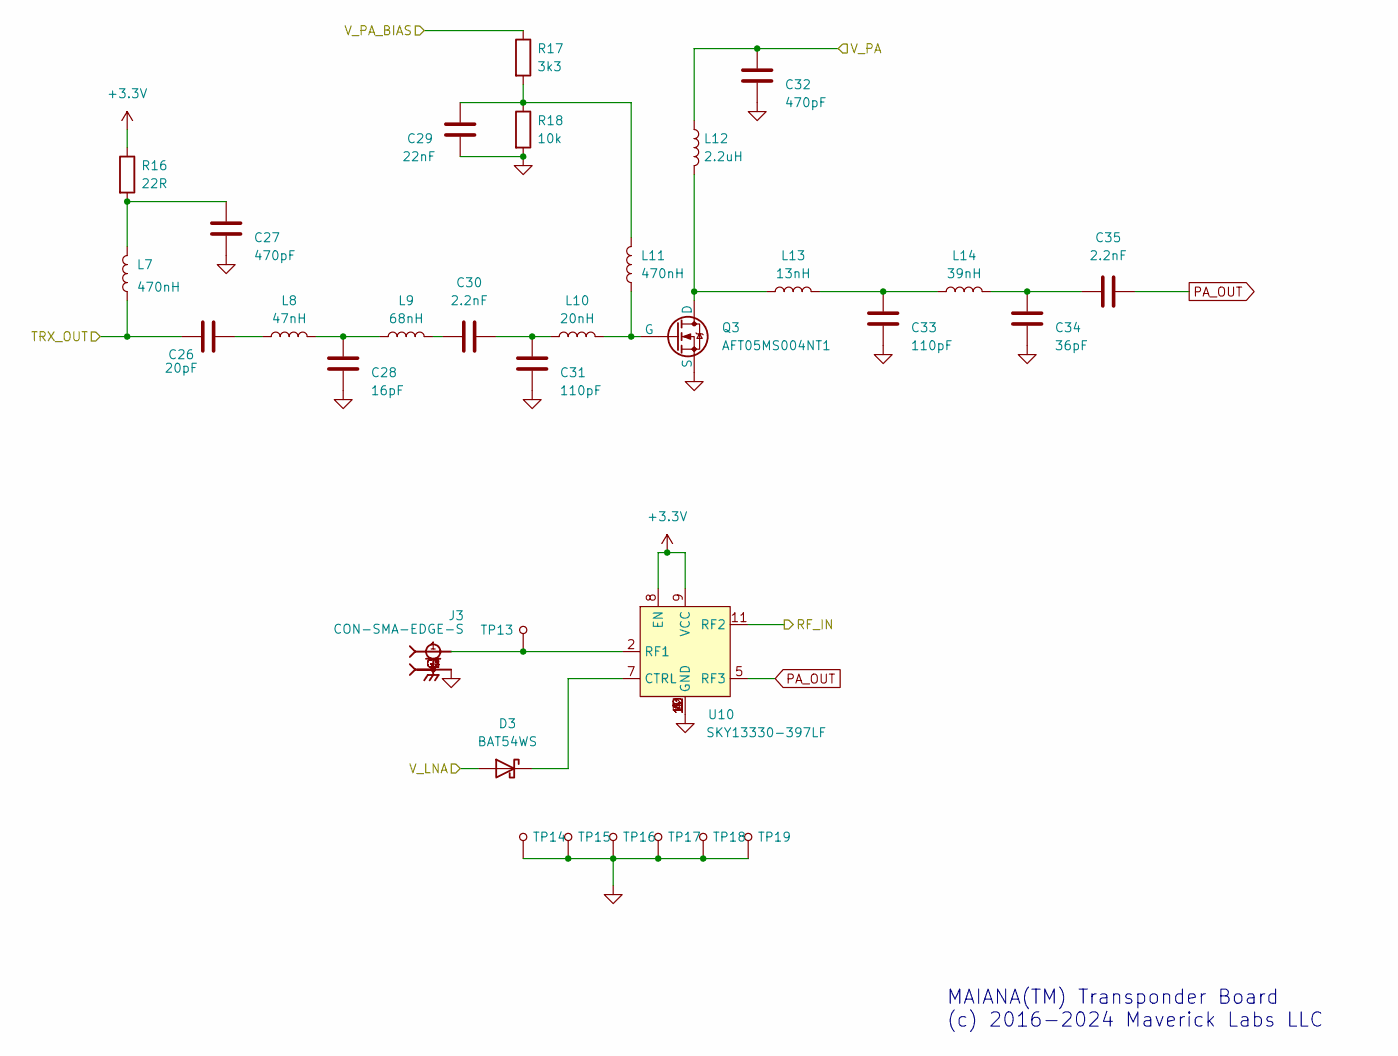
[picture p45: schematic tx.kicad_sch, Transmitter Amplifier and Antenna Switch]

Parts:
C26: 20pF; C_0603_1608Metric
C27, C32: 470pF; C_0603_1608Metric
C28: 16pF; C_0603_1608Metric
C29: 22nF; C_0603_1608Metric
C30, C35: 2.2nF; C_0603_1608Metric
C31, C33: 110pF; C_0603_1608Metric
C34: 36pF; C_0603_1608Metric
D3: BAT54WS; D_SOD-323
J3: CON-SMA-EDGE-S; RFSOLUTIONS_CON-SMA-EDGE-S; PARTREV 1; DigiKey_Part_Number CON-SMA-EDGE-S-ND
L7, L11: 470nH; L_0603_1608Metric
L8: 47nH; L_0603_1608Metric
L9: 68nH; L_0603_1608Metric
L10: 20nH; L_0603_1608Metric
L12: 2.2uH; L_0805_2012Metric
L13: 13nH; L_0603_1608Metric
L14: 39nH; L_0603_1608Metric
Q3: AFT05MS004NT1; SOT-89-3
R16: 22R; R_0603_1608Metric
R17: 3k3; R_0603_1608Metric
R18: 10k; R_0603_1608Metric
TP13: TP_1.0MM
TP14, TP15, TP16, TP17, TP18, TP19: TP_1.2MM
U10: SKY13330-397LF; QFN50P200X200X65-13N

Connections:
+3.3V: R16.1, U10.8 (EN), U10.9 (VCC); also elsewhere on the board
/MCU/V_PA_BIAS: R17.1; also elsewhere on the board
/Power/V_PA: C32.2, L12.1; also elsewhere on the board
/Receiver/RF_IN: U10.11 (RF2); also elsewhere on the board
/Receiver/TRX_OUT: C26.1, L7.1; also elsewhere on the board
/Receiver/V_LNA: D3.2 (A); also elsewhere on the board
GND: C27.1, C28.1, C29.1, C31.1, C32.1, C33.1, C34.1, J3.G1, J3.G2, J3.G3, J3.G4, Q3.2 (S), R18.2, TP14.1, TP15.1, TP16.1, TP17.1, TP18.1, TP19.1, U10.1 (GND), U10.3 (GND), U10.4 (GND), U10.6 (GND), U10.10 (GND), U10.12 (GND), U10.13 (GND); also elsewhere on the board
unnamed: C26.2, L8.1
unnamed: C27.2, L7.2, R16.2
unnamed: C28.2, L8.2, L9.1
unnamed: C29.2, L11.2, R17.2, R18.1
unnamed: C30.1, L9.2
unnamed: C30.2, C31.2, L10.1
unnamed: C33.2, L13.2, L14.1
unnamed: C34.2, C35.1, L14.2
unnamed: D3.1 (K), U10.7 (CTRL)
unnamed: L12.2, L13.1, Q3.3 (D)
unnamed: L10.2, L11.1, Q3.1 (G)
unnamed: J3.1, TP13.1, U10.2 (RF1)
PA_OUT: C35.2, U10.5 (RF3)

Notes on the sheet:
MAIANA(TM) Transponder Board (c) 2016-2024 Maverick Labs LLC


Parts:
C1, C2: 0.1uf; C_0603_1608Metric
C3: 10uF; C_0805_2012Metric
C4, C7: 2.2uF; C_0603_1608Metric
C5: 22nF; C_0603_1608Metric
C6: 22uF; C_0805_2012Metric
D2: BAT54WS; D_SOD-323
IC1: LDFPVR; SON65P200X200X100-7N-D; Mouser Part Number 511-LDFPVR
L1, L2: 4.7uH; R_0805_2012Metric
R8: 51k; R_0603_1608Metric
R9: 16k; R_0603_1608Metric
R10: 47k; R_0603_1608Metric
R11: 10k; R_0603_1608Metric
TP3, TP4, TP5, TP6, TP7: TP_1.2MM
U3: AP3211K; SOT-23-6

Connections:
+3.3V: C6.1, L2.2, R8.1, TP6.1; also elsewhere on the board
/Connections/V_IN: C1.2, C4.2, IC1.5 (EN), IC1.6 (VIN), L1.1, TP3.1; also elsewhere on the board
/Power/V_PA: C7.2, IC1.1 (VOUT), R10.1, TP7.1; also elsewhere on the board
GND: C1.1, C2.1, C3.2, C4.1, C6.2, C7.1, D2.2 (A), IC1.4 (GND_1), IC1.7 (GND_2), R9.2, R11.2, TP4.1, TP5.1, U3.2 (GND); also elsewhere on the board
unnamed: C5.2, D2.1 (K), L2.1, U3.6 (SW)
unnamed: IC1.2 (ADJ/NC), R10.2, R11.1
unnamed: C5.1, U3.1 (BS)
unnamed: C2.2, C3.1, L1.2, U3.4 (EN), U3.5 (IN)
unnamed: R8.2, R9.1, U3.3 (FB)

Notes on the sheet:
MAIANA(TM) Transponder Board (c) 2016-2024 Maverick Labs LLC


Board: 4 copper layers, 84.0 x 25.0 mm, 110 parts (0 on the bottom side), 80 nets.

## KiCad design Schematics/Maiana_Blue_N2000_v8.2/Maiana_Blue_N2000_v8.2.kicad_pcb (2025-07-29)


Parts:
GPS1: KT-0805G; LED_0805_2012Metric
J6: Conn_01x02; PinHeader_1x02_P2.54mm_Vertical; not fitted
PWR1: KT-0805G; LED_0805_2012Metric
R1, R2, R3, R4: 2k2; R_0603_1608Metric
RX1: KT-0805G; LED_0805_2012Metric
S1, S2: MS-12D17-G2; MS12D17G2; Manufacturer_Part_Number MS-12D17-G2
S3: SKSCLDE010; Manufacturer_Part_Number SKSCLDE010; Mouser Part Number 688-SKSCLDE010
SW1, SW2: CL-SB-12B-01T; not fitted
SW3: TS-1814; TE_1977066-1; PARTREV C1; not fitted
TX1: KT-0805G; LED_0805_2012Metric

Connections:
+3.3V: GPS1.2 (A), J6.1, PWR1.2 (A), RX1.2 (A), S2.2, S3.3 (NO), S3.4 (NO), SW2.1, SW3.2, TX1.2 (A); also elsewhere on the board
/Connections/AIS_RX_EVENT: R3.2; also elsewhere on the board
/Connections/AIS_TX_EVENT: R4.2; also elsewhere on the board
/Connections/GPS_STATUS: R2.2; also elsewhere on the board
/Connections/TX_DISABLE: S2.3, SW2.C; also elsewhere on the board
/MCU/BOOT0: J6.2, S3.1 (NO), S3.2 (NO), SW3.1, SW3.3; also elsewhere on the board
/Power/PWR_CTRL: S1.3, SW1.C; also elsewhere on the board
/Power/V_IN: S1.1, SW1.3; also elsewhere on the board
GND: R1.2, S1.2, S2.1, SW1.1, SW2.3, SW3.S1 (SHIELD), SW3.S2 (SHIELD); also elsewhere on the board
unnamed: GPS1.1 (K), R2.1
unnamed: PWR1.1 (K), R1.1
unnamed: R3.1, RX1.1 (K)
unnamed: R4.1, TX1.1 (K)


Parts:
C1, C2, C3: 0.1uF; C_0603_1608Metric
J1: 12-3701-05; MICRO_C_5PIN; PARTNO 12-3701-05
J2: RJ-82A86MMNL; PARTNO RJ-82A86MMNL; not fitted
J3: USB_B_Micro; USB_Micro-B_Amphenol_10118194_Horizontal
J4: Conn_01x02; PinHeader_1x02_P2.54mm_Vertical; not fitted
J5: 54602-908LF; 54602908LF; Manufacturer_Part_Number 54602-908LF
R11, R12: 0R; R_0603_1608Metric
U4: SRV05-4; SOT-23-6
U5: CH340N; SO-8_3.9x4.9mm_P1.27mm
U6: ISO7721FDR; SOIC-8_3.9x4.9mm_P1.27mm

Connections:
+3.3V: C2.1, U6.8 (VDD2); also elsewhere on the board
+12V: J1.2, J4.1; also elsewhere on the board
/CAN/CAN_H: J1.4; also elsewhere on the board
/CAN/CAN_L: J1.5; also elsewhere on the board
/Connections/AIS_RX_EVENT: J2.P$6 (6), J5.6; also elsewhere on the board
/Connections/AIS_TX_EVENT: J2.P$7 (7), J5.7; also elsewhere on the board
/Connections/GPS_STATUS: J2.P$4 (4), J5.4; also elsewhere on the board
/Connections/MCU_UART_RX: R12.2; also elsewhere on the board
/Connections/MCU_UART_TX: R11.2; also elsewhere on the board
/Connections/TRANSPONDER_UART_TX: J2.P$5 (5), J5.5, R11.1, U6.7 (VIA); also elsewhere on the board
/Connections/TX_DISABLE: J2.P$2 (2), J5.2; also elsewhere on the board
/Connections/V_OUT: J2.P$1 (1), J5.1; also elsewhere on the board
CH340_RX: U5.7 (RX), U6.2 (VOA)
CH340_TX: U5.6 (TX), U6.3 (VIB)
D+: J3.3 (D+), U4.1 (IO1), U5.1 (D+)
D-: J3.2 (D-), U4.6 (IO4), U5.2 (D-)
GND: C2.2, J1.3, J2.P$8 (8), J2.P$9, J2.P$10, J2.P$11, J2.P$12, J4.2, J5.8, U6.5 (GND2); also elsewhere on the board
GND2: C1.2, C3.2, J3.5 (GND), J3.6 (Shield), U4.2 (VN), U5.3 (GND), U6.4 (GND1)
unnamed: C1.1, U5.8 (V3)
TRANSPONDER_UART_RX: J2.P$3 (3), J5.3, R12.1, U6.6 (VOB)
VBUS: C3.1, J3.1 (VBUS), U4.5 (VP), U5.5 (VCC), U6.1 (VDD1)

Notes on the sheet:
This is for powering the board via mini-grabbers after SMT. That's why it has reverse polarity protection.


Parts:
C12, C13: 0.1uF; C_0603_1608Metric
Q3: BSS138; SOT-23
R8, R9, R10: 10k; R_0603_1608Metric
U1: STM32L432KBUx; QFN-32-1EP_5x5mm_P0.5mm_EP3.45x3.45mm

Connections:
+3.3V: C12.1, C13.1, R10.1, U1.1 (VDD), U1.5 (VDDA), U1.17 (VDD); also elsewhere on the board
/CAN/NRST: U1.4 (NRST); also elsewhere on the board
/CAN/SPI_CS: U1.8 (PA2); also elsewhere on the board
/CAN/SPI_MISO: U1.12 (PA6); also elsewhere on the board
/CAN/SPI_MOSI: U1.13 (PA7); also elsewhere on the board
/CAN/SPI_SCK: U1.11 (PA5); also elsewhere on the board
/Connections/MCU_UART_RX: U1.20 (PA10); also elsewhere on the board
/Connections/MCU_UART_TX: U1.19 (PA9); also elsewhere on the board
/Connections/TRANSPONDER_UART_TX: Q3.2 (S), R9.2; also elsewhere on the board
/MCU/BOOT0: R8.1, U1.31 (PH3); also elsewhere on the board
GND: C12.2, C13.2, R8.2, U1.16 (VSS), U1.32 (VSS), U1.33 (VSS); also elsewhere on the board
NMEA_RX: Q3.3 (D), R10.2, U1.9 (PA3)
NMEA_RX_EN: Q3.1 (G), R9.1, U1.14 (PB0)

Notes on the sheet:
The incoming NMEA stream from MAIANA arrives at USART2. Application firmware does not enable USART1 and must also explicitly enable this buffer in order to consume data via USART2. If the MCU enters the ROM bootloader, both USART1 and USART2 will listen for incoming commands. But since this buffer 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


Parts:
C6, C7, C8, C9, C10: 1uF; C_0603_1608Metric
D6: SMBJ16CA; DIOM4336X265N; PARTREV I2102
D8: D_Schottky; D_SOD-123
Q1: BSS138; SOT-23
Q2: AO3401A; SOT-23
R5, R6: 10k; R_0603_1608Metric
TH1: BSMD1206-050-16V; R_1206_3216Metric
U7: TJ5205SF5-5.0; SOT-23-5
U8: SE8533X2-HF; SOT-23

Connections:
+3.3V: C10.1, U8.2 (VO); also elsewhere on the board
+5V: C8.1, C9.1, U7.5 (OUT), U8.3 (VI); also elsewhere on the board
+12V: D6.2, D8.2 (A); also elsewhere on the board
/Connections/V_OUT: C7.1, R6.1, TH1.1, U7.1 (IN); also elsewhere on the board
/Power/PWR_CTRL: Q1.1 (G); also elsewhere on the board
/Power/V_IN: D8.1 (K), Q2.2 (S), R5.1; also elsewhere on the board
GND: C6.2, C7.2, C8.2, C9.2, C10.2, D6.1, Q1.2 (S), U7.2 (GND), U8.1 (GND); also elsewhere on the board
unnamed: Q1.3 (D), Q2.1 (G), R5.2
unnamed: Q2.3 (D), TH1.2
unnamed: C6.1, R6.2, U7.3 (EN)


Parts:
C4, C5: 20pF; C_0603_1608Metric
C11: 0.1uF; C_0603_1608Metric
D5: PESD1CAN-U; SOT323
R7: 10k; R_0603_1608Metric
U2: MCP2515-xST; TSSOP-20_4.4x6.5mm_P0.65mm
U3: MCP2551-I-SN; SOIC-8_3.9x4.9mm_P1.27mm
Y1: X322516MOB4SI; Crystal_SMD_3225-4Pin_3.2x2.5mm

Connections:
+3.3V: U2.20 (VDD); also elsewhere on the board
+5V: C11.1, U3.3 (VDD); also elsewhere on the board
/CAN/CAN_H: D5.2, U3.7 (CANH); also elsewhere on the board
/CAN/CAN_L: D5.1, U3.6 (CANL); also elsewhere on the board
/CAN/NRST: U2.19 (~RESET); also elsewhere on the board
/CAN/SPI_CS: U2.18 (~CS); also elsewhere on the board
/CAN/SPI_MISO: U2.17 (SO); also elsewhere on the board
/CAN/SPI_MOSI: U2.16 (SI); also elsewhere on the board
/CAN/SPI_SCK: U2.14 (SCK); also elsewhere on the board
GND: C4.2, C5.2, C11.2, D5.3, R7.2, U2.10 (VSS), U3.2 (VSS), Y1.2, Y1.4; also elsewhere on the board
unnamed: U2.2 (RXCAN), U3.4 (RXD)
unnamed: U2.1 (TXCAN), U3.1 (TXD)
unnamed: R7.1, U3.8 (Rs)
XTL1: C5.1, U2.8 (OSC2), Y1.1
XTL2: C4.1, U2.9 (OSC1), Y1.3

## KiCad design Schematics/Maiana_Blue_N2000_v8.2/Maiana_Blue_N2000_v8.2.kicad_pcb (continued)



Board: 2 copper layers, 46.0 x 46.0 mm, 54 parts (2 on the bottom side), 44 nets.

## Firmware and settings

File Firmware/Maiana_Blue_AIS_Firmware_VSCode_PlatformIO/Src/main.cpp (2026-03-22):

/*
  Copyright (c) 2016-2020 Peter Antypas

  This file is part of the MAIANA™ transponder firmware.

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
  You should have received a copy of the GNU General Public License
  along with this program.  If not, see <https://www.gnu.org/licenses/>
 */

#include "config.h"
#include "RadioManager.hpp"
#include "RXPacketProcessor.hpp"
#include "DataTerminal.hpp"
#include "TXScheduler.hpp"
#include "GPS.hpp"
#include "LEDManager.hpp"
#include "CommandProcessor.hpp"
#include "bsp.hpp"


void jump_to_bootloader()
{
  typedef void (*pFunction)(void);
  pFunction systemBootloader;

  /**
   * System bootloader for L4xx series resides at 0x1fff0000,
   * so the first 4 bytes contain the stack pointer and the next 4 contain the
   * program counter
   */
  systemBootloader = (pFunction) (*((uint32_t *)(0x1fff0004)));
  uint32_t *pp = (uint32_t*)0x1fff0000;
  uint32_t msp = *pp;
  __set_MSP(msp);

  // That's it, jump!
  systemBootloader();
}

void mainLoop()
{
  bool cliBootMode = *(uint32_t*)BOOTMODE_ADDRESS == CLI_FLAG_MAGIC;

  EventPool &pool = EventPool::instance();
  pool.init();
  EventQueue &queue = EventQueue::instance();
  queue.init();
  Configuration &config = Configuration::instance();
  config.init();
  DataTerminal::instance().init();
  CommandProcessor::instance().init();
  RXPacketProcessor packetProcessor;
  GPS::instance().init();
  TXPacketPool::instance().init();
  TXScheduler::instance().init();
  RadioManager::instance().init();
  LEDManager::instance().init();

  if ( !cliBootMode )
    {
      if ( RadioManager::instance().initialized() )
        {
          GPS::instance().enable();
          RadioManager::instance().start();
        }
    }
  else
    {
      DataTerminal::instance().write("\r\n\r\nCLI mode. Send the 'reboot' command or cycle power to exit.\r\n");
    }

  *(uint32_t*)BOOTMODE_ADDRESS = 0;

#if ENABLE_WDT
  bsp_start_wdt();
#endif
  while (1)
    {
      EventQueue::instance().dispatch();
#if ENABLE_WDT
      bsp_refresh_wdt();
#endif
      __WFI();
    }
}


int main(void)
{
  if ( *(uint32_t*)BOOTMODE_ADDRESS == DFU_FLAG_MAGIC )
    {
      *(uint32_t*)BOOTMODE_ADDRESS = 0;
      jump_to_bootloader();
    }

  // This is for debugging imprecise bus faults
  //*(uint8_t *)0xe000ed08 |= 2;

  bsp_hw_init();
  mainLoop();
  return 1;
}

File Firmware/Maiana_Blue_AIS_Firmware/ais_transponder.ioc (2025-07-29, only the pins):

Mcu.UserName=STM32L432KBUx
PA0-CK_IN.Signal=GPIO_Output
PA1.Signal=GPIO_Input
PA10.Signal=USART1_RX
PA11.Signal=GPIO_Input
PA2.Signal=GPXTI2
PA3.Signal=USART2_RX
PA4.Signal=GPIO_Output
PA5.Signal=SPI1_SCK
PA6.Signal=SPI1_MISO
PA7.Signal=SPI1_MOSI
PA8.Signal=GPIO_Input
PA9.Signal=USART1_TX
PB0.Signal=GPIO_Output
PB1.Signal=GPIO_Input

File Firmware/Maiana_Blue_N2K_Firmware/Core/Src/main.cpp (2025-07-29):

#include <bsp/bsp.hpp>
#include <NMEA2000_mcp.h>
#include "EventQueue.hpp"
#include "NMEA0183Consumer.hpp"
#include "Config.h"

#if DEBUG_LISTENER
#include "DebugMsgHandler.hpp"
#endif

int main(void)
{
  bsp_init();

  //printf("MAIANA NMEA2000 adapter started\r\n");

  EventPool::instance().init();
  EventQueue::instance().init();

  tNMEA2000 *n2k = new tNMEA2000_mcp();

#if DEBUG_LISTENER
  n2k->SetMode(tNMEA2000::N2km_ListenOnly);
  n2k->SetN2kCANReceiveFrameBufSize(256);

  DebugMsgHandler handler;
  n2k->AttachMsgHandler(&handler);
#else
  n2k->SetMode(tNMEA2000::N2km_NodeOnly, bsp_last_can_address());
  n2k->SetN2kCANSendFrameBufSize(256);
  n2k->ExtendTransmitMessages(TXMessages);
#endif

  n2k->SetProductInformation("25031501",            // Manufacturer's Model serial code
                             1,             // Manufacturer's product code
                             "MAIANA BLUE",      // Manufacturer's Model ID
                             "1.0",       // Manufacturer's Software version code
                             "1.0",         // Manufacturer's Model version
                             0);

  n2k->SetDeviceInformation(999,        // Serial number -- we don't have one
                            195,        // AIS
                            60,         // Navigation
                            2046,       // Just an unassigned value
                            0);



  if ( n2k->Open() )
    {
      //printf("Successfully opened CAN bus\r\n");
    }
  else
    {
      //printf("Failed to open CAN bus!!\r\n");
    }

#if !DEBUG_LISTENER
  NMEA0183Consumer::instance().init(n2k);
#endif

  bsp_start_wdt();
  while (1)
    {
      // Our own event loop
      EventQueue::instance().dispatch();

      // This is the NMEA2000 processing loop
      n2k->ParseMessages();

      // We have Systick at a minimum, so this is 1ms at most
      __WFI();

      // Only run this about every 10 seconds
      uint32_t c = millis();
      if ( c % 10000 == 0 && n2k->ReadResetAddressChanged() )
        {
          bsp_save_can_address(n2k->GetN2kSource());
        }

      bsp_refresh_wdt();
    }

  return 1;
}

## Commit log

2025-07-29 Initial upload. Maiana Blue Transponder Schematic v11.9.2
    [BOM_v1.csv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]
2025-07-29 Adding NMEA0183
    [1727036.psm, 1727036.stp, EDI2CAP.CFG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]
2025-07-29 Adding NMEA2000
    [M12A-05PMMR-SF7003-STP.stp, Maiana_Blue_N2000_v8.2.kicad_pcb, Maiana_Blue_N2000_v8.2.kicad_sch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]
2025-07-29 Schematics Folder
    [1727036.psm, 1727036.stp, BOM_v1.csv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]
2025-07-29 Adding UART
    [10118194-0001LF.stp, 101181940001lf.psm, EDI2CAP.CFG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]
2025-07-29 Adding Frontpanel
    [Maiana_Blue_Frontpanel_v1.0.kicad_pcb, Maiana_Blue_Frontpanel_v1.0.kicad_sch, Maiana_Blue_Frontpanel_v1.0.step]
2025-07-29 Adding CAD
    [Antenna - Btm.step, Antenna - Top.step, N0183_Case.step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]
2025-07-29 adding assembly manual, v1.0
2025-08-05 update assembly manual
2026-03-22 Add MAIANA AIS firmware build for VS Code and PlatformIO
    Introduce Firmware/Maiana_Blue_AIS_Firmware_VSCode_PlatformIO next to the
    existing STM32CubeIDE project. The tree carries the same application and BSP
    sources, wired for PlatformIO with platformio.ini environments for L4 targets
    (L432/L412), new vs legacy breakouts, and bootloader vector offset where needed.
    - Maintainer README comparing this layout to the CubeIDE sibling
    - Post-build script to copy firmware.bin into Binaries/ with an encoded name
    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
2026-03-22 PlatformIO: version Binaries/ firmware images in git
    Stop ignoring Binaries/*.bin, add current post-build image, and document
    that release binaries under Binaries/ are tracked.
    Made-with: Cursor
2026-03-22 Antenna Parts - v4.2
    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
    [Antenna - Btm.step, Antenna - Top.step, Antenna Parts v4.2.step]
2026-10-17 Drop GNSS sentences with a bad checksum instead of echoing them.
    Corrupt LC76G lines (ORE-truncated, missing bytes) were forwarded on
    USART1 and rejected by the ESP32. Validate *HH before echo or nav parse
    and count drops / echo-buffer overflows.
2026-10-17 Emit NMEA on USART1 as whole lines so AIS cannot interleave.
    drainEcho() used to yield after 48 chars or a TXE stall, then dispatch()
    wrote a blocking AIVDM/$PAI sentence mid-GSV. Finish the current echo
    line before any DataTerminal or printf write, and only yield between
    sentences.
2026-10-17 Receive LC76G bytes with polled circular DMA on USART2.
    Byte-IRQ RX lost characters when radio bit-clock and reportRSSI/SPI
    waits exceeded the 87 us character time; the ORE path then discarded
    RDR as well. DMA1 Channel 6 (request 2) runs circular without a new
    IRQ vector or a USART2 priority raise. Main and dispatch poll the
    buffer; nmea? reports $PAINMEA ore/drop counters.
2026-10-17 Refresh L432 4.5.4 binaries after the NMEA integrity fixes.
    App image 134608 -> 129552 bytes (sscanf dropped by LTO; +1024 B DMA RX
    buffer in BSS). Combined bootloader+app updated to match.
2026-10-17 Count USART FE/NE/PE and stop silently dropping nmea? replies.
    $PAINMEA still starts with the original five fields, then appends
    USART2 FE/NE/PE, USART1 FE/NE/PE, command-event alloc drops, and
    EventPool alloc failures. CLI input skips leading non-alpha junk and
    searches for a known verb so TX EMI cannot hide nmea?/sys?. The
    diagnostic sentence is written directly instead of through the 10-deep
    thread pool that was dropping replies under AIS load.
2026-10-17 Hold USART1 output around own AIS TX (FW 4.5.7).
    Class B CS starts TX at CCA bit 11 of the next clear slot after a
    packet is assigned. Gate host UART so a new sentence cannot start
    unless it will finish before that bit (30 ms pre, 8 ms post). In-flight
    lines complete; later output is buffered and flushed in order. USART1
    RX is discarded during the window so PA EMI cannot enter the CLI.
2026-10-17 Cap USART1 quiet window so deferred TX cannot stall NMEA (FW 4.5.8).
    4.5.7 held output whenever msUntilPossibleTx() <= 30 ms. An assigned
    Class B CS packet is always within one slot of the next CCA bit, so a
    busy channel kept the window open for minutes: echo_ovf ~26k, 12 s GNSS
    lag, hold overflow, glued/truncated lines.
    Hard-cap each PRE wait at 90 ms, then block PRE reopen until the
    packet is gone or RADIO_TRANSMITTING actually starts. Flush and drop
    only whole sentences. $PAINMEA fields 19-20 are hold_max_ms and
    cap_closes.
2026-10-17 Slot-align USART1 output to Class B CS CCA windows (FW 4.5.9).
    4.5.8 capped the PRE hold at 90 ms so output no longer stalled, but TX
    can still start at bit 11 of any later slot while a packet is assigned,
    cutting a sentence that was already on the wire.
    While a packet is eligible, start a sentence only if it finishes before
    the next CCA bit plus a 3 ms margin. After a CCA-no-TX decision that
    window is ~26 ms (one 82-char line at 38400). Hold only during PA-on
    plus the 8 ms post tail. No bit-clock ISR work; slot bit is snapshotted
    from the main thread. $PAINMEA 21-24 count slot-gated sentences,
    deferrals, max output latency, and lines that cannot fit a slot.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
2026-10-17 Emit AIVDM+CRLF as one unit so $PAITX cannot splice (FW 4.5.10).
    4.5.9 slot-gating stopped RF-cut GNSS lines, but RXPacketProcessor
    wrote each AIVDM as sentence then a separate CRLF. poll() could flush
    a held $PAITX onto that open line (clean glue, no FE bytes).
    NMEAEncoder now includes CRLF; AIVDM is a single write. The hold will
    not flush onto a mid-line, will not start a new sentence ahead of a
    queued one, and treats an unterminated write as an open sentence.
2026-10-17 Bound USART1 output latency while slot-gating (FW 4.5.11).
    4.5.9 field: two AIVDMs glued (same split CRLF as $PAITX) and
    max_out_lat_ms 553 with hold_max 374. An 82-char GSV plus a 3 ms
    margin had only ~2 ms after bit 11 to start; WFI plus an AIVDM/GNSS
    burst missed that window for many slots.
    Skip WFI while hold or echo is pending so the post-CCA window is
    caught. Close a split hold after 40 ms. Margin 3 ms → 2 ms.
2026-10-18 Fix pa_level range, parse, live apply, and EEPROM robustness (FW 4.5.13).
    Accept 0-127 with strict decimal parsing, select pa_mode by chip, report
    effective $PAITXC with a stored flag, apply live (or after TX), and make
    EEPROM writes verify without stalling the main loop.
2026-10-18 Gate nmea? diagnostics behind NMEA_DIAG (FW 4.5.14).
    Keep NMEA integrity (hold/queue, slot alignment, checksum, error-flag
    clearing) always on. Counter storage, increments, and the nmea? command
    compile only when NMEA_DIAG=1.

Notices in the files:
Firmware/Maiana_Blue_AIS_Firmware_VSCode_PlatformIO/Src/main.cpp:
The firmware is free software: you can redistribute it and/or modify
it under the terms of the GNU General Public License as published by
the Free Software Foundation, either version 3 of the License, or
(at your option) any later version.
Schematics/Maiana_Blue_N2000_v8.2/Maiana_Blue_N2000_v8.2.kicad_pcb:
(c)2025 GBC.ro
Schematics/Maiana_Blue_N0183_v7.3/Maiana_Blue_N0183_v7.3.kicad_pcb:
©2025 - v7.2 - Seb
